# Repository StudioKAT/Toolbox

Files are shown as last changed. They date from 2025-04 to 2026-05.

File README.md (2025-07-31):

# Toolbox

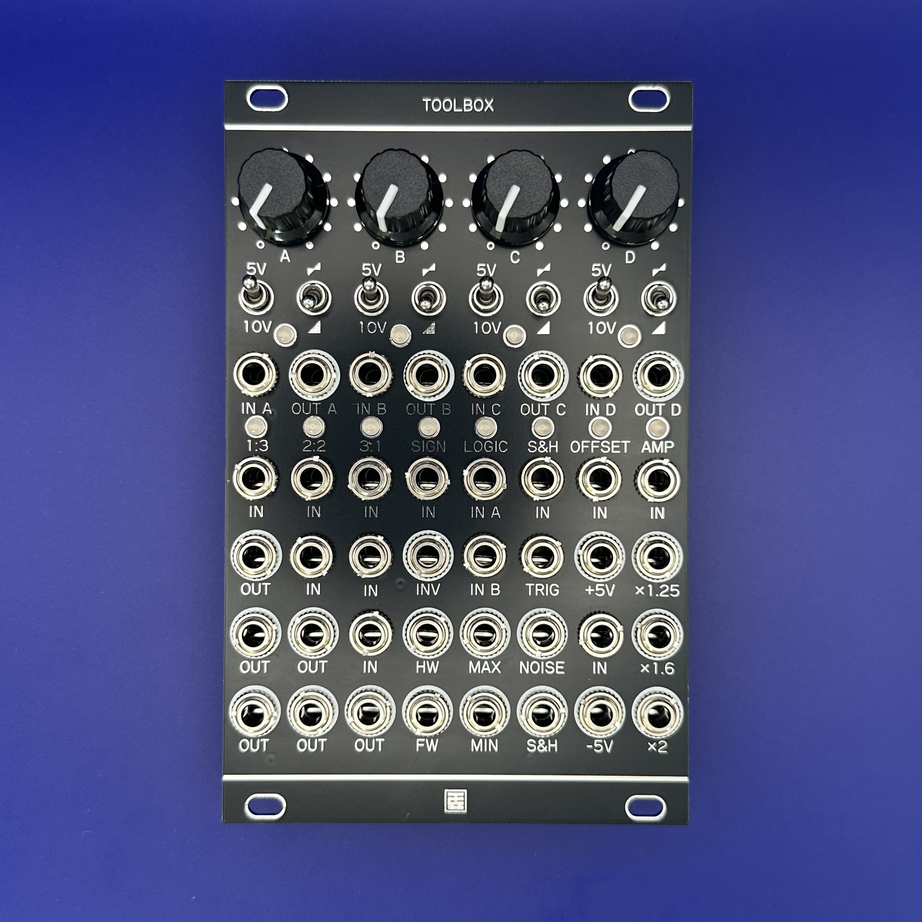
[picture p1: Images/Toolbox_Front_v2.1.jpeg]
Toolbox Front


## 概要 / Overview

**Toolbox** は、16HPサイズの中にモジュラーシンセに必要な多彩なユーティリティ機能を凝縮した多機能ツールボックスモジュールです。  
Mutable Instruments の「Shades」「Links」「Kinks」をベースにしつつ、独自の機能追加を行いました。

主な機能：
- オーディオ/CVミキサー（加算・減算）
- CVへのオフセット追加(5V/10V)・極性反転
- 1:3 バッファード・マルチプル
- 2:2 ユニティミキサー
- 3:1 アベレージミキサー（各チャンネルのゲイン = 1/3）
- SIGNセクション：インバーター / 半波整流 / 全波整流
- LOGICセクション：アナログOR / アナログAND
- S&Hセクション：サンプル＆ホールド / ホワイトノイズ出力
- OFFSET：±5V ↔ 0〜10Vの変換（5Vオフセット）
- AMP：CVやオーディオ信号の増幅  
  - 8V → 10V（x1.25）  
  - 5V → 8V（x1.6）  
  - 5V → 10V（x2）

**Toolbox** is a multifunction utility module that packs a wide range of essential modular synthesis tools into a compact 16HP format.  
It is based on Mutable Instruments' *Shades*, *Links*, and *Kinks*, with several added original features.

Key features include:
- Audio/CV mixer (for both addition and subtraction)
- Offset(5V/10V) and polarity inversion for CV signals
- 1:3 buffered multiple
- 2:2 unity mixer
- 3:1 averaging mixer (each channel gain = 1/3)
- SIGN section: inverter / half-wave rectifier / full-wave rectifier
- LOGIC section: analog OR / analog AND gates
- S&H section: sample & hold circuit / white noise output
- OFFSET: 5V offset converter for ±5V ↔ 0–10V signal conversion
- AMP: amplification of CV and audio signals  
  - 8V → 10V (x1.25)  
  - 5V → 8V (x1.6)  
  - 5V → 10V (x2)

## 仕様 / Spec
- Format: Eurorack
- Function: Multi tools
- Current needs: +12V: 130mA, -12V: 130mA
- Width: 16 HP
- Depth: 25mm (including power connector)

## 販売 / Sales

StudioKATオフィシャルショップで販売しています。(日本国内限定)  
https://www.studiokat.jp/items/106541624

## ライセンス / License

この作品は [Creative Commons 表示 - 継承 4.0 国際 (CC BY-SA 4.0)](https://creativecommons.org/licenses/by-sa/4.0/deed.ja) の下でライセンスされています。  
This work is licensed under the [Creative Commons Attribution-ShareAlike 4.0 International License](https://creativecommons.org/licenses/by-sa/4.0/).

## クレジット / Credits

- Designed by : StudioKAT
- Website : https://www.studiokat.jp/
- GitHub : https://github.com/StudioKAT
- X(Twitter) : https://x.com/StudioKAT_synth
- Instagram : https://www.instagram.com/studiokat_modular/

## 更新履歴 / Changelog

- `2025-05-28` v1.0 Released 
- `2025-07-31` v2.1 Released  
オペアンプ変更、ホワイトノイズ切り替え機能追加、リファレンス電源回路変更

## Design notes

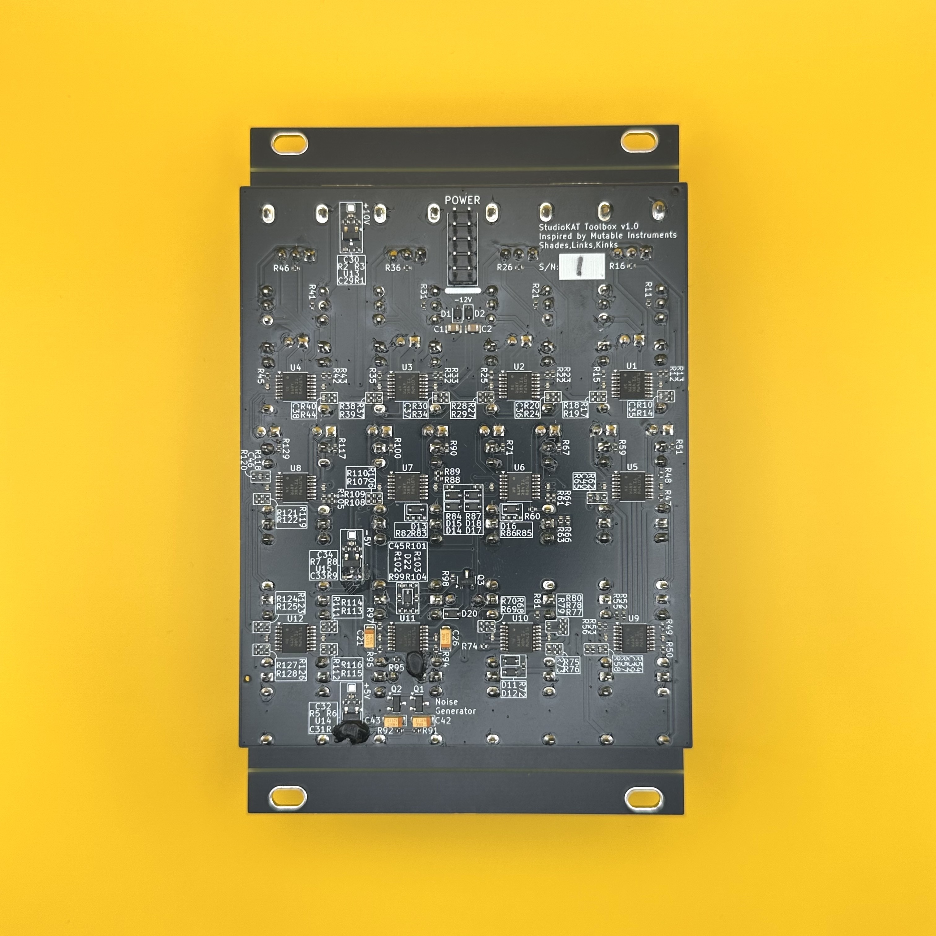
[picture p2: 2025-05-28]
Images/Toolbox_Back.jpeg

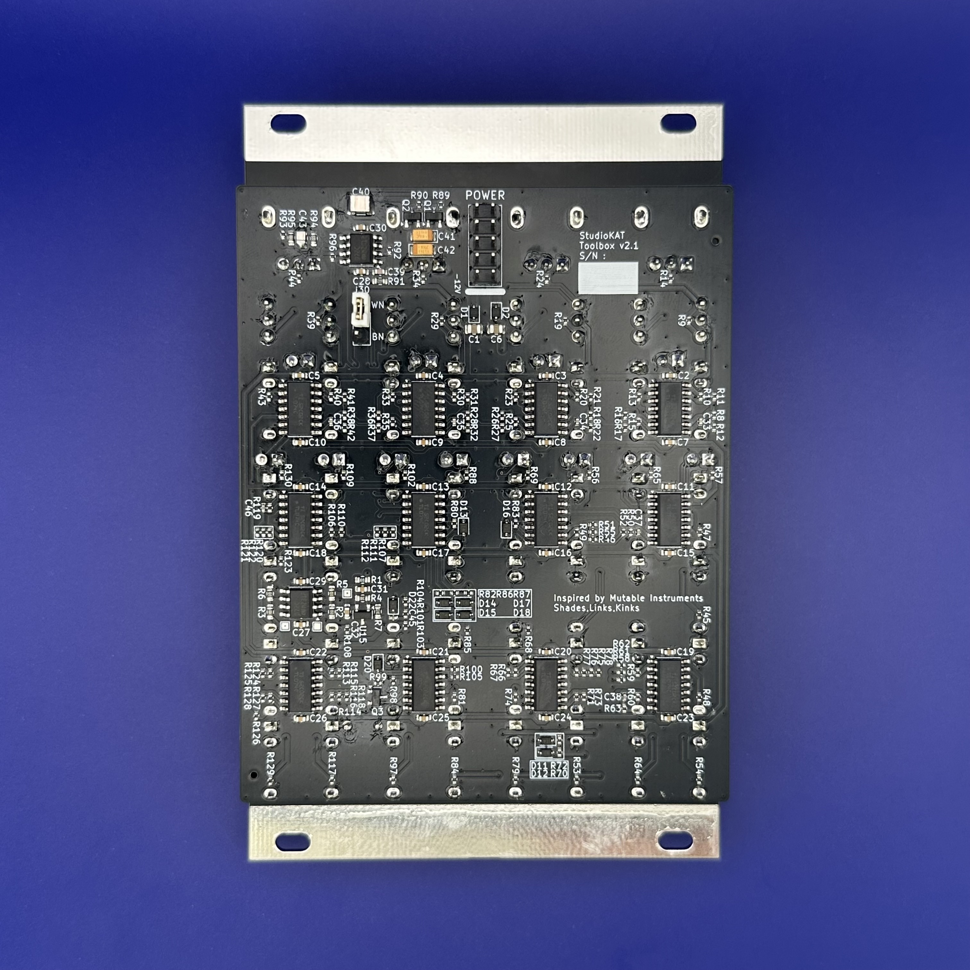
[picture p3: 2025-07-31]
Images/Toolbox_Back_v2.1.jpeg

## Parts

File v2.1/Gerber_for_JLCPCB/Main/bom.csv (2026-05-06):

Designator | Footprint | Quantity | Value | LCSC Part #
C1, C6 | 0805 | 2 | 22uF | C45783
C10, C11, C12, C13, C14, C15, C16, C17, C18, C19, C2, C20, C21, C22, C23, C24, C25, C26, C27, C28, C29, C3, C30, C31, C32, C4, C5, C7, C8, C9 | 0603 | 30 | 100nF | C14663
C33, C34, C35, C36 | 0402 | 4 | 22p | C1555
C37, C38, C46 | 0402 | 3 | 10p | C32949
C39 | 0603 | 1 | 22pF | C1653
C40 | 1210 | 1 | 0.1uF/16V
C41, C42 | CP_EIA-3216-18_Kemet-A | 2 | 10u | C7171
C43 | 0805 | 1 | 0.01uF/16V
C44 | C_Rect_L7.2mm_W2.5mm_P5.00mm_FKS2_FKP2_MKS2_MKP2 | 1 | 10n
C45 | 0402 | 1 | 100p | C1546
D1, D2 | D_SOD-323 | 2 | 1N5819WS | C64886
D10, D19, D21, D23, D24, D3, D4, D5, D6, D7, D8, D9 | LED_D3.0mm | 12 | LED_Dual_Bidirectional
D11, D12, D13, D14, D15, D16, D17, D18, D20, D22 | D_SOD-323 | 10 | 1N4148WS | C2128
J1 | PinHeader_2x05_2.54mm_Europower | 1 | POWER
J10 | AudioJack_PJ301M-12 | 1 | Links_1to3_OUT1
J11 | AudioJack_PJ301M-12 | 1 | Links_1to3_IN
J12 | AudioJack_PJ301M-12 | 1 | Links_3to1_IN1
J13 | AudioJack_PJ301M-12 | 1 | Links_1to3_OUT2
J14 | AudioJack_PJ301M-12 | 1 | Links_3to1_IN2
J15 | AudioJack_PJ301M-12 | 1 | Links_3to1_OUT
J16 | AudioJack_PJ301M-12 | 1 | Links_1to3_OUT3
J17 | AudioJack_PJ301M-12 | 1 | Links_3to1_IN3
J18 | AudioJack_PJ301M-12 | 1 | Links_2to2_IN1
J19 | AudioJack_PJ301M-12 | 1 | Links_2to2_IN2
J2 | AudioJack_PJ301M-12 | 1 | OUT_1
J20 | AudioJack_PJ301M-12 | 1 | Links_2to2_OUT1
J21 | AudioJack_PJ301M-12 | 1 | Links_2to2_OUT2
J22 | AudioJack_PJ301M-12 | 1 | Kinks_IN
J23 | AudioJack_PJ301M-12 | 1 | Kinks_OUT_INV
J24 | AudioJack_PJ301M-12 | 1 | Kinks_OUT_HW
J25 | AudioJack_PJ301M-12 | 1 | Kinks_OUT_FW
J26 | AudioJack_PJ301M-12 | 1 | Kinks_OUT_MAX
J27 | AudioJack_PJ301M-12 | 1 | Kinks_IN_A
J28 | AudioJack_PJ301M-12 | 1 | Kinks_IN_B
J29 | AudioJack_PJ301M-12 | 1 | Kinks_OUT_MIN
J3 | AudioJack_PJ301M-12 | 1 | IN_1
J30 | PinHeader_1x03_P2.54mm_Vertical | 1 | Jumper
J31 | AudioJack_PJ301M-12 | 1 | Kinks_OUT_Noise
J32 | AudioJack_PJ301M-12 | 1 | Kinks_OUT_S&H
J33 | AudioJack_PJ301M-12 | 1 | Kinks_S&H_IN
J34 | AudioJack_PJ301M-12 | 1 | Kinks_S&H_TRIG
J35 | AudioJack_PJ301M-12 | 1 | OUT_+10V
J36 | AudioJack_PJ301M-12 | 1 | IN_±5V
J37 | AudioJack_PJ301M-12 | 1 | IN_+10V
J38 | AudioJack_PJ301M-12 | 1 | OUT_±5V
J39 | AudioJack_PJ301M-12 | 1 | IN
J4 | AudioJack_PJ301M-12 | 1 | OUT_2
J40 | AudioJack_PJ301M-12 | 1 | OUT_x1.25
J41 | AudioJack_PJ301M-12 | 1 | OUT_x1.6
J42 | AudioJack_PJ301M-12 | 1 | OUT_x2
J5 | AudioJack_PJ301M-12 | 1 | IN_2
J6 | AudioJack_PJ301M-12 | 1 | OUT_3
J7 | AudioJack_PJ301M-12 | 1 | IN_3
J8 | AudioJack_PJ301M-12 | 1 | OUT_4
J9 | AudioJack_PJ301M-12 | 1 | IN_4
Q1, Q2 | SOT-23 | 2 | 2SC1815 | C20069143
Q3 | SOT-23 | 1 | MMBFJ310 | C33416
R1 | 0603 | 1 | 1K | C21190
R10, R103, R104, R106, R107, R11, R110, R111, R112, R113, R114, R115, R116, R118, R119, R121, R127, R14, R15, R16, R17, R18, R19, R20, R21, R24, R25, R26, R27, R28, R29, R30, R31, R34, R35, R36, R37, R38, R39, R40, R41, R44, R46, R50, R51, R52, R55, R58, R59, R60, R61, R62, R70, R73, R75, R76, R8, R9, R92 | 0402 | 59 | 100K | C25741
R100, R86, R87, R98, R99 | 0402 | 5 | 1M | C26083
R101, R105 | 0402 | 2 | 10K | C25744
R102, R109, R12, R13, R130, R22, R23, R32, R33, R42, R43, R56, R57, R65, R69, R88 | 0402 | 16 | 1K | C11702
R108, R117, R123, R126, R129, R45, R48, R53, R54, R63, R64, R68, R74, R79, R81, R84, R93, R96, R97 | 0402 | 19 | 100R | C25076
R120 | 0402 | 1 | 150K | C25755
R122, R124 | 0402 | 2 | 120K | C25750
R125 | 0402 | 1 | 75K | C25798
R128 | 0402 | 1 | 49.9K | C25897
R2, R5, R6 | 0603 | 3 | 100K | C25803
R3, R91 | 0603 | 2 | 200K | C25811
R4, R7 | 0603 | 2 | 10K | C25804
R47 | 0402 | 1 | 10M | C26082
R49 | 0402 | 1 | 33K | C25779
R66, R67, R71, R72, R77, R78 | 0402 | 6 | 200K | C25764
R80, R82, R83, R85 | 0402 | 4 | 220K | C25767
R89 | 0402 | 1 | 470K | C25790
R90 | 0402 | 1 | 4.7K | C25900
R94 | 0603 | 1 | 2.2K | C4190
R95 | 0603 | 1 | 2K | C22975
RV1, RV2, RV3, RV4 | Potentiometer_RV09 | 4 | B10K
SW1, SW2, SW3, SW4, SW5, SW6, SW7, SW8 | ToggleSwitch_2MS1-T2-B4-M2-Q-E-S | 8 | SW_SPDT
TP1 | TestPoint_Pad_1.0x1.0mm | 1 | +5V_TP
TP2 | TestPoint_Pad_1.0x1.0mm | 1 | -5V_TP
TP3 | TestPoint_Pad_1.0x1.0mm | 1 | +10V_TP
U1, U10, U11, U12, U2, U3, U4, U5, U6, U7, U8, U9 | SOIC-14_3.9x8.7mm_P1.27mm | 12 | TL074CDR | C12594
U13, U14 | SOIC-8_3.9x4.9mm_P1.27mm | 2 | TL072CDT | C6961
U15 | SOT-23 | 1 | CJ431 | C3113

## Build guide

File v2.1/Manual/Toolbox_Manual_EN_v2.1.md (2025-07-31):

# Toolbox Manual (English)

Toolbox Front

## Overview

**Toolbox** is a multi-functional utility module packed into a 16HP Eurorack format.  
Inspired by Mutable Instruments' "Shades", "Links", and "Kinks", this module adds original functionality and extends utility capabilities for both audio and CV.

### Key Features:
- Audio/CV mixer (sum/subtract)  
- CV offset generator (+5V/+10V), polarity inversion  
- 1:3 buffered multiple  
- 2:2 unity mixer  
- 3:1 average mixer (each input gain = 1/3)  
- SIGN section: inverter / half-wave rectifier / full-wave rectifier  
- LOGIC section: analog OR / analog AND  
- S&H section: sample & hold / white noise generator  
- OFFSET section: ±5V ↔ 0–10V converter (±5V shift)  
- AMP section: CV or audio gain boost for envelope scaling

---

## Specifications

- **Format**: Eurorack  
- **Width**: 16 HP  
- **Depth**: 25 mm  
- **Power Consumption**: +12V: 130mA / -12V: 130mA  

> **IMPORTANT**: Connect the ribbon cable with the red stripe aligned to -12V.  
> Incorrect connection can permanently damage the module.  
> **Always check cable orientation before powering on.**

---

## Functional Sections

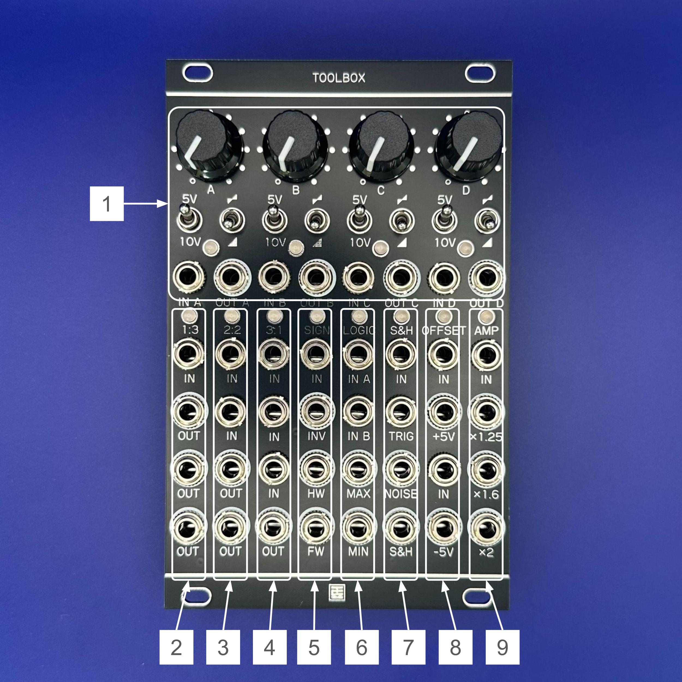
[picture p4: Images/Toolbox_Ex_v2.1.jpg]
explanation


1. **Attenuator / Offset / Mixer**  
   4-channel audio/CV mixer and attenuator section.  
   Normalized to +5V or +10V when no input is patched (switchable).  
   Each channel can be switched between attenuator and attenuverter modes.  
   Outputs are internally daisy-chained.

2. **1:3**  
   1 input, 3 output buffered multiple.

3. **2:2**  
   Unity gain mixer: two inputs are summed and distributed to two outputs.

4. **3:1**  
   3-input average mixer with 1/3 gain per channel—ideal for mixing hot oscillator signals to prevent clipping.

5. **SIGN**  
   Signal inverter and wave rectification section.  
   Provides half-wave and full-wave rectification, including 0V clipping and phase inversion of negative voltages.

6. **LOGIC**  
   Outputs the maximum (analog OR) and minimum (analog AND) of two input voltages.

7. **S&H**  
   When a trigger is received at TRIG IN, the voltage at IN is sampled and held at the output.  
   Internally normalized to white noise for random voltage generation.  
   The NOISE OUT provides continuous white noise independent from the S&H output.

8. **OFFSET**  
   Top: adds +5V to the input signal  
   Bottom: subtracts 5V from the input signal  
   Useful for converting ±5V pitch signals to 0–10V (e.g., Moog).

9. **AMP**  
   Amplifies CV or audio signals to scale envelope voltages.  
   Preset gain ratios:  
   - 8V → 10V (×1.25)  
   - 5V → 8V (×1.6)  
   - 5V → 10V (×2)

---

> All LEDs light up **green** for positive output and **red** for negative output.

---

### v2.1 Update
You can select the type of noise used in the Sample & Hold (S&H) section via the jumper located on the back panel.
- Upper position: White noise (default)
- Lower position: Blue noise (brighter tonal character)
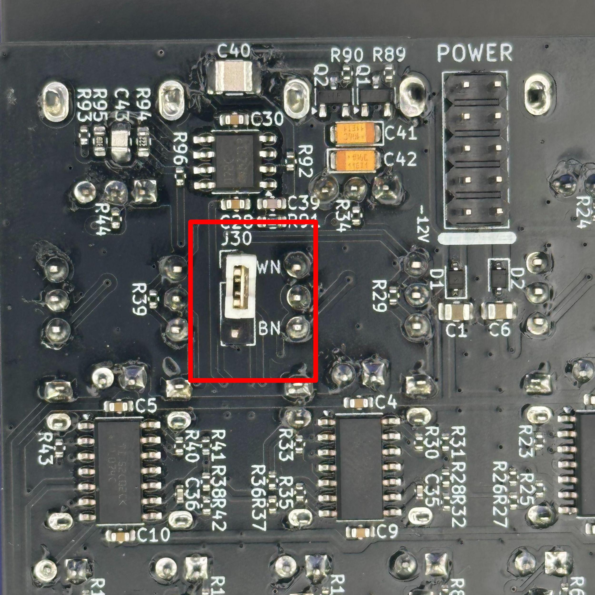
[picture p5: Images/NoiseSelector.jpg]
NoiseSelector


## License

This work is licensed under a [Creative Commons Attribution-ShareAlike 4.0 International License (CC BY-SA 4.0)](https://creativecommons.org/licenses/by-sa/4.0/).

---

## Credits

- **Designed by**: StudioKAT  
- **Website**: [https://www.studiokat.jp/](https://www.studiokat.jp/)  
- **GitHub**: [https://github.com/StudioKAT](https://github.com/StudioKAT)  
- **X (Twitter)**: [https://x.com/StudioKAT_synth](https://x.com/StudioKAT_synth)  
- **Instagram**: [https://www.instagram.com/studiokat_modular/](https://www.instagram.com/studiokat_modular/)

---

## Changelog

- `2025-05-28`: v1.0 Released

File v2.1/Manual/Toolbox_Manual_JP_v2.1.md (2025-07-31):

# Toolbox マニュアル（日本語）

Toolbox Front

## 概要

**Toolbox** は、16HPの中にモジュラーシンセに必要な多彩なユーティリティ機能を凝縮した多機能ツールボックスモジュールです。  
Mutable Instruments の「Shades」「Links」「Kinks」をベースに、独自の機能追加が施されています。

### 主な機能：
- オーディオ／CVミキサー（加算・減算）  
- CVへのオフセット追加（5V／10V）、極性反転  
- 1:3 バッファード・マルチプル  
- 2:2 ユニティミキサー  
- 3:1 アベレージミキサー（各チャンネルのゲイン = 1/3）  
- SIGNセクション：インバーター／半波整流／全波整流  
- LOGICセクション：アナログOR／アナログAND  
- S&Hセクション：サンプル＆ホールド／ホワイトノイズ出力  
- OFFSET：±5V ↔ 0〜10V 変換（5Vオフセット）  
- AMP：CVやオーディオ信号の電圧拡張

---

## 仕様

- **フォーマット**：Eurorack  
- **幅**：16 HP  
- **奥行き**：25 mm  
- **消費電流**：+12V: 130mA / -12V: 130mA  

> ※ ケーブルの赤いラインが -12V に接続されていることを確認してください。  
> 誤接続するとモジュールが故障する可能性があります。  
> **電源投入前にケーブルの向きを必ずご確認ください。**

---

## 各部の機能

explanation

1. **Attenuator / Offset / Mixer**  
   4チャンネルのCV／オーディオ信号を処理できるミキサー・アッテネーターです。  
   未接続時には+5Vまたは+10Vがノーマライズされ、固定電圧出力として使用可能。切替スイッチ付き。  
   スイッチでアッテネーター／アッテヌバーターの切替も可能。  
   出力は内部的にデイジーチェーン接続されています。

2. **1:3**  
   バッファー付きの1入力3出力マルチプルです。

3. **2:2**  
   2入力の加算結果を2つのアウトへ出力するユニティゲインミキサーです。

4. **3:1**  
   各入力のゲインを1/3に設定した3入力ミキサーです。  
   オシレーターなど、クリッピングしやすい信号のミキシングに適しています。

5. **SIGN**  
   信号インバーターと半波／全波整流器のセクションです。  
   信号を0Vでクリップ、もしくは負電圧成分を反転する処理を行います。

6. **LOGIC**  
   入力された2信号の最大値（アナログOR）および最小値（アナログAND）を出力します。

7. **S&H**  
   トリガー信号が入力されるたびにINの電圧をサンプルし、保持して出力します。  
   INには内部的にホワイトノイズがノーマライズされています。  
   NOISE OUTはS&Hとは独立したノイズ出力として使用できます。

8. **OFFSET**  
   上段：入力信号に+5Vを加算  
   下段：入力信号から5Vを減算  
   Moogの±5Vピッチ信号を0～10Vへ変換するなどの用途に便利です。

9. **AMP**  
   CVまたはオーディオ信号を一定倍率で増幅します。  
   エンベロープ電圧変換に最適な倍率設定：  
   - 8V → 10V（×1.25）  
   - 5V → 8V（×1.6）  
   - 5V → 10V（×2）

---

> すべてのLEDは、出力がプラスの場合は緑、マイナスの場合は赤に点灯します。

---

### v2.1 Update
背面のジャンパーピンで、S&H（サンプル＆ホールド）セクションに使用するノイズの種類を選択できます。
- 上側：ホワイトノイズ（デフォルト）
- 下側：ブルーノイズ（より明るい音色のノイズ）
NoiseSelector

## ライセンス

この作品は [Creative Commons 表示 - 継承 4.0 国際 (CC BY-SA 4.0)](https://creativecommons.org/licenses/by-sa/4.0/deed.ja) の下でライセンスされています。

---

## クレジット

- **Designed by**：StudioKAT  
- **Website**：[https://www.studiokat.jp/](https://www.studiokat.jp/)  
- **GitHub**：[https://github.com/StudioKAT](https://github.com/StudioKAT)  
- **X（旧Twitter）**：[https://x.com/StudioKAT_synth](https://x.com/StudioKAT_synth)  
- **Instagram**：[https://www.instagram.com/studiokat_modular/](https://www.instagram.com/studiokat_modular/)

---

## 更新履歴

- `2025-05-28`：v1.0 リリース  
- `2025-07-31`：v2.1 リリース

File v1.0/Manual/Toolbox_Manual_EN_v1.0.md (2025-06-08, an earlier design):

# Toolbox Manual (English)

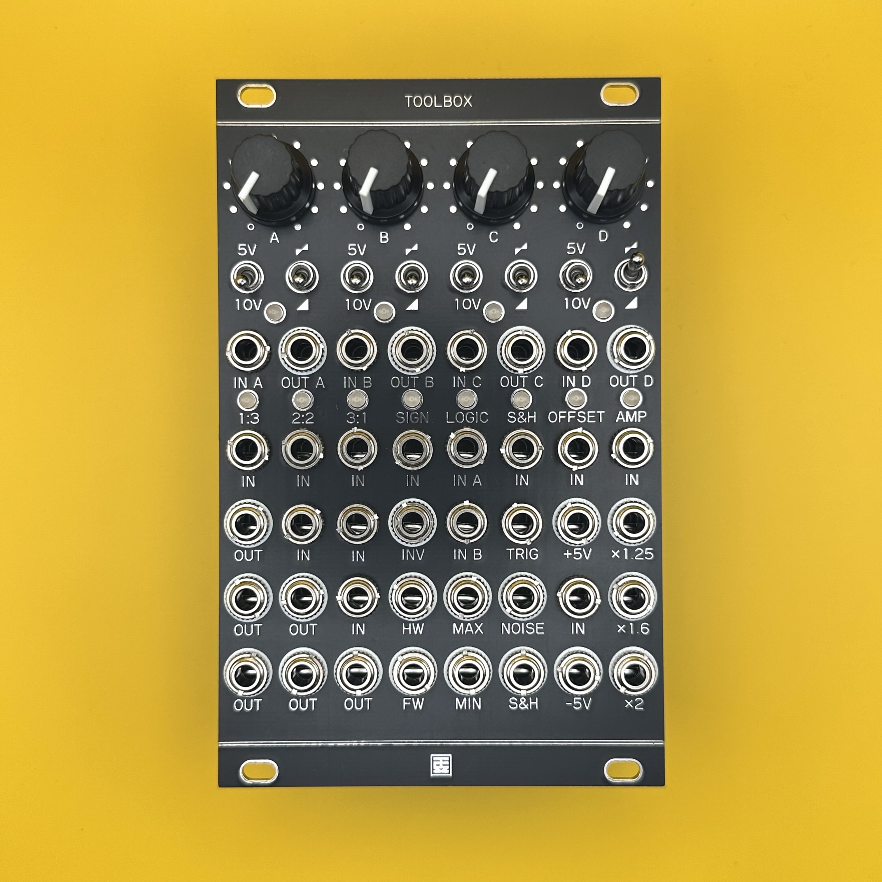
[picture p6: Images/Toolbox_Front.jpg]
Toolbox Front


## Overview

**Toolbox** is a multi-functional utility module packed into a 16HP Eurorack format.  
Inspired by Mutable Instruments' "Shades", "Links", and "Kinks", this module adds original functionality and extends utility capabilities for both audio and CV.

### Key Features:
- Audio/CV mixer (sum/subtract)  
- CV offset generator (+5V/+10V), polarity inversion  
- 1:3 buffered multiple  
- 2:2 unity mixer  
- 3:1 average mixer (each input gain = 1/3)  
- SIGN section: inverter / half-wave rectifier / full-wave rectifier  
- LOGIC section: analog OR / analog AND  
- S&H section: sample & hold / white noise generator  
- OFFSET section: ±5V ↔ 0–10V converter (±5V shift)  
- AMP section: CV or audio gain boost for envelope scaling

---

## Specifications

- **Format**: Eurorack  
- **Width**: 16 HP  
- **Depth**: 25 mm  
- **Power Consumption**: +12V: 160mA / -12V: 160mA  

> **IMPORTANT**: Connect the ribbon cable with the red stripe aligned to -12V.  
> Incorrect connection can permanently damage the module.  
> **Always check cable orientation before powering on.**

---

## Functional Sections

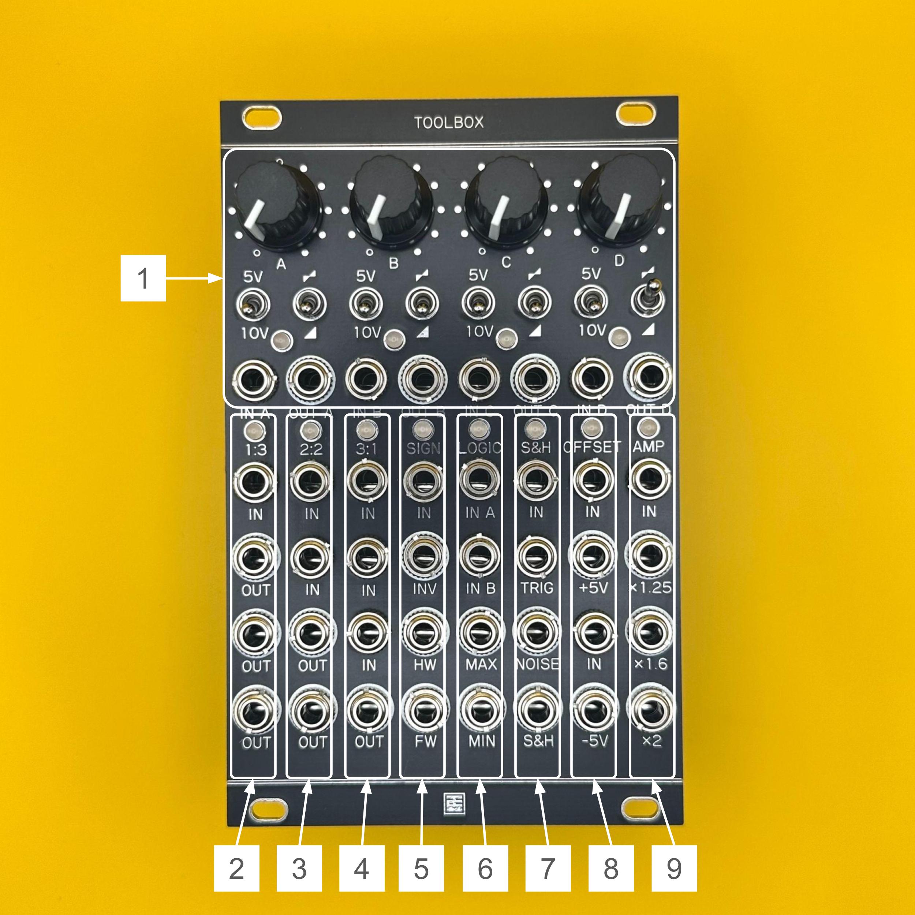
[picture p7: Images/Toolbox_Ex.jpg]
explanation


1. **Attenuator / Offset / Mixer**  
   4-channel audio/CV mixer and attenuator section.  
   Normalized to +5V or +10V when no input is patched (switchable).  
   Each channel can be switched between attenuator and attenuverter modes.  
   Outputs are internally daisy-chained.

2. **1:3**  
   1 input, 3 output buffered multiple.

3. **2:2**  
   Unity gain mixer: two inputs are summed and distributed to two outputs.

4. **3:1**  
   3-input average mixer with 1/3 gain per channel—ideal for mixing hot oscillator signals to prevent clipping.

5. **SIGN**  
   Signal inverter and wave rectification section.  
   Provides half-wave and full-wave rectification, including 0V clipping and phase inversion of negative voltages.

6. **LOGIC**  
   Outputs the maximum (analog OR) and minimum (analog AND) of two input voltages.

7. **S&H**  
   When a trigger is received at TRIG IN, the voltage at IN is sampled and held at the output.  
   Internally normalized to white noise for random voltage generation.  
   The NOISE OUT provides continuous white noise independent from the S&H output.

8. **OFFSET**  
   Top: adds +5V to the input signal  
   Bottom: subtracts 5V from the input signal  
   Useful for converting ±5V pitch signals to 0–10V (e.g., Moog).

9. **AMP**  
   Amplifies CV or audio signals to scale envelope voltages.  
   Preset gain ratios:  
   - 8V → 10V (×1.25)  
   - 5V → 8V (×1.6)  
   - 5V → 10V (×2)

---

> All LEDs light up **green** for positive output and **red** for negative output.

---

## License

This work is licensed under a [Creative Commons Attribution-ShareAlike 4.0 International License (CC BY-SA 4.0)](https://creativecommons.org/licenses/by-sa/4.0/).

---

## Credits

- **Designed by**: StudioKAT  
- **Website**: [https://www.studiokat.jp/](https://www.studiokat.jp/)  
- **GitHub**: [https://github.com/StudioKAT](https://github.com/StudioKAT)  
- **X (Twitter)**: [https://x.com/StudioKAT_synth](https://x.com/StudioKAT_synth)  
- **Instagram**: [https://www.instagram.com/studiokat_modular/](https://www.instagram.com/studiokat_modular/)

---

## Changelog

- `2025-05-28`: v1.0 Released

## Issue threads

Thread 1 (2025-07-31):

[Toolbox] CJ431 5V shunt regulators are getting VERY hot

KeLaiFu, 2025-07-31:
I've built the beautiful Toolbox module, using the same assembly files posted in the repository and upon test, the 2 5v CJ431's are getting very hot, very fast.
I havn't fully tested the module as I am afraid they will burn out given enough time, but the 5V test points both give the correct voltage and a few other things I have quickly tested seem to be working, so other than the hot regulators, so far it seems to be working.

StudioKAT, 2025-07-31:
I'm aware of the heat issue with the CJ431s. In the production version, I addressed this by changing resistors R1, R4, and R9 from 100Ω to 1kΩ.
Only the KiCAD project had been updated—I had forgotten to update the Gerber files accordingly.
I've now replaced the affected files.

Closed 2025-07-31.

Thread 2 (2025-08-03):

[toolbox] v1 Kink S&H LED is always lit

KeLaiFu, 2025-08-03:
Thanks for responding to my previous issue, I switched out the resistors and the problem went away thankfully

However, as I continue the assembly I noticed that the light for the Kinks S&H circuit is permanently Illuminated.

I don't think this is normal, so could you advise me on what could be causing this?

Thanks again

Closed 2025-08-09.

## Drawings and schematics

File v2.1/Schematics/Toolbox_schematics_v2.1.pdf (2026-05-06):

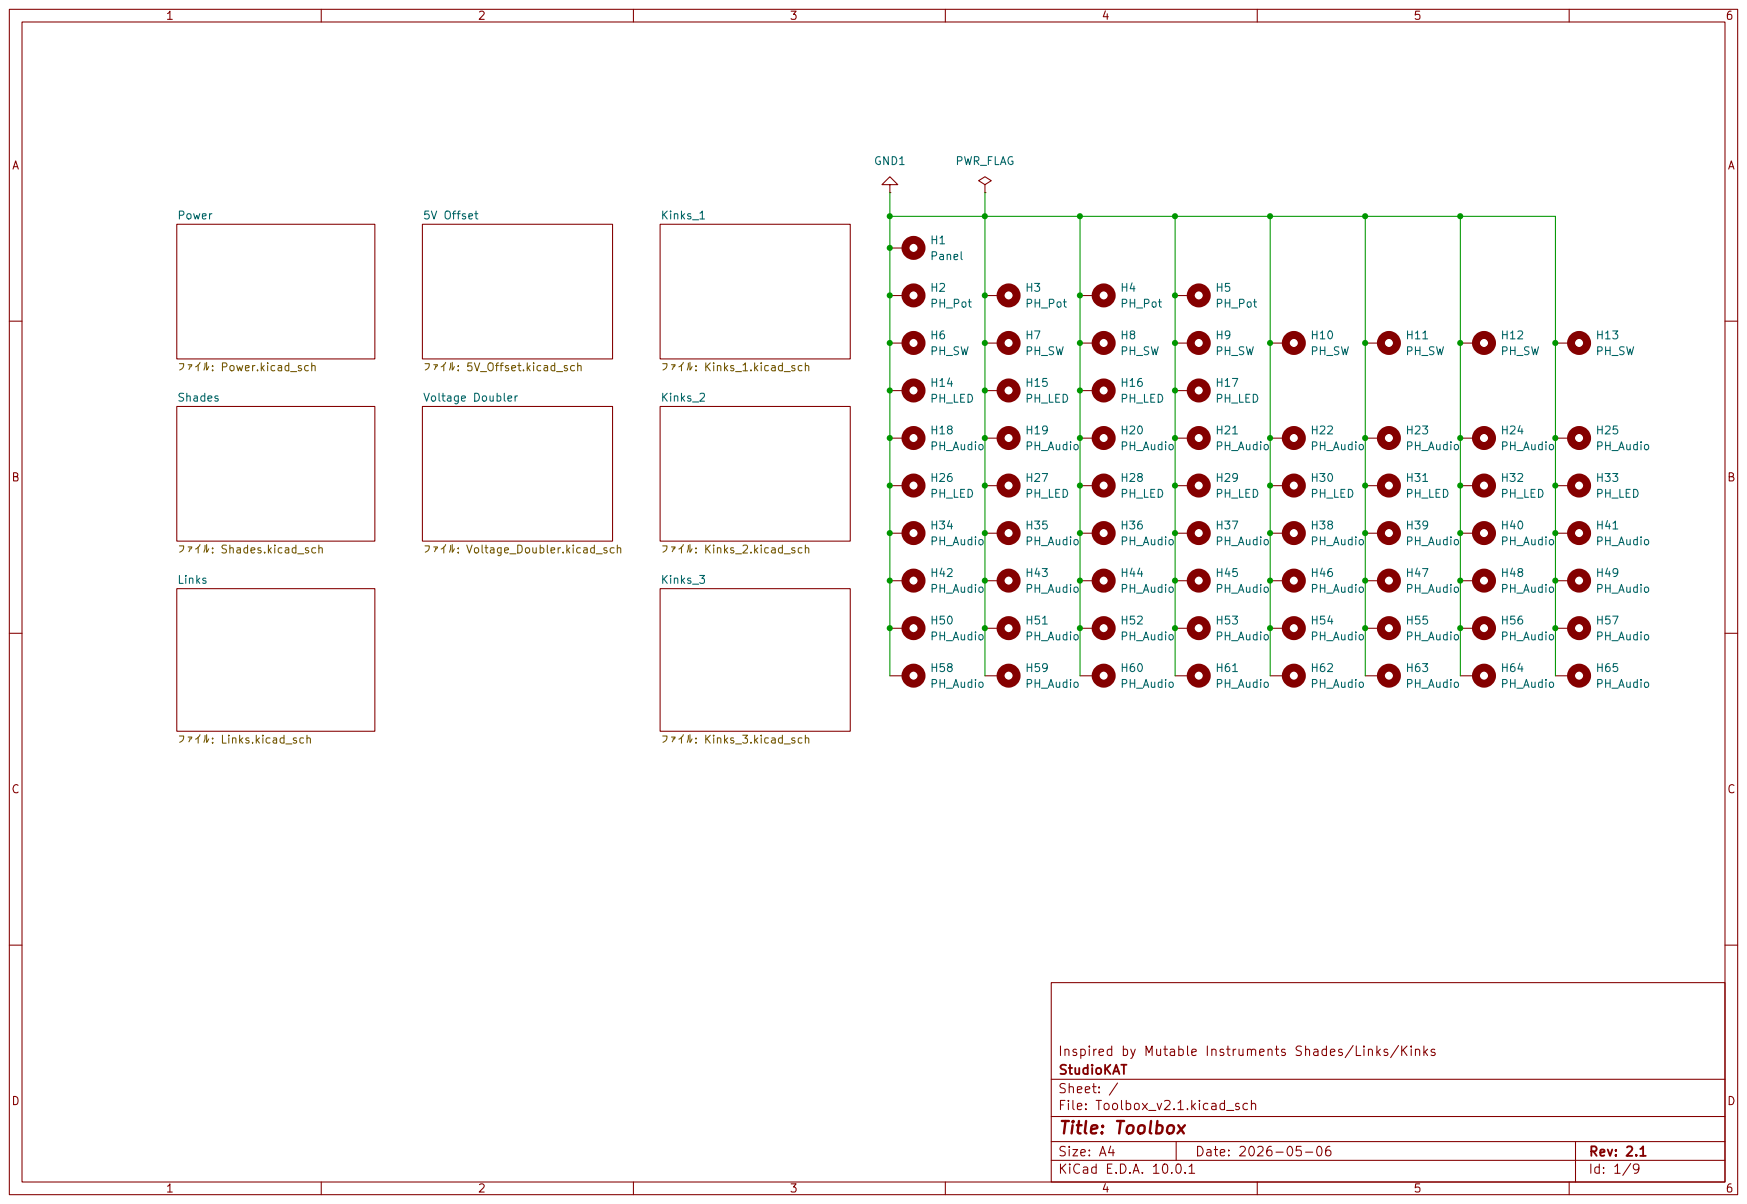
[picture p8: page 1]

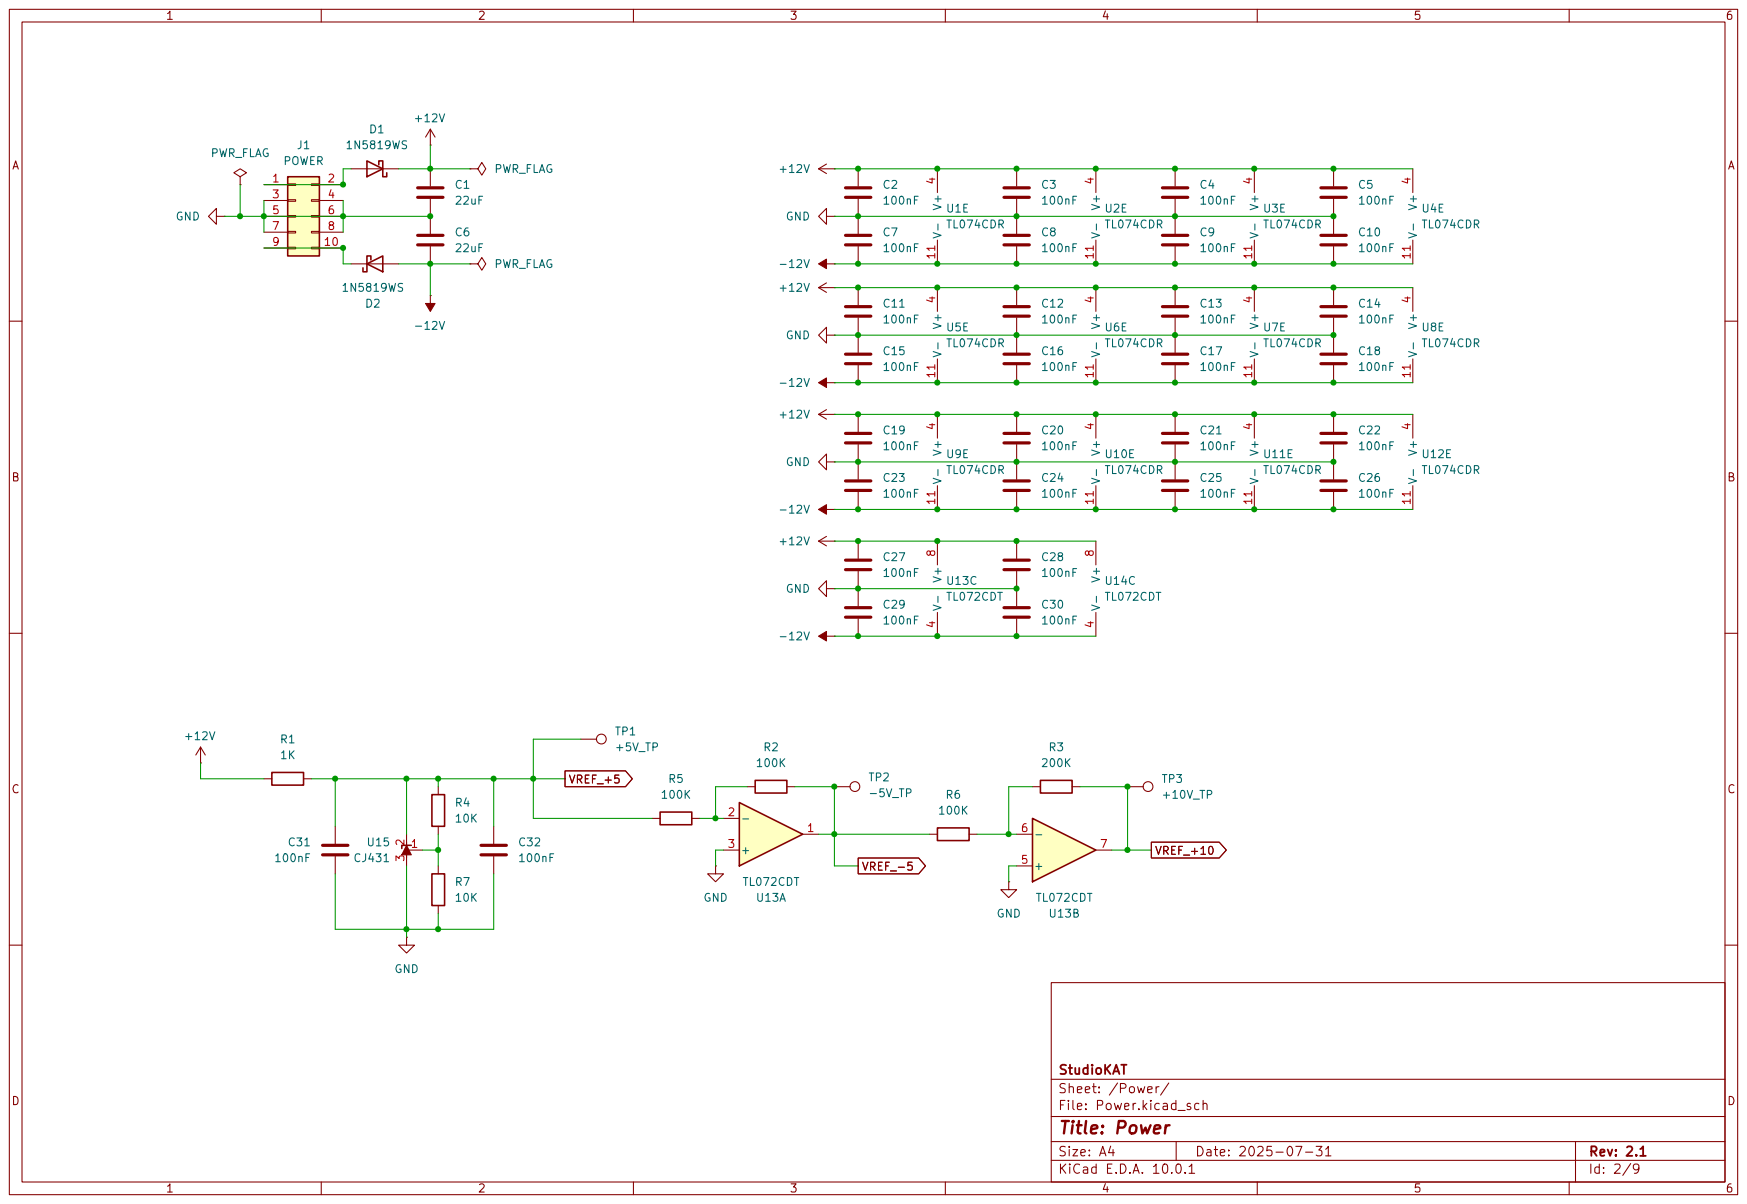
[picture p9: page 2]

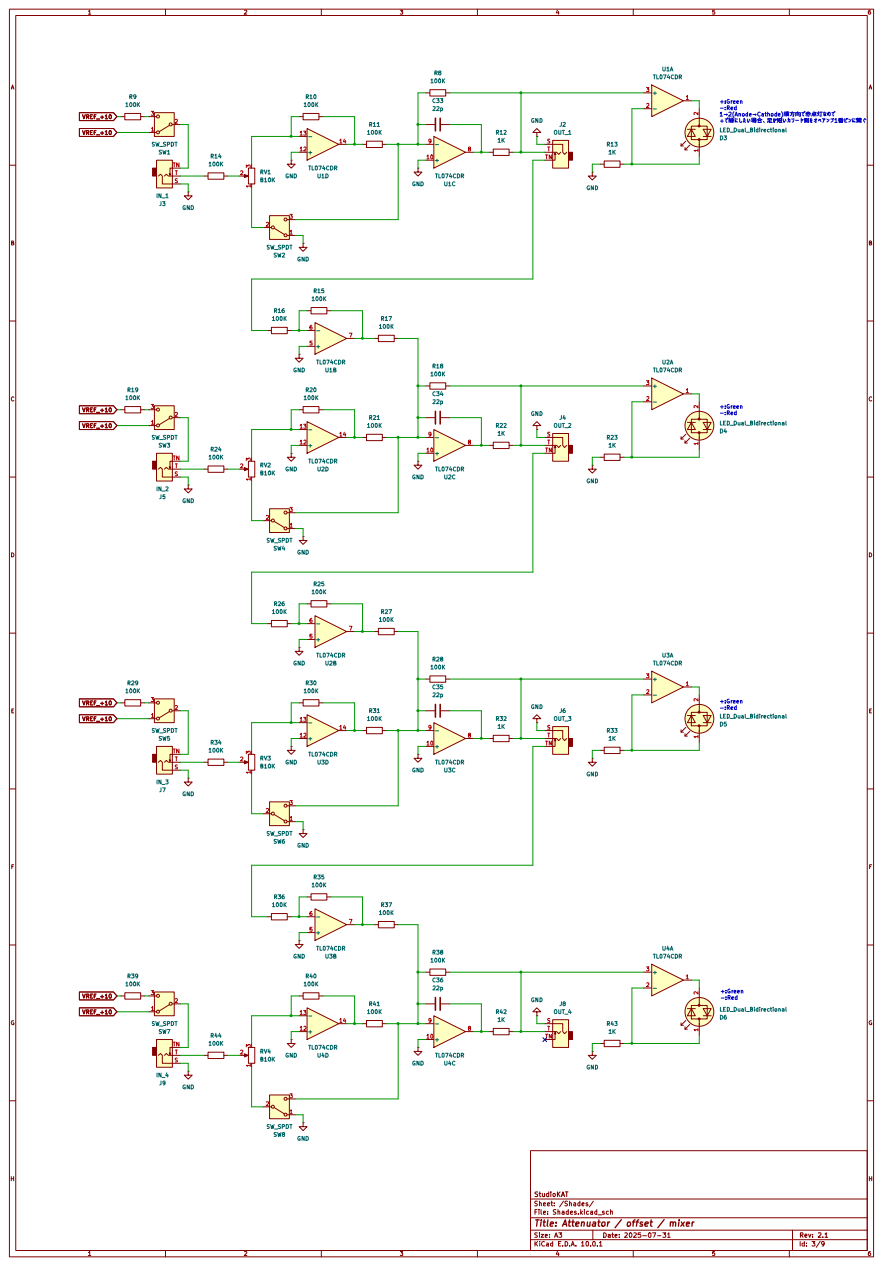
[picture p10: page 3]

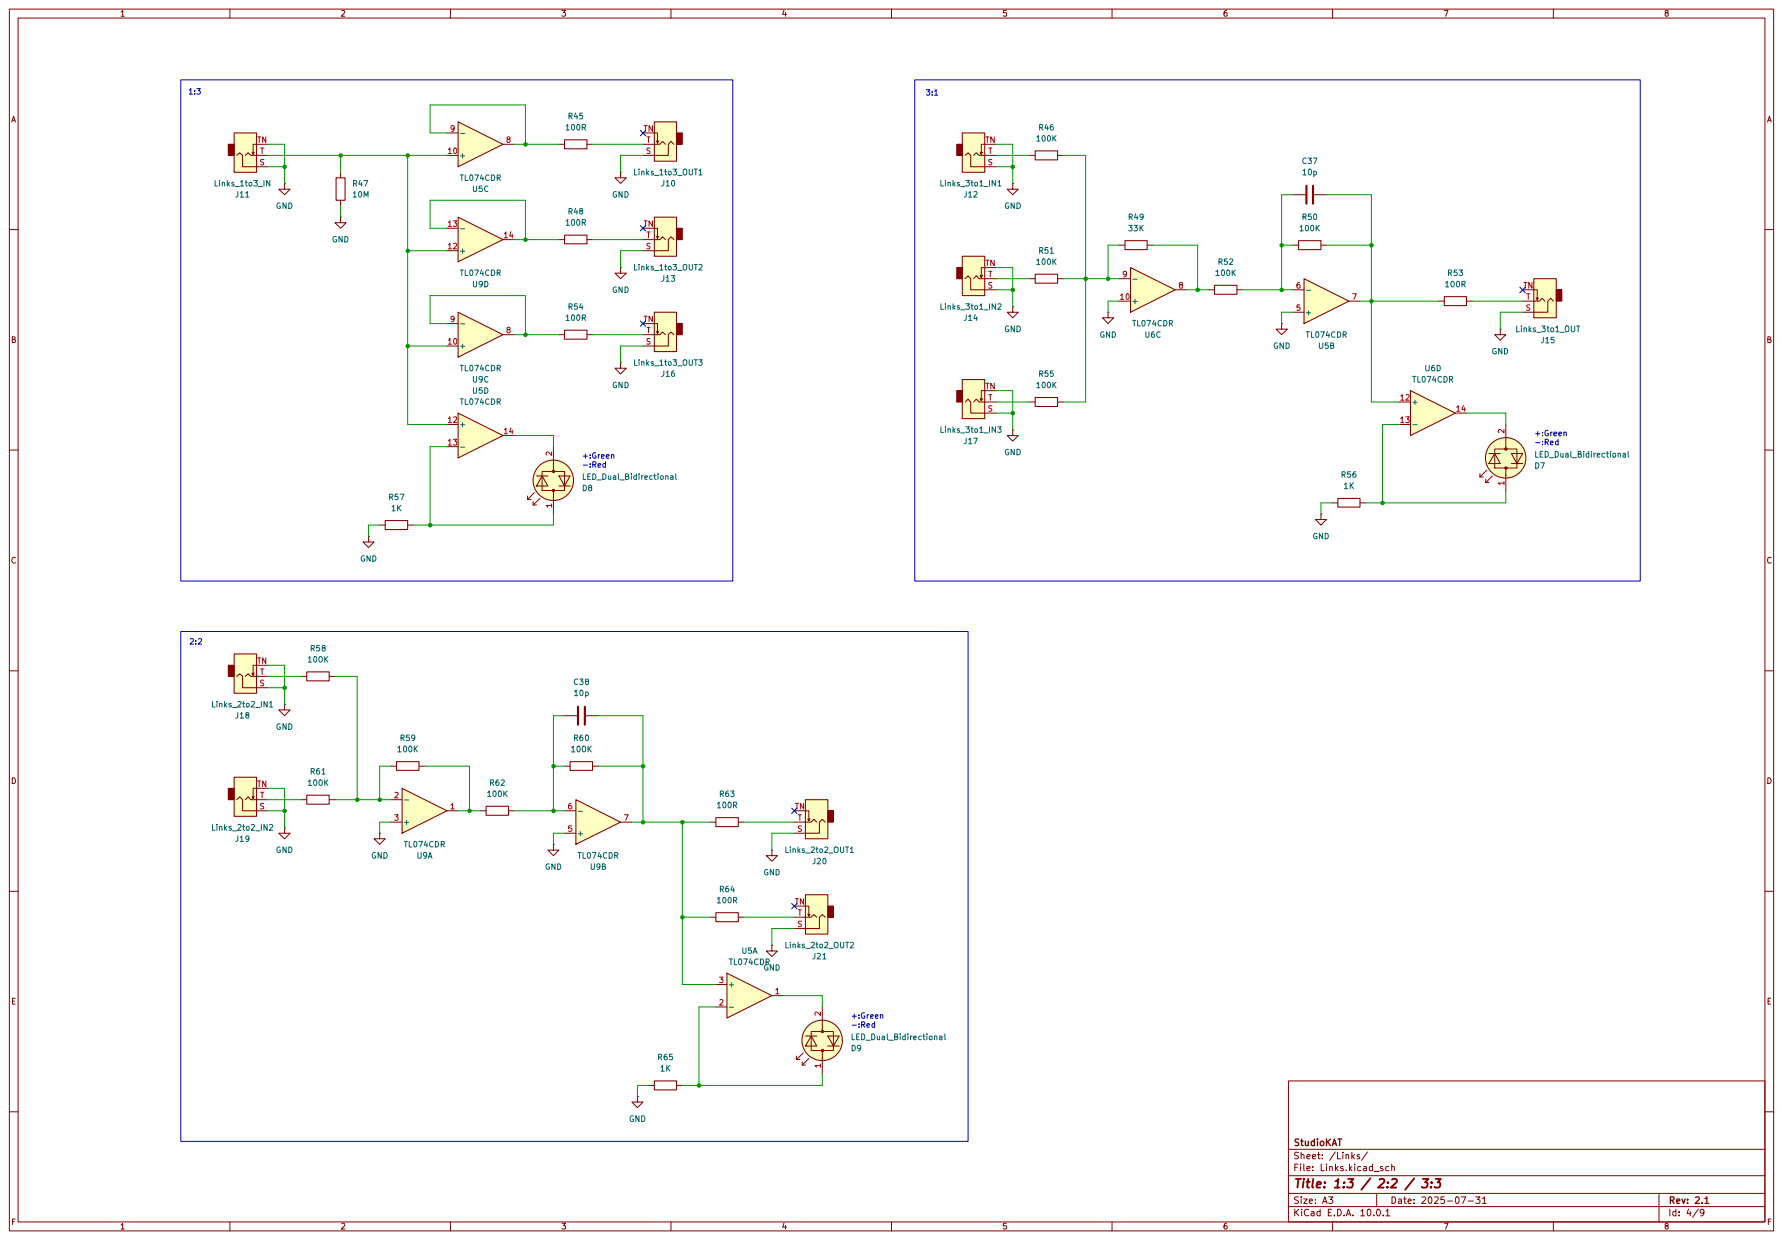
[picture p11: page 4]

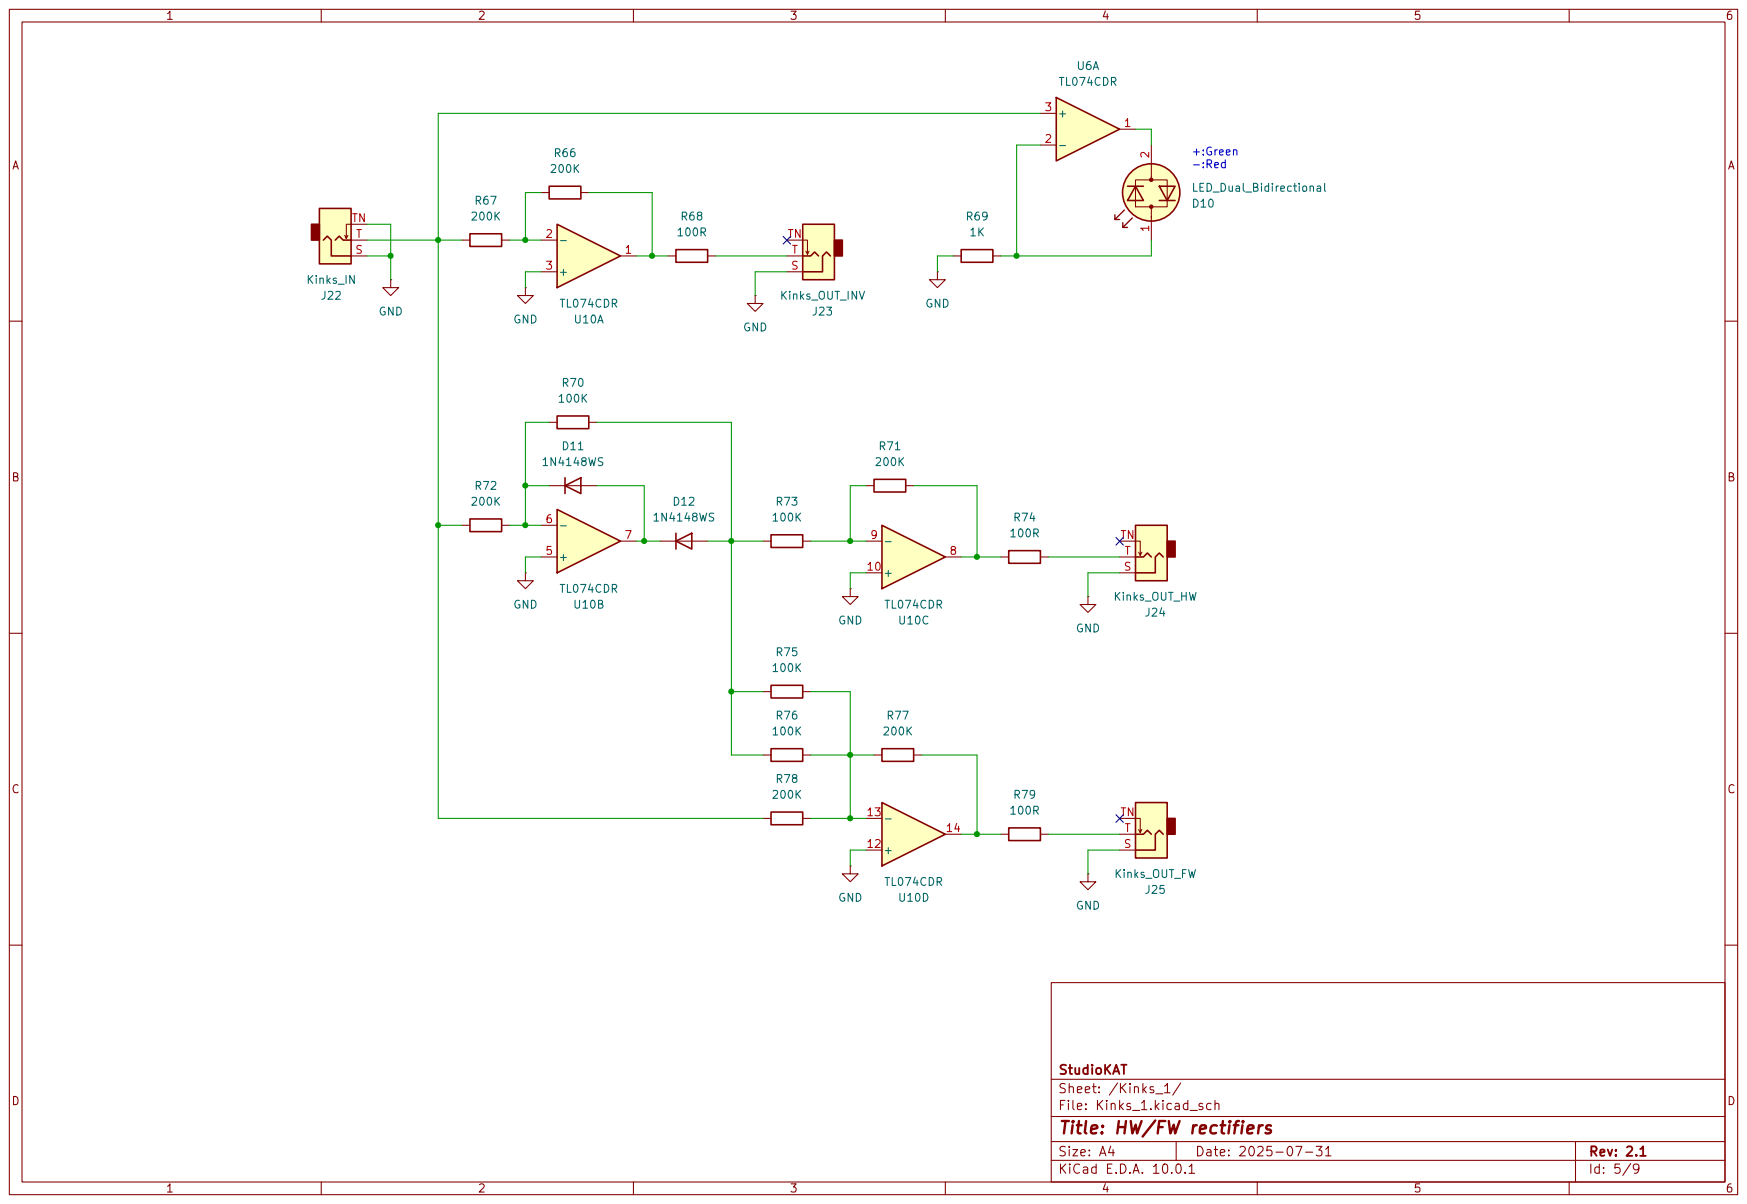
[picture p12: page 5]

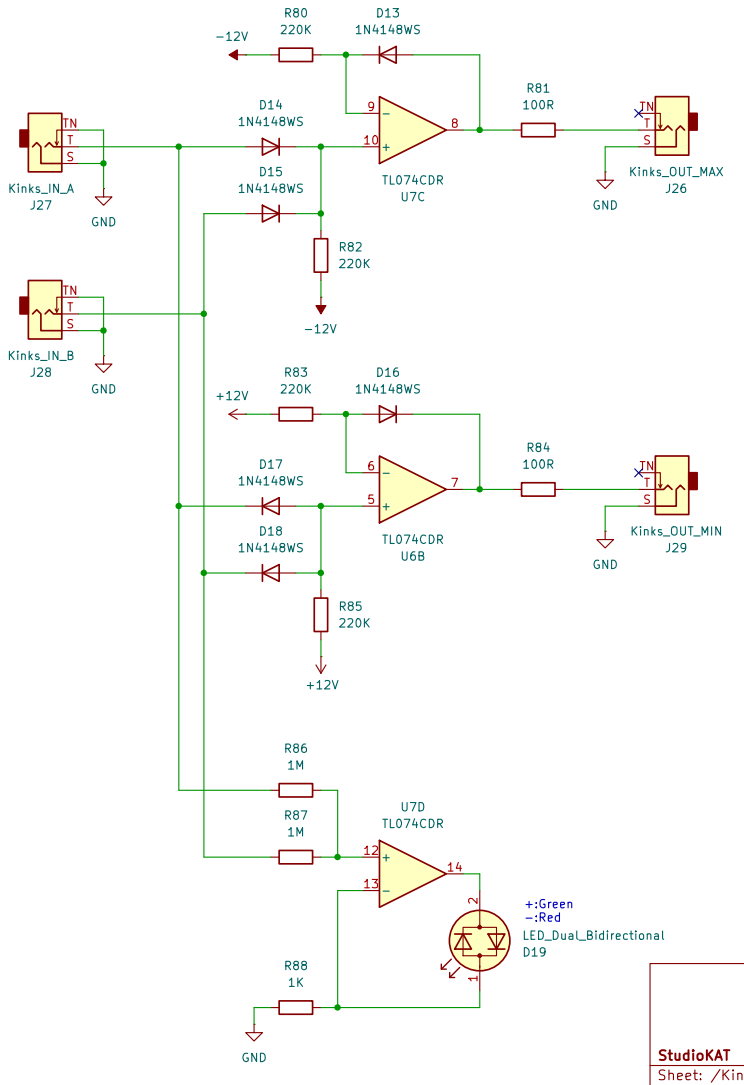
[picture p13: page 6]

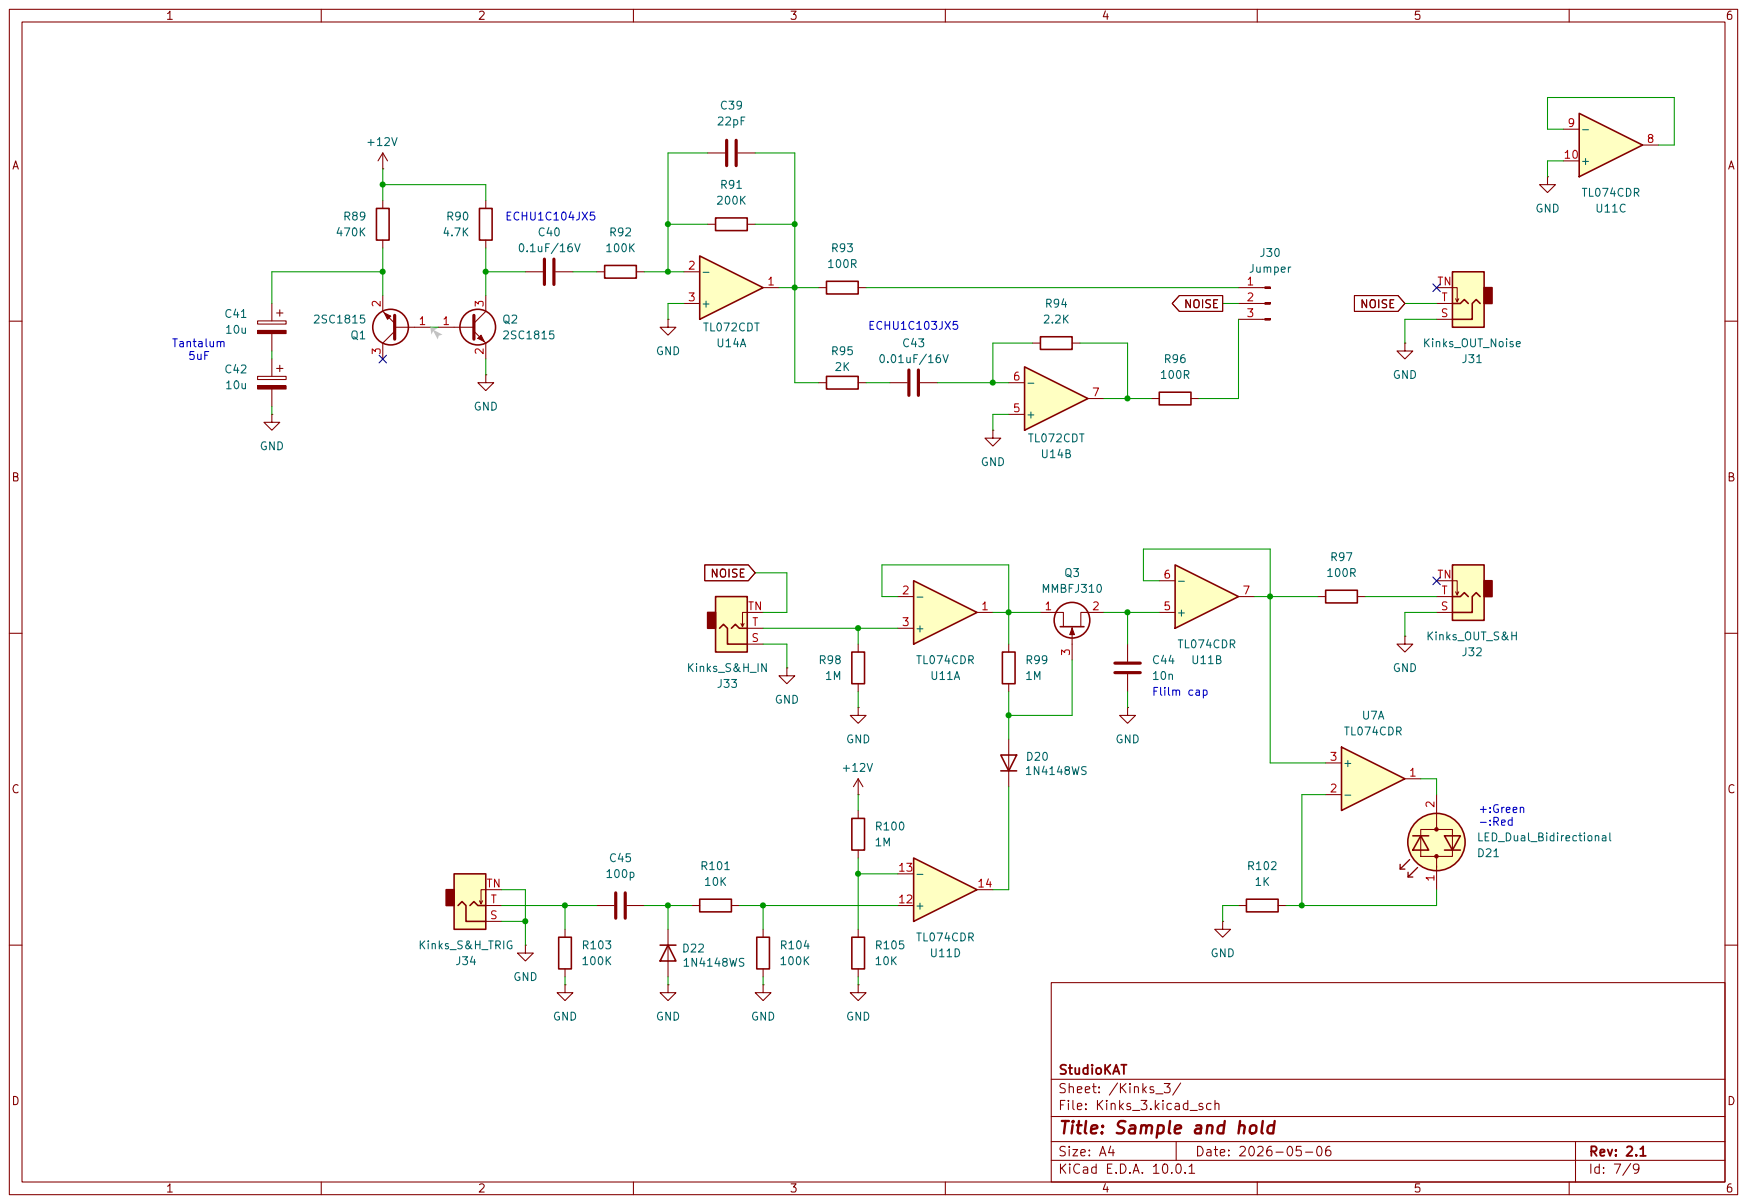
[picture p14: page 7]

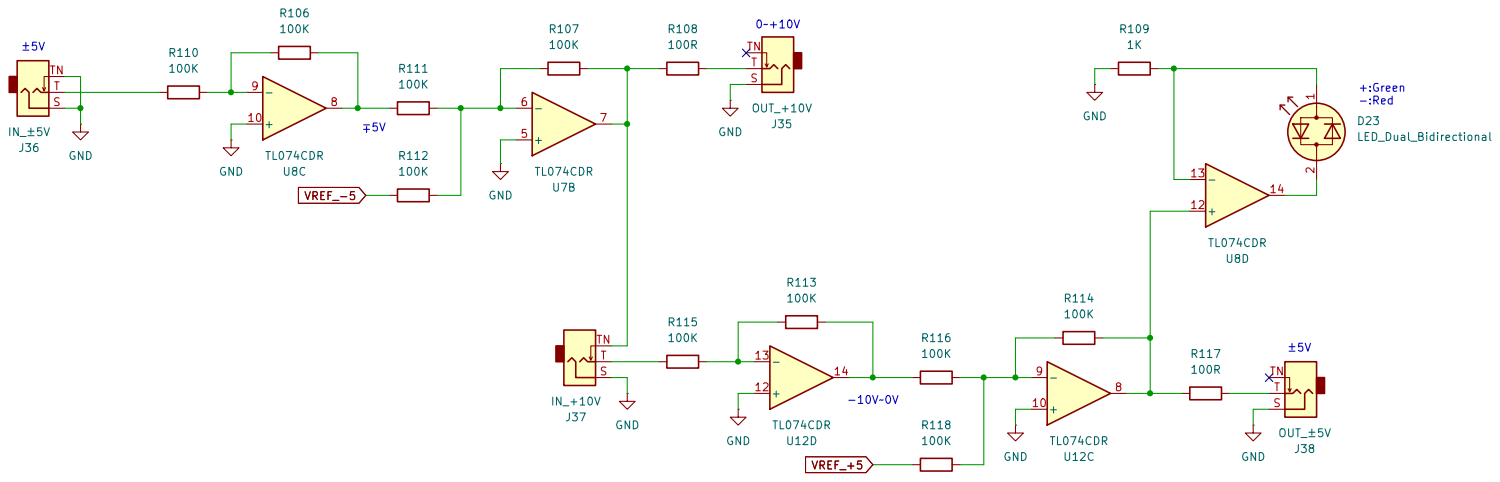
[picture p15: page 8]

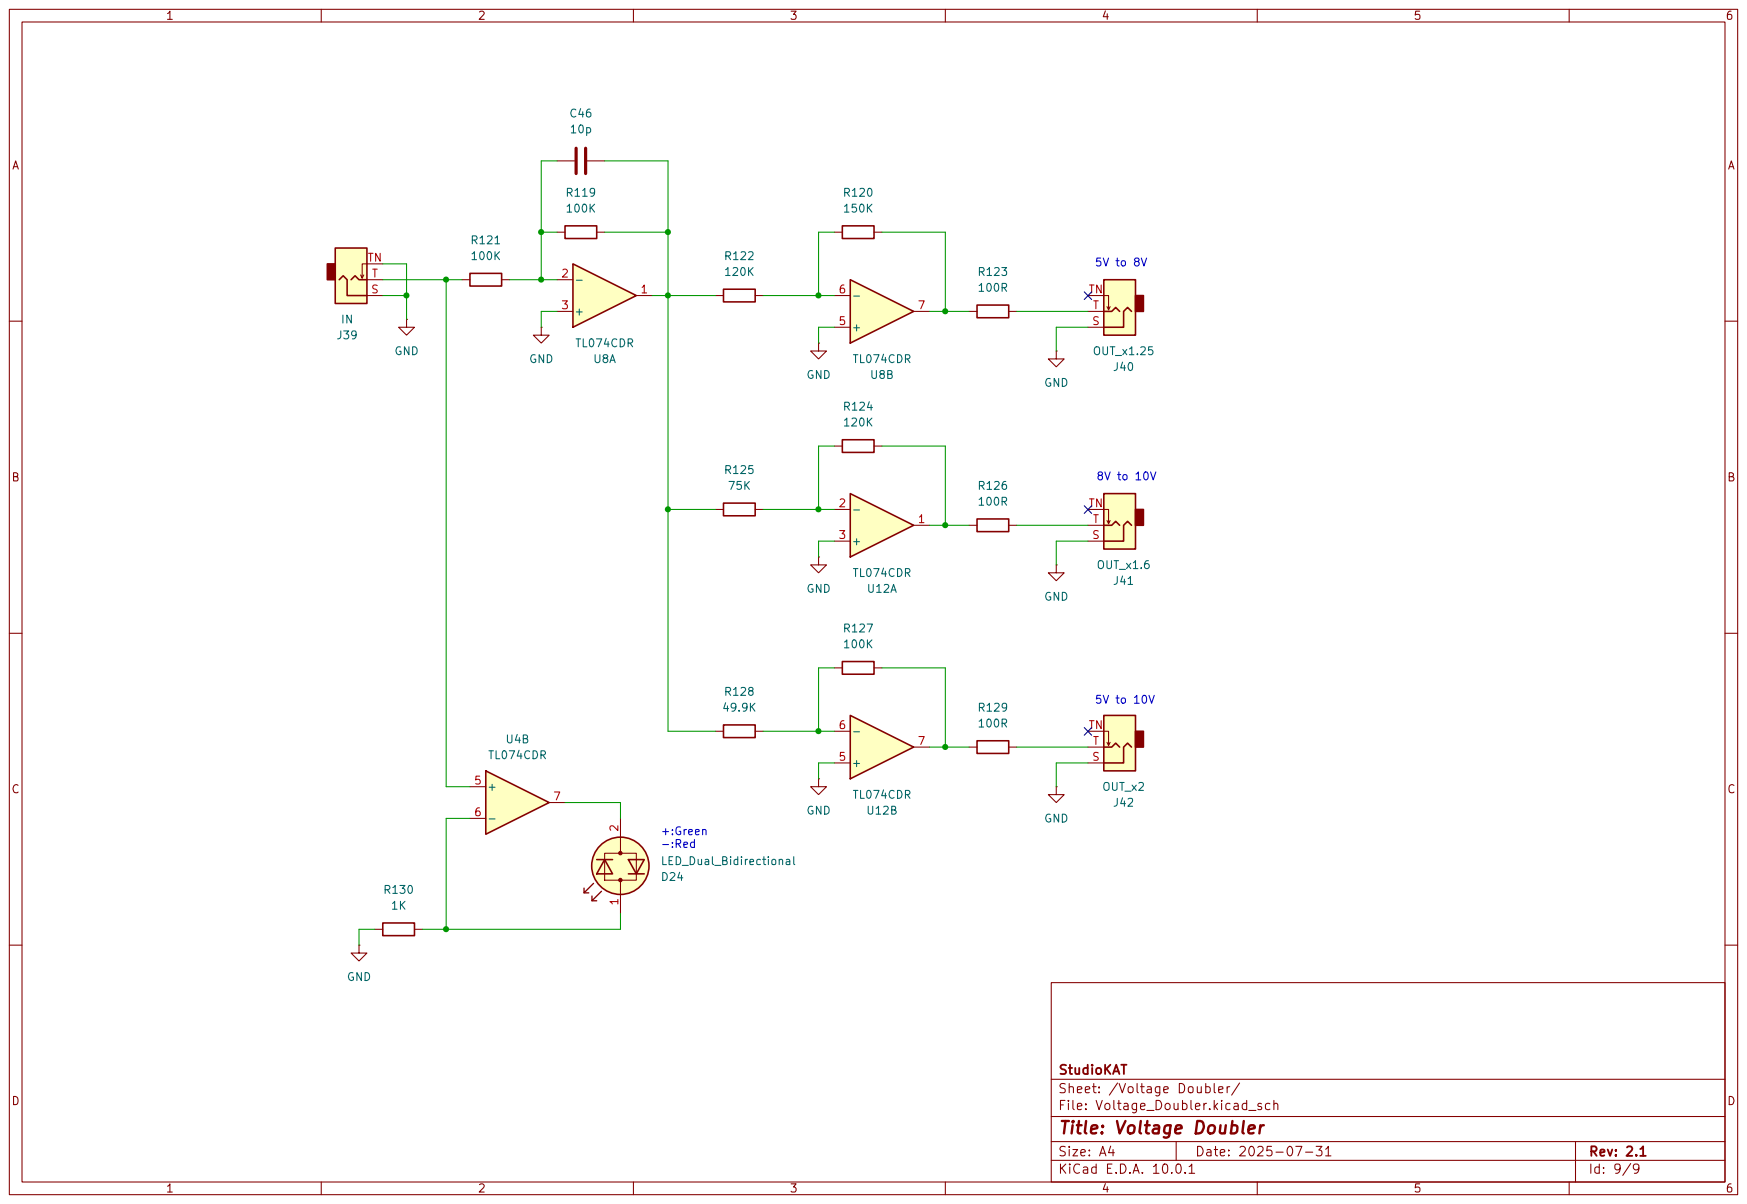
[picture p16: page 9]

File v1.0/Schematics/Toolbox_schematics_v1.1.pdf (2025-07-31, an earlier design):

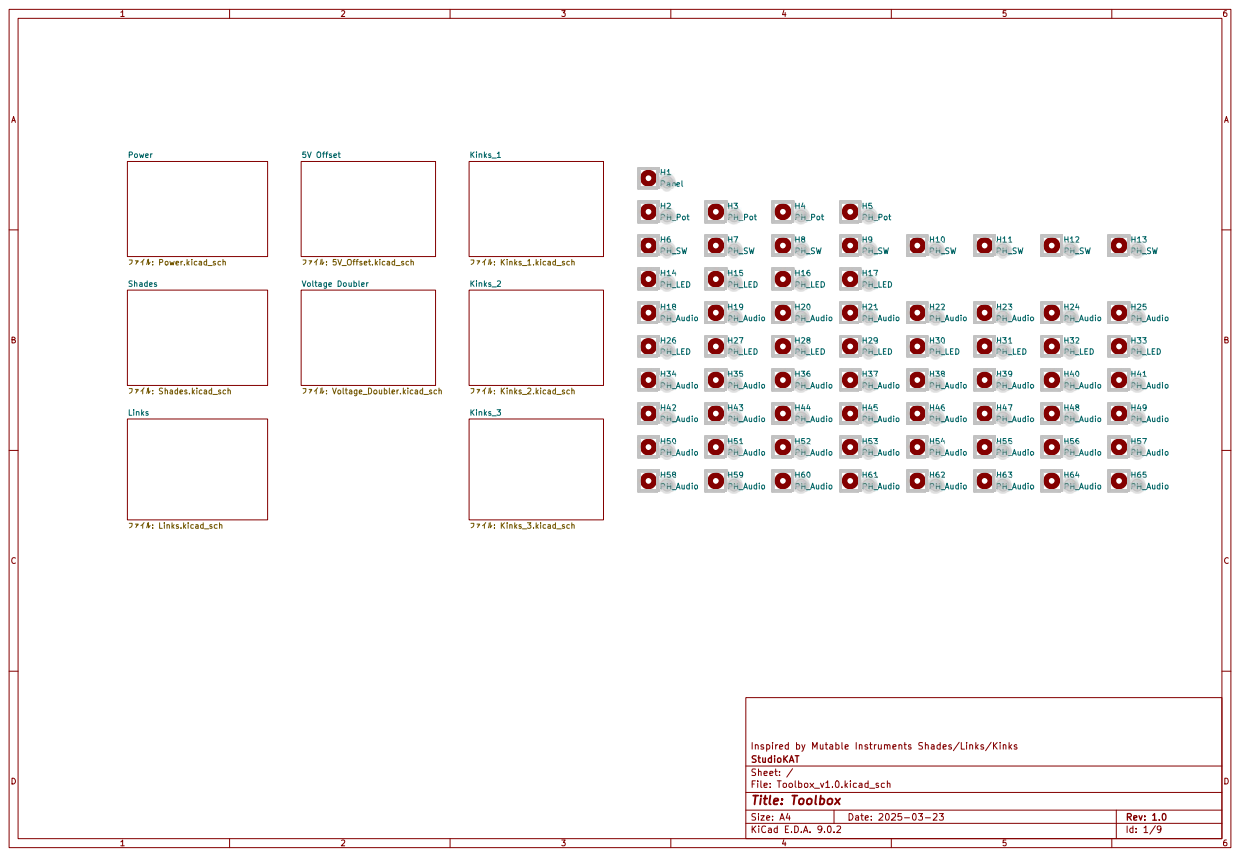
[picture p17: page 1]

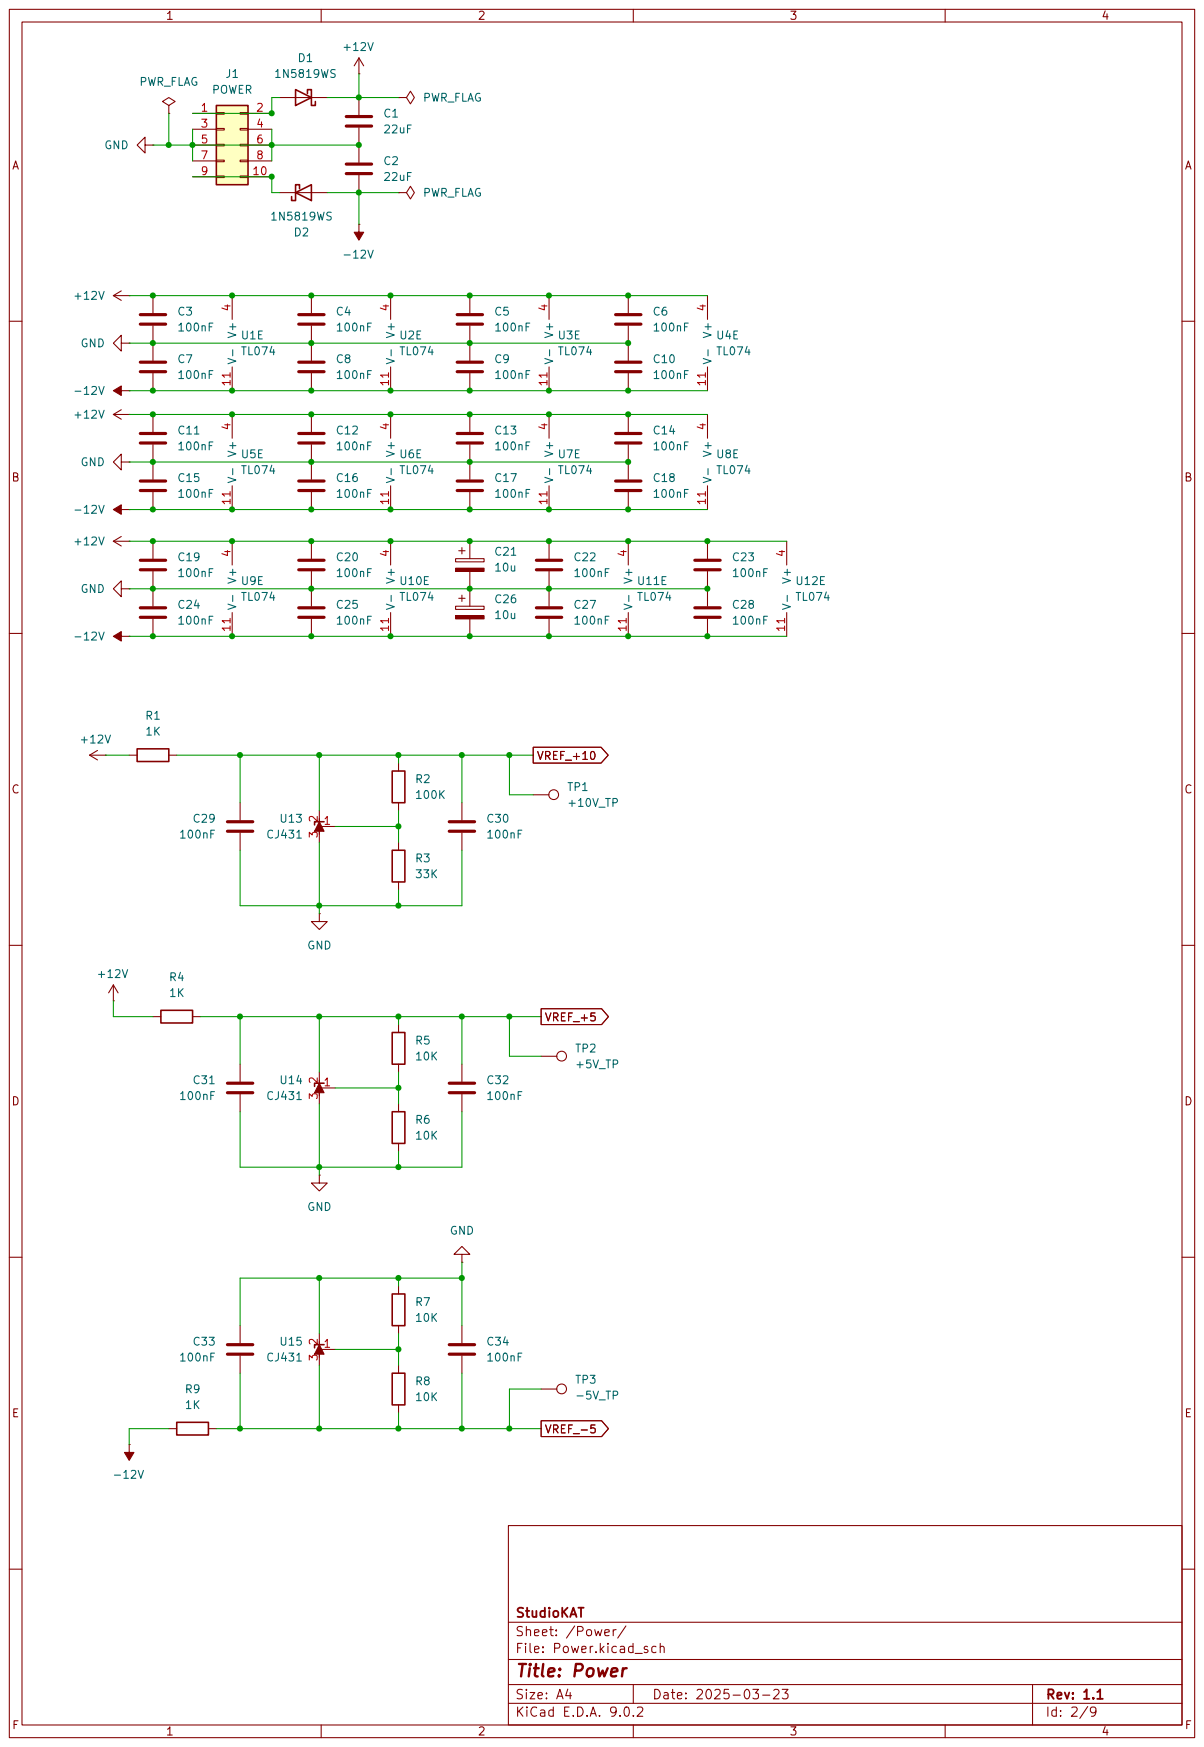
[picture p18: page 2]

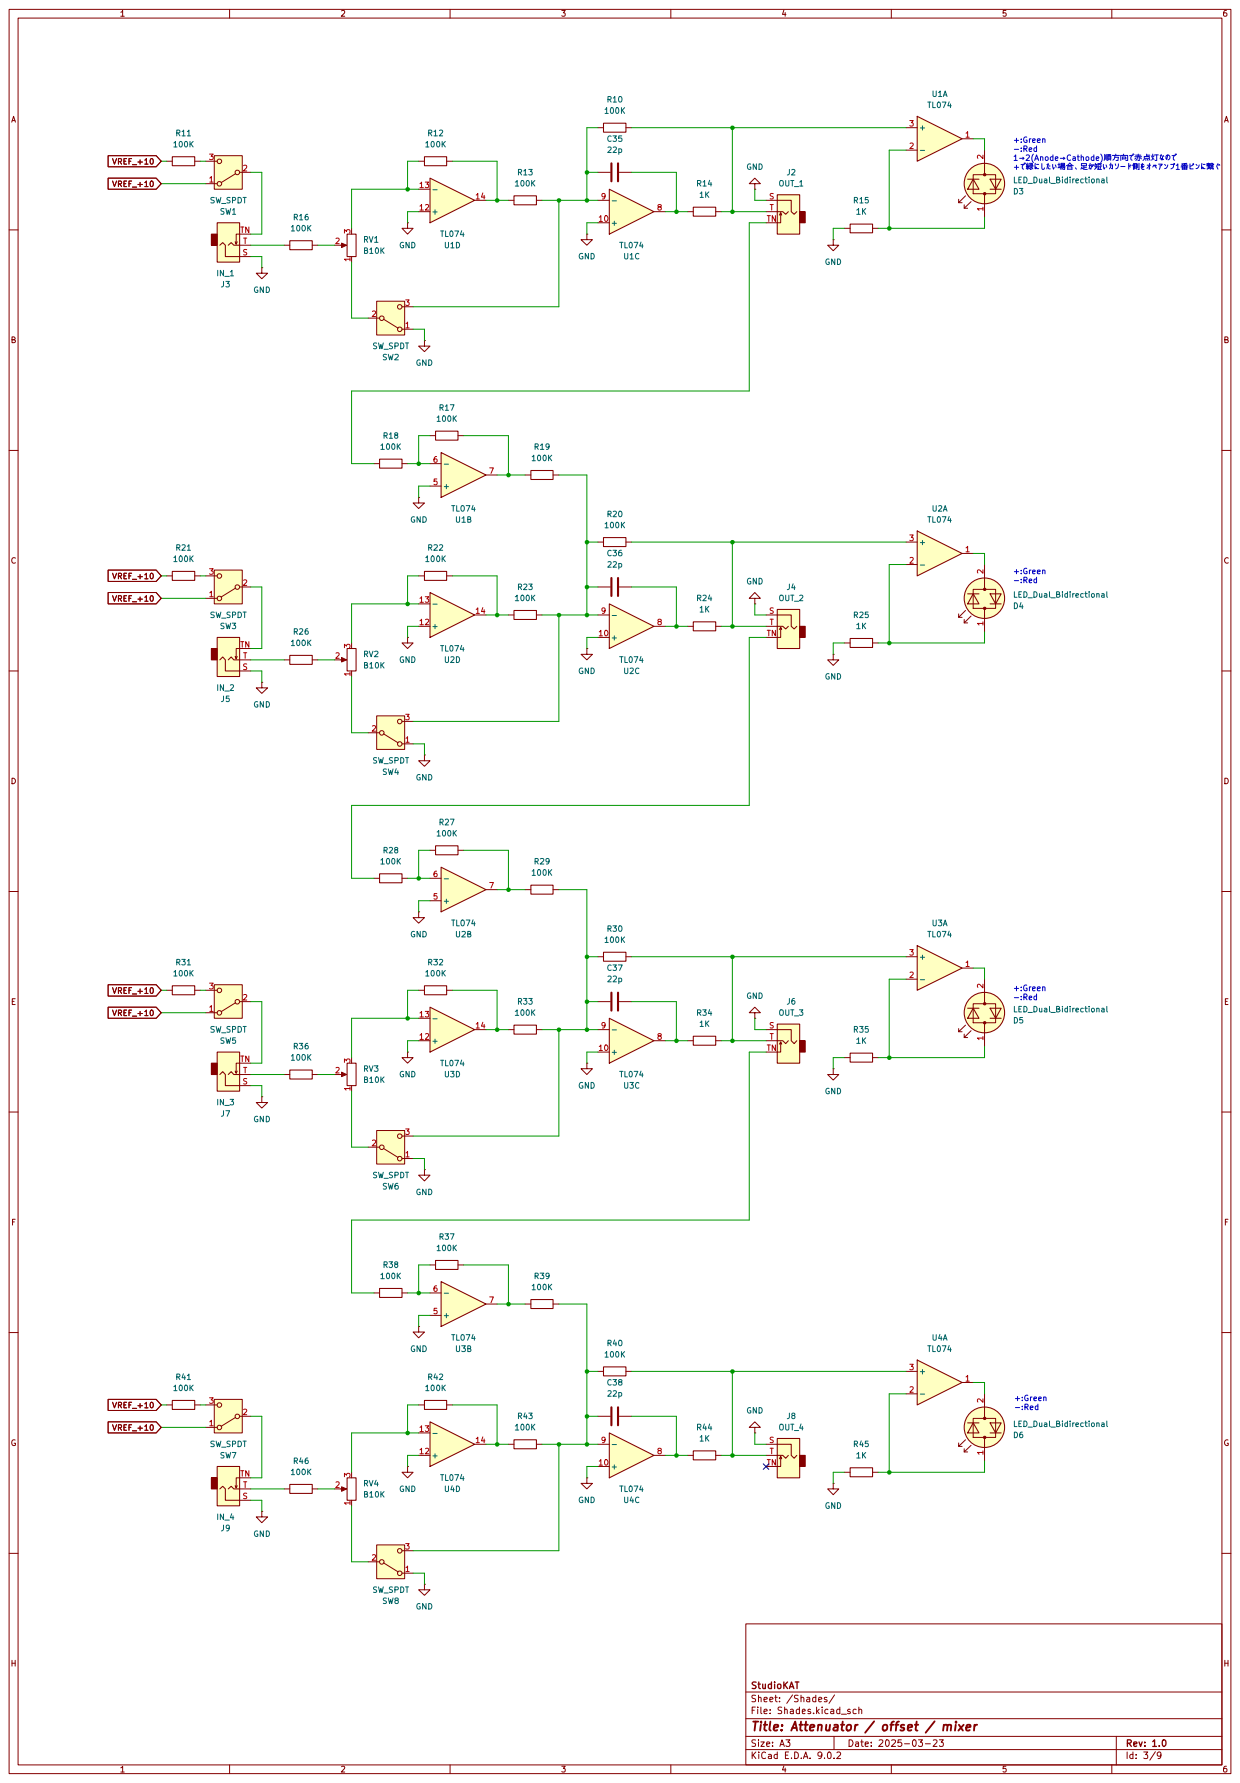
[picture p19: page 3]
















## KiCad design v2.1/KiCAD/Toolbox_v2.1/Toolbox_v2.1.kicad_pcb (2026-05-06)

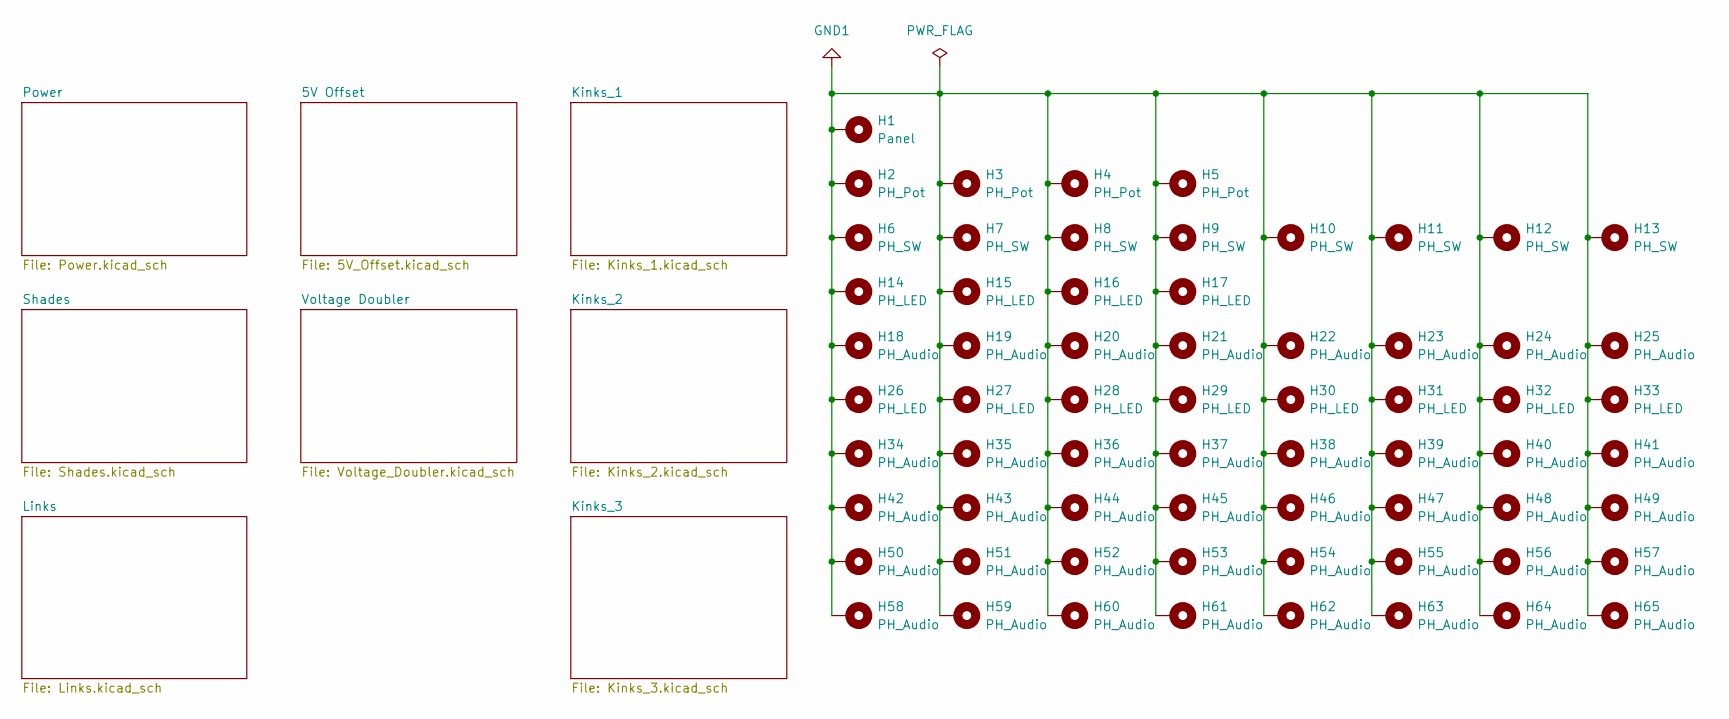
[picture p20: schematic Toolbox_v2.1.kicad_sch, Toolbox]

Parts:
H1: Panel; Panel_16HP
H2, H3, H4, H5: PH_Pot; PH_RK097_15mmKnob_BI_UNI_Pad
H6, H7, H8, H9, H10, H11, H12, H13: PH_SW; PH_ToggleSwitch_5.1mm_Pad
H14, H15, H16, H17, H26, H27, H28, H29, H30, H31, H32, H33: PH_LED; PH_LED_3.0mm_Pad
H18, H19, H20, H21, H22, H23, H24, H25, H34, H35, H36, H37, H38, H39, H40, H41, H42, H43, H44, H45, H46, H47, H48, H49, H50, H51, H52, H53, H54, H55, H56, H57, H58, H59, H60, H61, H62, H63, H64, H65: PH_Audio; PH_AudioJack_3.5mm_Pad

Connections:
GND1: H1.1 (1_1), H2.1 (1_1), H3.1 (1_1), H4.1 (1_1), H5.1 (1_1), H6.1 (1_1), H7.1 (1_1), H8.1 (1_1), H9.1 (1_1), H10.1 (1_1), H11.1 (1_1), H12.1 (1_1), H13.1 (1_1), H14.1 (1_1), H15.1 (1_1), H16.1 (1_1), H17.1 (1_1), H18.1 (1_1), H19.1 (1_1), H20.1 (1_1), H21.1 (1_1), H22.1 (1_1), H23.1 (1_1), H24.1 (1_1), H25.1 (1_1), H26.1 (1_1), H27.1 (1_1), H28.1 (1_1), H29.1 (1_1), H30.1 (1_1), H31.1 (1_1), H32.1 (1_1), H33.1 (1_1), H34.1 (1_1), H35.1 (1_1), H36.1 (1_1), H37.1 (1_1), H38.1 (1_1), H39.1 (1_1), H40.1 (1_1), H41.1 (1_1), H42.1 (1_1), H43.1 (1_1), H44.1 (1_1), H45.1 (1_1), H46.1 (1_1), H47.1 (1_1), H48.1 (1_1), H49.1 (1_1), H50.1 (1_1), H51.1 (1_1), H52.1 (1_1), H53.1 (1_1), H54.1 (1_1), H55.1 (1_1), H56.1 (1_1), H57.1 (1_1), H58.1 (1_1), H59.1 (1_1), H60.1 (1_1), H61.1 (1_1), H62.1 (1_1), H63.1 (1_1), H64.1 (1_1), H65.1 (1_1)

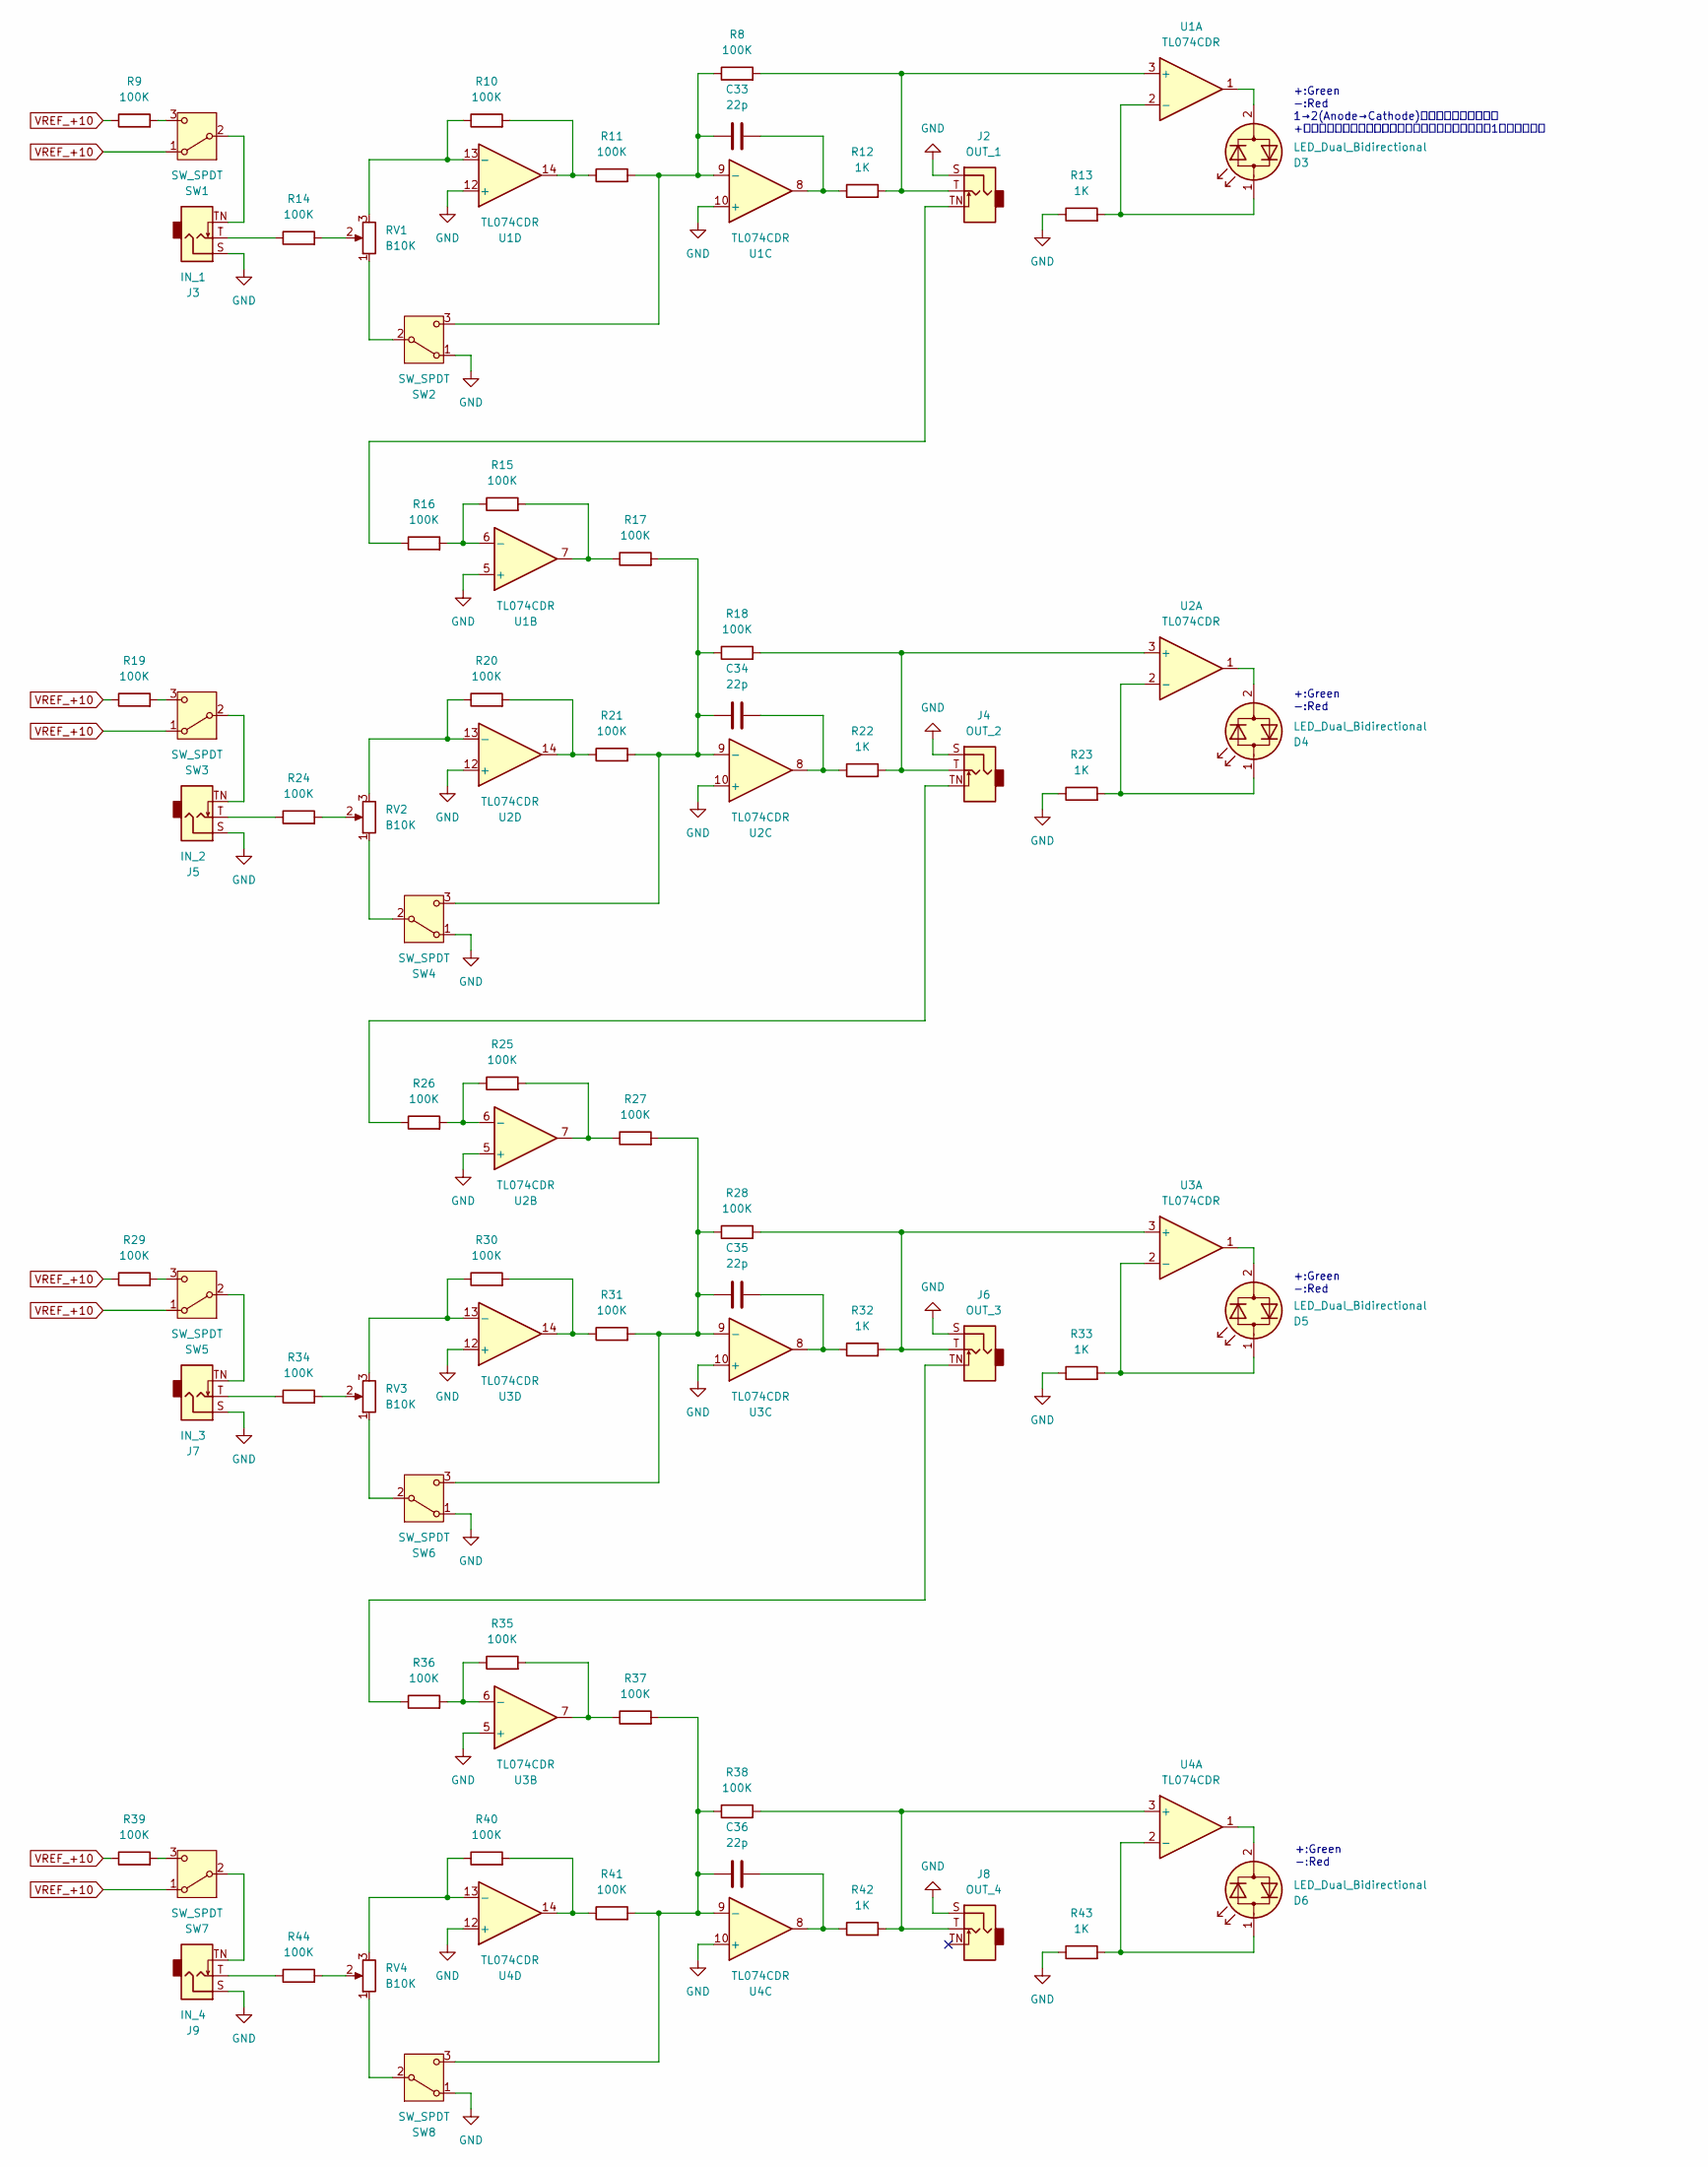
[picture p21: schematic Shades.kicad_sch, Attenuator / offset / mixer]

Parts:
C33, C34, C35, C36: 22p; C_0402_1005Metric; LCSC C1555
D3, D4, D5, D6: LED_Dual_Bidirectional; LED_D3.0mm
J2: OUT_1; AudioJack_PJ301M-12
J3: IN_1; AudioJack_PJ301M-12
J4: OUT_2; AudioJack_PJ301M-12
J5: IN_2; AudioJack_PJ301M-12
J6: OUT_3; AudioJack_PJ301M-12
J7: IN_3; AudioJack_PJ301M-12
J8: OUT_4; AudioJack_PJ301M-12
J9: IN_4; AudioJack_PJ301M-12
R8, R9, R10, R11, R14, R15, R16, R17, R18, R19, R20, R21, R24, R25, R26, R27, R28, R29, R30, R31, R34, R35, R36, R37, R38, R39, R40, R41, R44: 100K; R_0402_1005Metric; LCSC C25741
R12, R13, R22, R23, R32, R33, R42, R43: 1K; R_0402_1005Metric; LCSC C11702
RV1, RV2, RV3, RV4: B10K; Potentiometer_RV09
SW1, SW2, SW3, SW4, SW5, SW6, SW7, SW8: SW_SPDT; ToggleSwitch_2MS1-T2-B4-M2-Q-E-S
U1, U2, U3, U4: TL074CDR; SOIC-14_3.9x8.7mm_P1.27mm; LCSC C12594

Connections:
GND: J2.S, J3.S, J4.S, J5.S, J6.S, J7.S, J8.S, J9.S, R13.1, R23.1, R33.1, R43.1, SW2.1 (A), SW4.1 (A), SW6.1 (A), SW8.1 (A), U1.5 (+), U1.10 (+), U1.12 (+), U2.5 (+), U2.10 (+), U2.12 (+), U3.5 (+), U3.10 (+), U3.12 (+), U4.10 (+), U4.12 (+); also elsewhere on the board
unnamed: C33.2, R12.1, U1.8
unnamed: C34.2, R22.1, U2.8
unnamed: C35.2, R32.1, U3.8
unnamed: C36.2, R42.1, U4.8
unnamed: D3.2 (AK), U1.1
unnamed: D3.1 (KA), R13.2, U1.2 (-)
unnamed: D4.2 (AK), U2.1
unnamed: D4.1 (KA), R23.2, U2.2 (-)
unnamed: D5.2 (AK), U3.1
unnamed: D5.1 (KA), R33.2, U3.2 (-)
unnamed: D6.2 (AK), U4.1
unnamed: D6.1 (KA), R43.2, U4.2 (-)
unnamed: J2.TN, R16.1
unnamed: J3.T, R14.1
unnamed: J4.TN, R26.1
unnamed: J5.T, R24.1
unnamed: J6.TN, R36.1
unnamed: J7.T, R34.1
unnamed: J9.T, R44.1
unnamed: R10.2, R11.1, U1.14
unnamed: R14.2, RV1.2
unnamed: R15.2, R17.1, U1.7
unnamed: R20.2, R21.1, U2.14
unnamed: R24.2, RV2.2
unnamed: R25.2, R27.1, U2.7
unnamed: R30.2, R31.1, U3.14
unnamed: R34.2, RV3.2
unnamed: R35.2, R37.1, U3.7
unnamed: R40.2, R41.1, U4.14
unnamed: R44.2, RV4.2
unnamed: J3.TN, SW1.2 (B)
unnamed: R9.2, SW1.3 (C)
unnamed: RV1.1, SW2.2 (B)
unnamed: C33.1, R8.1, R11.2, SW2.3 (C), U1.9 (-)
unnamed: J5.TN, SW3.2 (B)
unnamed: R19.2, SW3.3 (C)
unnamed: RV2.1, SW4.2 (B)
unnamed: C34.1, R17.2, R18.1, R21.2, SW4.3 (C), U2.9 (-)
unnamed: J7.TN, SW5.2 (B)
unnamed: R29.2, SW5.3 (C)
unnamed: RV3.1, SW6.2 (B)
unnamed: C35.1, R27.2, R28.1, R31.2, SW6.3 (C), U3.9 (-)
unnamed: J9.TN, SW7.2 (B)
unnamed: R39.2, SW7.3 (C)
unnamed: RV4.1, SW8.2 (B)
unnamed: C36.1, R37.2, R38.1, R41.2, SW8.3 (C), U4.9 (-)
unnamed: J2.T, R8.2, R12.2, U1.3 (+)
unnamed: R15.1, R16.2, U1.6 (-)
unnamed: R10.1, RV1.3, U1.13 (-)
unnamed: J4.T, R18.2, R22.2, U2.3 (+)
unnamed: R25.1, R26.2, U2.6 (-)
unnamed: R20.1, RV2.3, U2.13 (-)
unnamed: J6.T, R28.2, R32.2, U3.3 (+)
unnamed: R35.1, R36.2, U3.6 (-)
unnamed: R30.1, RV3.3, U3.13 (-)
unnamed: J8.T, R38.2, R42.2, U4.3 (+)
unnamed: R40.1, RV4.3, U4.13 (-)
VREF_+10: R9.1, R19.1, R29.1, R39.1, SW1.1 (A), SW3.1 (A), SW5.1 (A), SW7.1 (A); also elsewhere on the board

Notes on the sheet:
+:Green -:Red
+:Green -:Red 1→2(Anode→Cathode)順方向で赤点灯なので +で緑にしたい場合、足が短いカソード側をオペアンプ1番ピンに繋ぐ

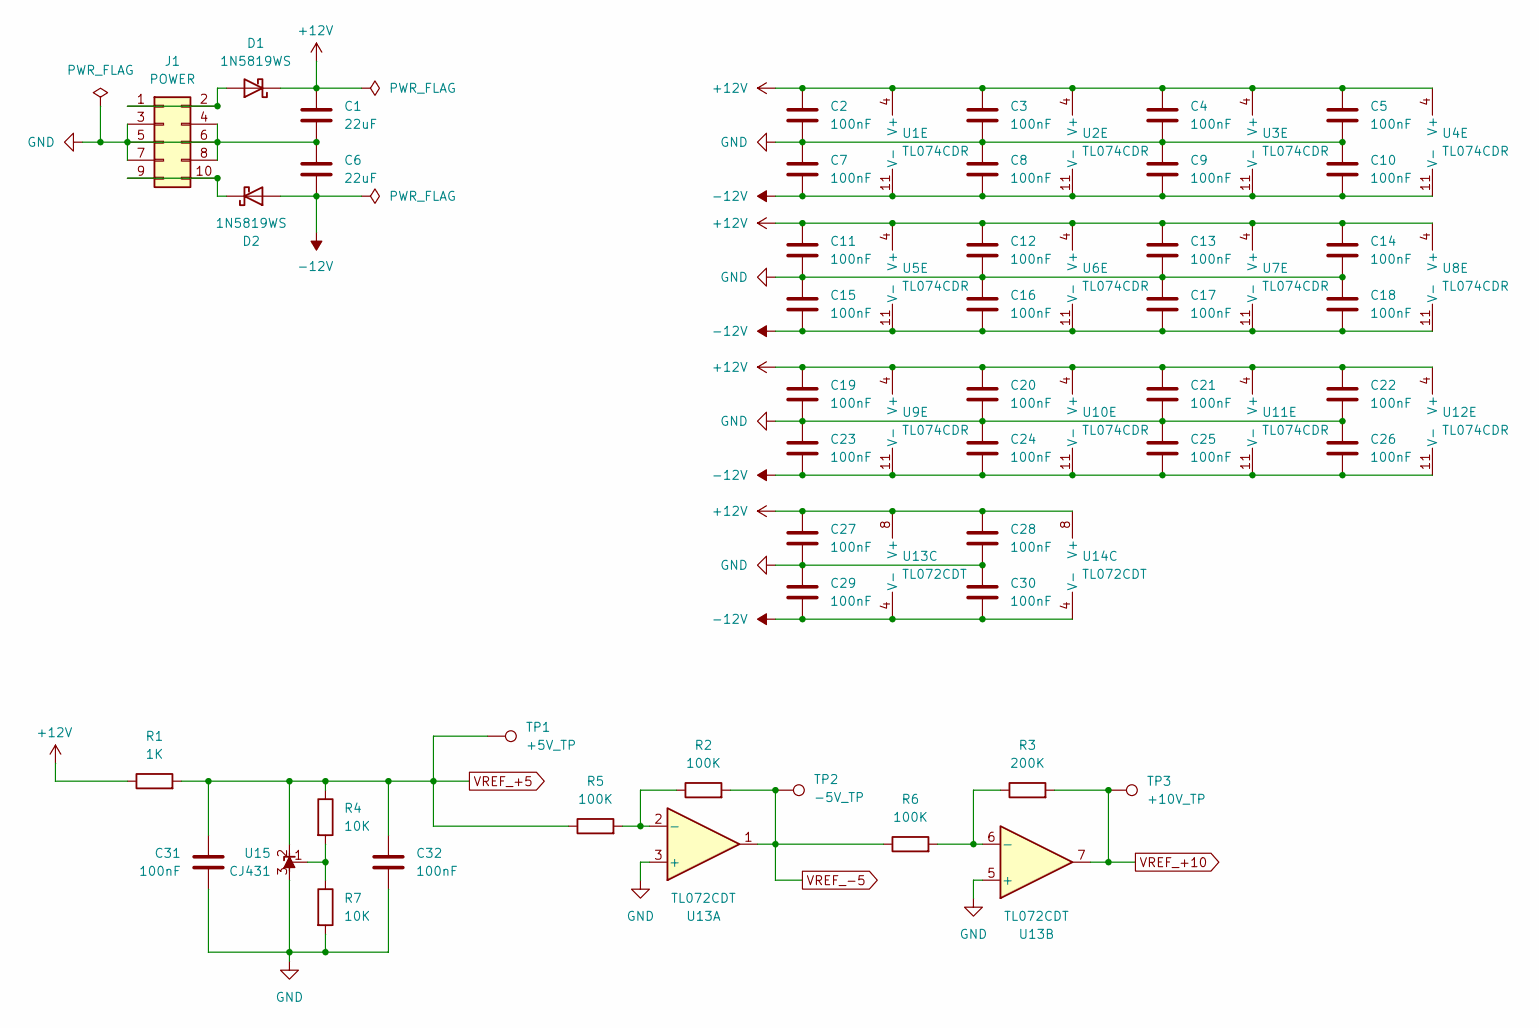
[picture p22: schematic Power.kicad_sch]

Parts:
C1, C6: 22uF; C_0805_2012Metric; LCSC C45783
C2, C3, C4, C5, C7, C8, C9, C10, C11, C12, C13, C14, C15, C16, C17, C18, C19, C20, C21, C22, C23, C24, C25, C26, C27, C28, C29, C30, C31, C32: 100nF; C_0603_1608Metric; LCSC C14663
D1, D2: 1N5819WS; D_SOD-323; LCSC C64886
J1: POWER; PinHeader_2x05_2.54mm_Europower
R1: 1K; R_0603_1608Metric; LCSC C21190
R2, R5, R6: 100K; R_0603_1608Metric; LCSC C25803
R3: 200K; R_0603_1608Metric; LCSC C25811
R4, R7: 10K; R_0603_1608Metric; LCSC C25804
TP1: +5V_TP; TestPoint_Pad_1.0x1.0mm
TP2: -5V_TP; TestPoint_Pad_1.0x1.0mm
TP3: +10V_TP; TestPoint_Pad_1.0x1.0mm
U1, U2, U3, U4, U5, U6, U7, U8, U9, U10, U11, U12: TL074CDR; SOIC-14_3.9x8.7mm_P1.27mm; LCSC C12594
U13, U14: TL072CDT; SOIC-8_3.9x4.9mm_P1.27mm; LCSC C6961
U15: CJ431; SOT-23; LCSC C3113

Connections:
+12V: C1.1, C2.1, C3.1, C4.1, C5.1, C11.1, C12.1, C13.1, C14.1, C19.1, C20.1, C21.1, C22.1, C27.1, C28.1, D1.1 (K), R1.1, U1.4 (V+), U2.4 (V+), U3.4 (V+), U4.4 (V+), U5.4 (V+), U6.4 (V+), U7.4 (V+), U8.4 (V+), U9.4 (V+), U10.4 (V+), U11.4 (V+), U12.4 (V+), U13.8 (V+), U14.8 (V+); also elsewhere on the board
-12V: C6.2, C7.2, C8.2, C9.2, C10.2, C15.2, C16.2, C17.2, C18.2, C23.2, C24.2, C25.2, C26.2, C29.2, C30.2, D2.2 (A), U1.11 (V-), U2.11 (V-), U3.11 (V-), U4.11 (V-), U5.11 (V-), U6.11 (V-), U7.11 (V-), U8.11 (V-), U9.11 (V-), U10.11 (V-), U11.11 (V-), U12.11 (V-), U13.4 (V-), U14.4 (V-); also elsewhere on the board
GND: C1.2, C2.2, C3.2, C4.2, C5.2, C6.1, C7.1, C8.1, C9.1, C10.1, C11.2, C12.2, C13.2, C14.2, C15.1, C16.1, C17.1, C18.1, C19.2, C20.2, C21.2, C22.2, C23.1, C24.1, C25.1, C26.1, C27.2, C28.2, C29.1, C30.1, C31.2, C32.2, J1.3, J1.4, J1.5, J1.6, J1.7, J1.8, R7.2, U13.3 (+), U13.5 (+), U15.3 (A); also elsewhere on the board
unnamed: D1.2 (A), J1.1, J1.2
unnamed: D2.1 (K), J1.9, J1.10
unnamed: R2.1, R5.2, U13.2 (-)
unnamed: R3.1, R6.2, U13.6 (-)
unnamed: R4.2, R7.1, U15.1 (REF)
VREF_+5: C31.1, C32.1, R1.2, R4.1, R5.1, TP1.1 (1_1), U15.2 (K); also elsewhere on the board
VREF_+10: R3.2, TP3.1 (1_1), U13.7; also elsewhere on the board
VREF_-5: R2.2, R6.1, TP2.1 (1_1), U13.1; also elsewhere on the board

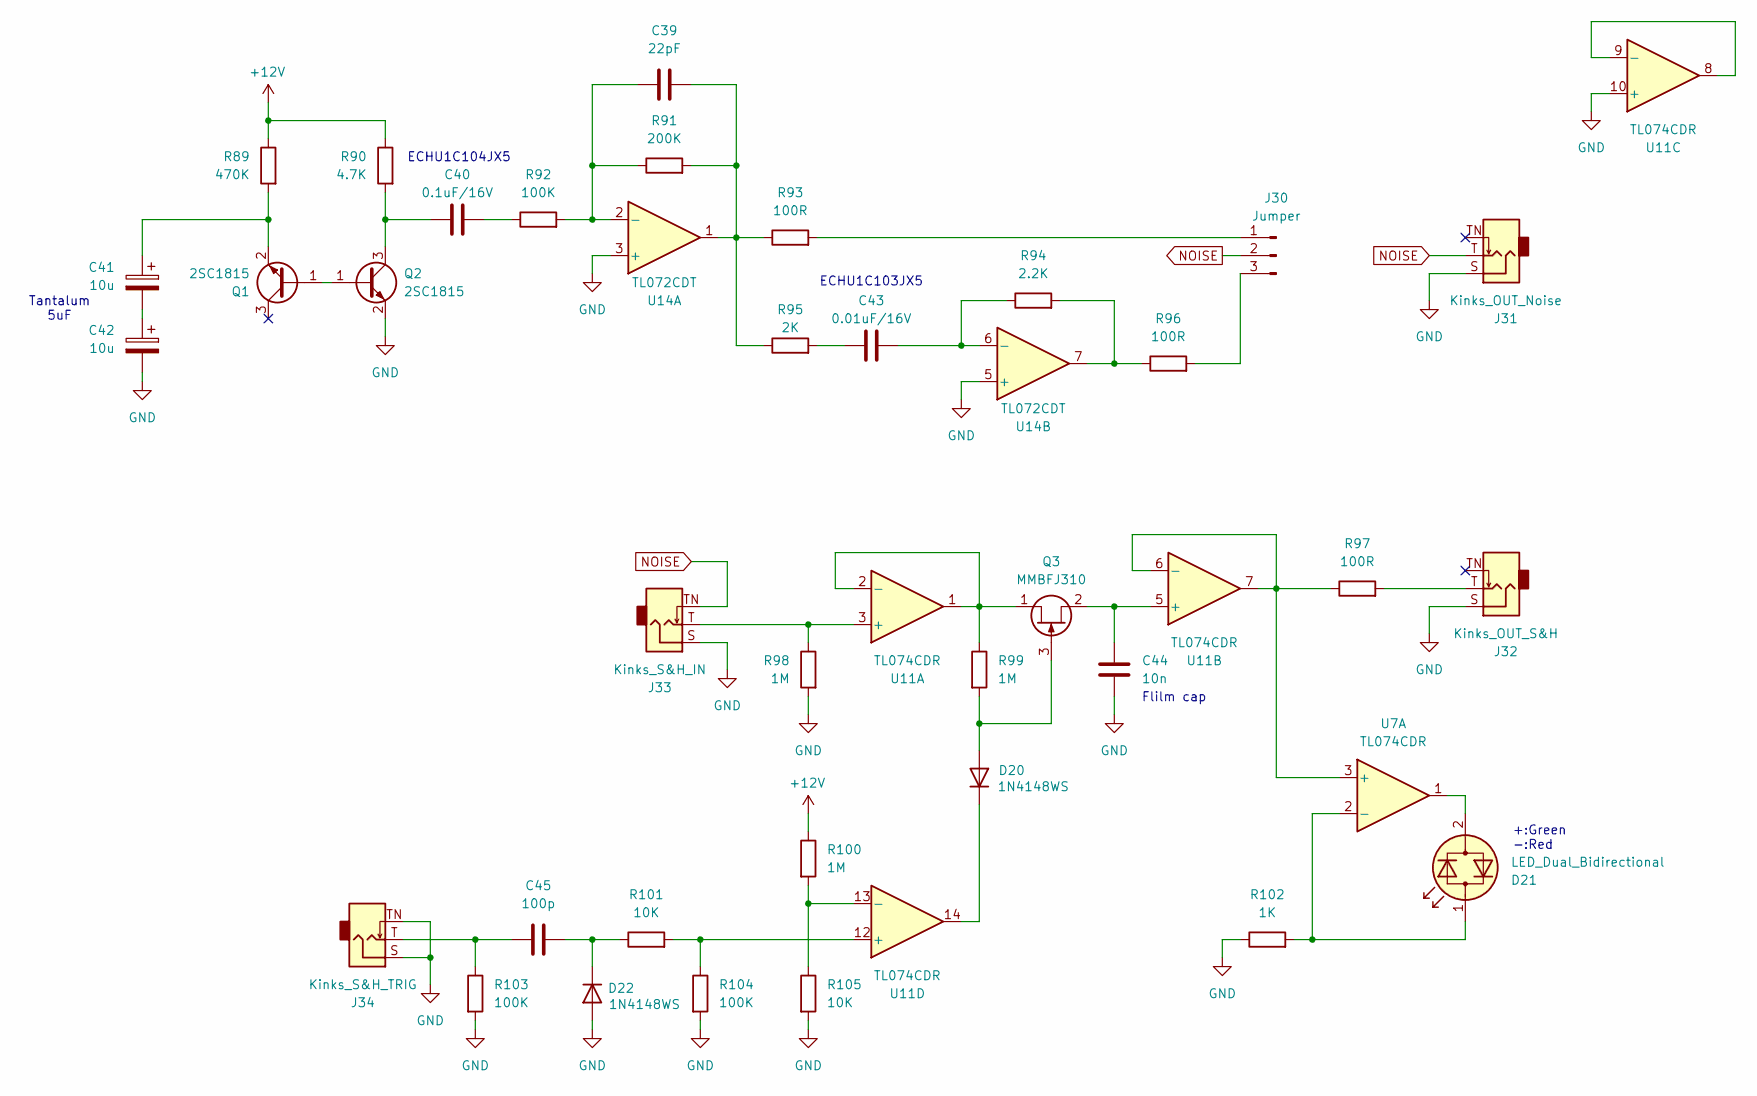
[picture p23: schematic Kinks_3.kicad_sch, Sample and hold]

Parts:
C39: 22pF; C_0603_1608Metric; LCSC C1653
C40: 0.1uF/16V; C_1210_3225Metric_Pad1.33x2.70mm_HandSolder
C41, C42: 10u; CP_EIA-3216-18_Kemet-A; LCSC C7171
C43: 0.01uF/16V; C_0805_2012Metric_Pad1.18x1.45mm_HandSolder
C44: 10n; C_Rect_L7.2mm_W2.5mm_P5.00mm_FKS2_FKP2_MKS2_MKP2
C45: 100p; C_0402_1005Metric; LCSC C1546
D20, D22: 1N4148WS; D_SOD-323; LCSC C2128
D21: LED_Dual_Bidirectional; LED_D3.0mm
J30: Jumper; PinHeader_1x03_P2.54mm_Vertical
J31: Kinks_OUT_Noise; AudioJack_PJ301M-12
J32: Kinks_OUT_S&H; AudioJack_PJ301M-12
J33: Kinks_S&H_IN; AudioJack_PJ301M-12
J34: Kinks_S&H_TRIG; AudioJack_PJ301M-12
Q1, Q2: 2SC1815; SOT-23; LCSC C20069143
Q3: MMBFJ310; SOT-23; LCSC C33416
R89: 470K; R_0402_1005Metric; LCSC C25790
R90: 4.7K; R_0402_1005Metric; LCSC C25900
R91: 200K; R_0603_1608Metric; LCSC C25811
R92, R103, R104: 100K; R_0402_1005Metric; LCSC C25741
R93, R96, R97: 100R; R_0402_1005Metric; LCSC C25076
R94: 2.2K; R_0603_1608Metric; LCSC C4190
R95: 2K; R_0603_1608Metric; LCSC C22975
R98, R99, R100: 1M; R_0402_1005Metric; LCSC C26083
R101, R105: 10K; R_0402_1005Metric; LCSC C25744
R102: 1K; R_0402_1005Metric; LCSC C11702
U7, U11: TL074CDR; SOIC-14_3.9x8.7mm_P1.27mm; LCSC C12594
U14: TL072CDT; SOIC-8_3.9x4.9mm_P1.27mm; LCSC C6961

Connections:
+12V: R89.1, R90.1, R100.1; also elsewhere on the board
GND: C42.2, C44.2, D22.2 (A), J31.S, J32.S, J33.S, J34.S, J34.TN, Q2.2 (E), R98.2, R102.1, R103.2, R104.2, R105.2, U11.10 (+), U14.3 (+), U14.5 (+); also elsewhere on the board
NOISE: J30.2, J31.T, J33.TN
unnamed: C39.2, R91.2, R93.1, R95.1, U14.1
unnamed: C40.2, R92.1
unnamed: C41.2, C42.1
unnamed: C43.1, R95.2
unnamed: C45.1, J34.T, R103.1
unnamed: D20.2 (A), Q3.3 (G), R99.2
unnamed: D20.1 (K), U11.14
unnamed: D21.2 (AK), U7.1
unnamed: D21.1 (KA), R102.2, U7.2 (-)
unnamed: C45.2, D22.1 (K), R101.1
unnamed: J30.1, R93.2
unnamed: J30.3, R96.2
unnamed: J32.T, R97.2
unnamed: Q1.1 (B), Q2.1 (B)
unnamed: C41.1, Q1.2 (E), R89.2
unnamed: C40.1, Q2.3 (C), R90.2
unnamed: Q3.1 (D), R99.1, U11.1, U11.2 (-)
unnamed: C44.1, Q3.2 (S), U11.5 (+)
unnamed: R94.2, R96.1, U14.7
unnamed: J33.T, R98.1, U11.3 (+)
unnamed: R97.1, U7.3 (+), U11.6 (-), U11.7
unnamed: U11.8, U11.9 (-)
unnamed: R101.2, R104.1, U11.12 (+)
unnamed: R100.2, R105.1, U11.13 (-)
unnamed: C39.1, R91.1, R92.2, U14.2 (-)
unnamed: C43.2, R94.1, U14.6 (-)

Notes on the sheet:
Flilm cap
ECHU1C104JX5
ECHU1C103JX5
+:Green -:Red
Tantalum 5uF

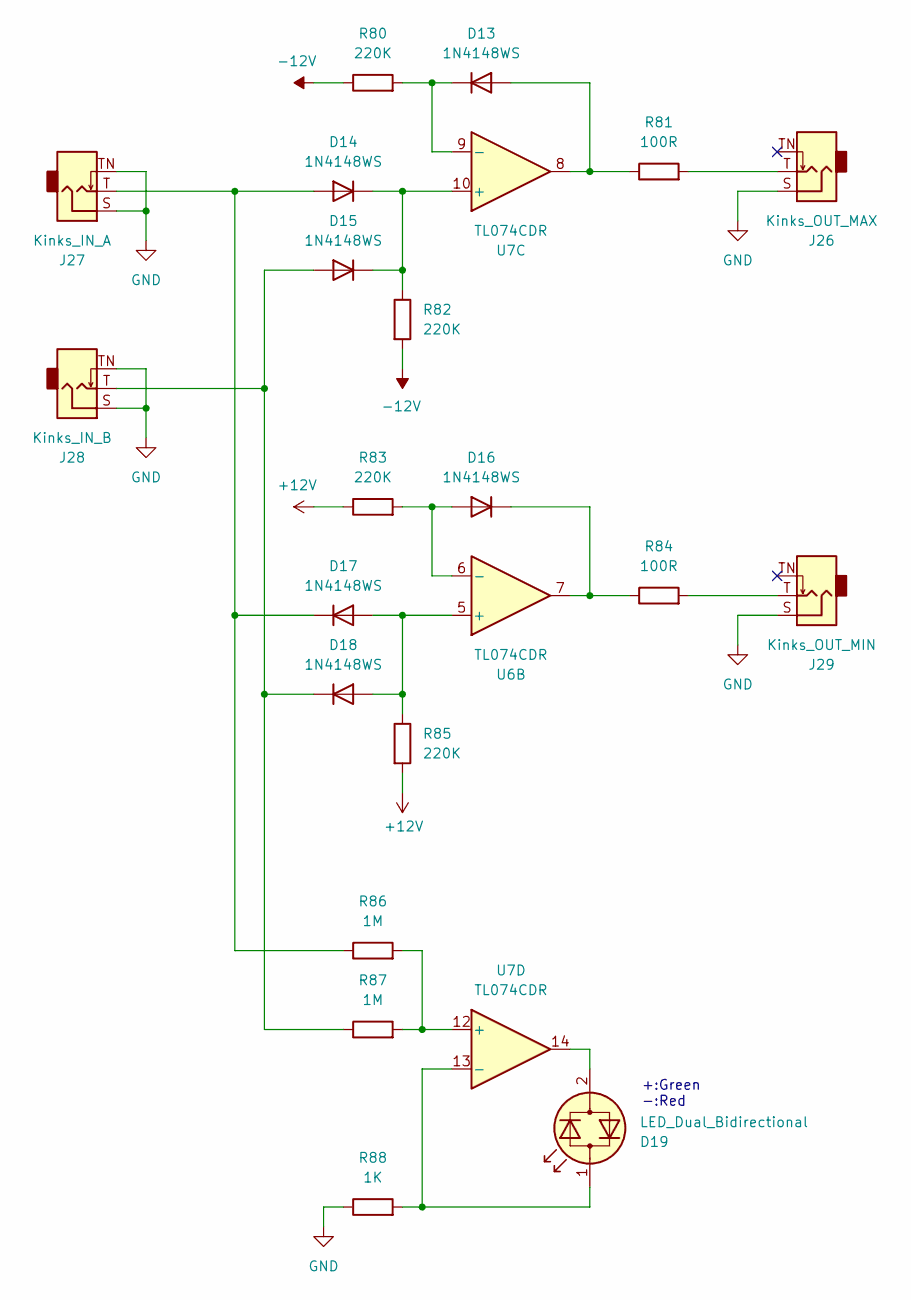
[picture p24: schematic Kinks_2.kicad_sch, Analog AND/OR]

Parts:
D13, D14, D15, D16, D17, D18: 1N4148WS; D_SOD-323; LCSC C2128
D19: LED_Dual_Bidirectional; LED_D3.0mm
J26: Kinks_OUT_MAX; AudioJack_PJ301M-12
J27: Kinks_IN_A; AudioJack_PJ301M-12
J28: Kinks_IN_B; AudioJack_PJ301M-12
J29: Kinks_OUT_MIN; AudioJack_PJ301M-12
R80, R82, R83, R85: 220K; R_0402_1005Metric; LCSC C25767
R81, R84: 100R; R_0402_1005Metric; LCSC C25076
R86, R87: 1M; R_0402_1005Metric; LCSC C26083
R88: 1K; R_0402_1005Metric; LCSC C11702
U6, U7: TL074CDR; SOIC-14_3.9x8.7mm_P1.27mm; LCSC C12594

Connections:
+12V: R83.1, R85.2; also elsewhere on the board
-12V: R80.1, R82.2; also elsewhere on the board
GND: J26.S, J27.S, J27.TN, J28.S, J28.TN, J29.S, R88.1; also elsewhere on the board
unnamed: D13.2 (A), R81.1, U7.8
unnamed: D13.1 (K), R80.2, U7.9 (-)
unnamed: D14.2 (A), D17.1 (K), J27.T, R86.1
unnamed: D14.1 (K), D15.1 (K), R82.1, U7.10 (+)
unnamed: D15.2 (A), D18.1 (K), J28.T, R87.1
unnamed: D16.2 (A), R83.2, U6.6 (-)
unnamed: D16.1 (K), R84.1, U6.7
unnamed: D17.2 (A), D18.2 (A), R85.1, U6.5 (+)
unnamed: D19.2 (AK), U7.14
unnamed: D19.1 (KA), R88.2, U7.13 (-)
unnamed: J26.T, R81.2
unnamed: J29.T, R84.2
unnamed: R86.2, R87.2, U7.12 (+)

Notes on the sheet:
+:Green -:Red

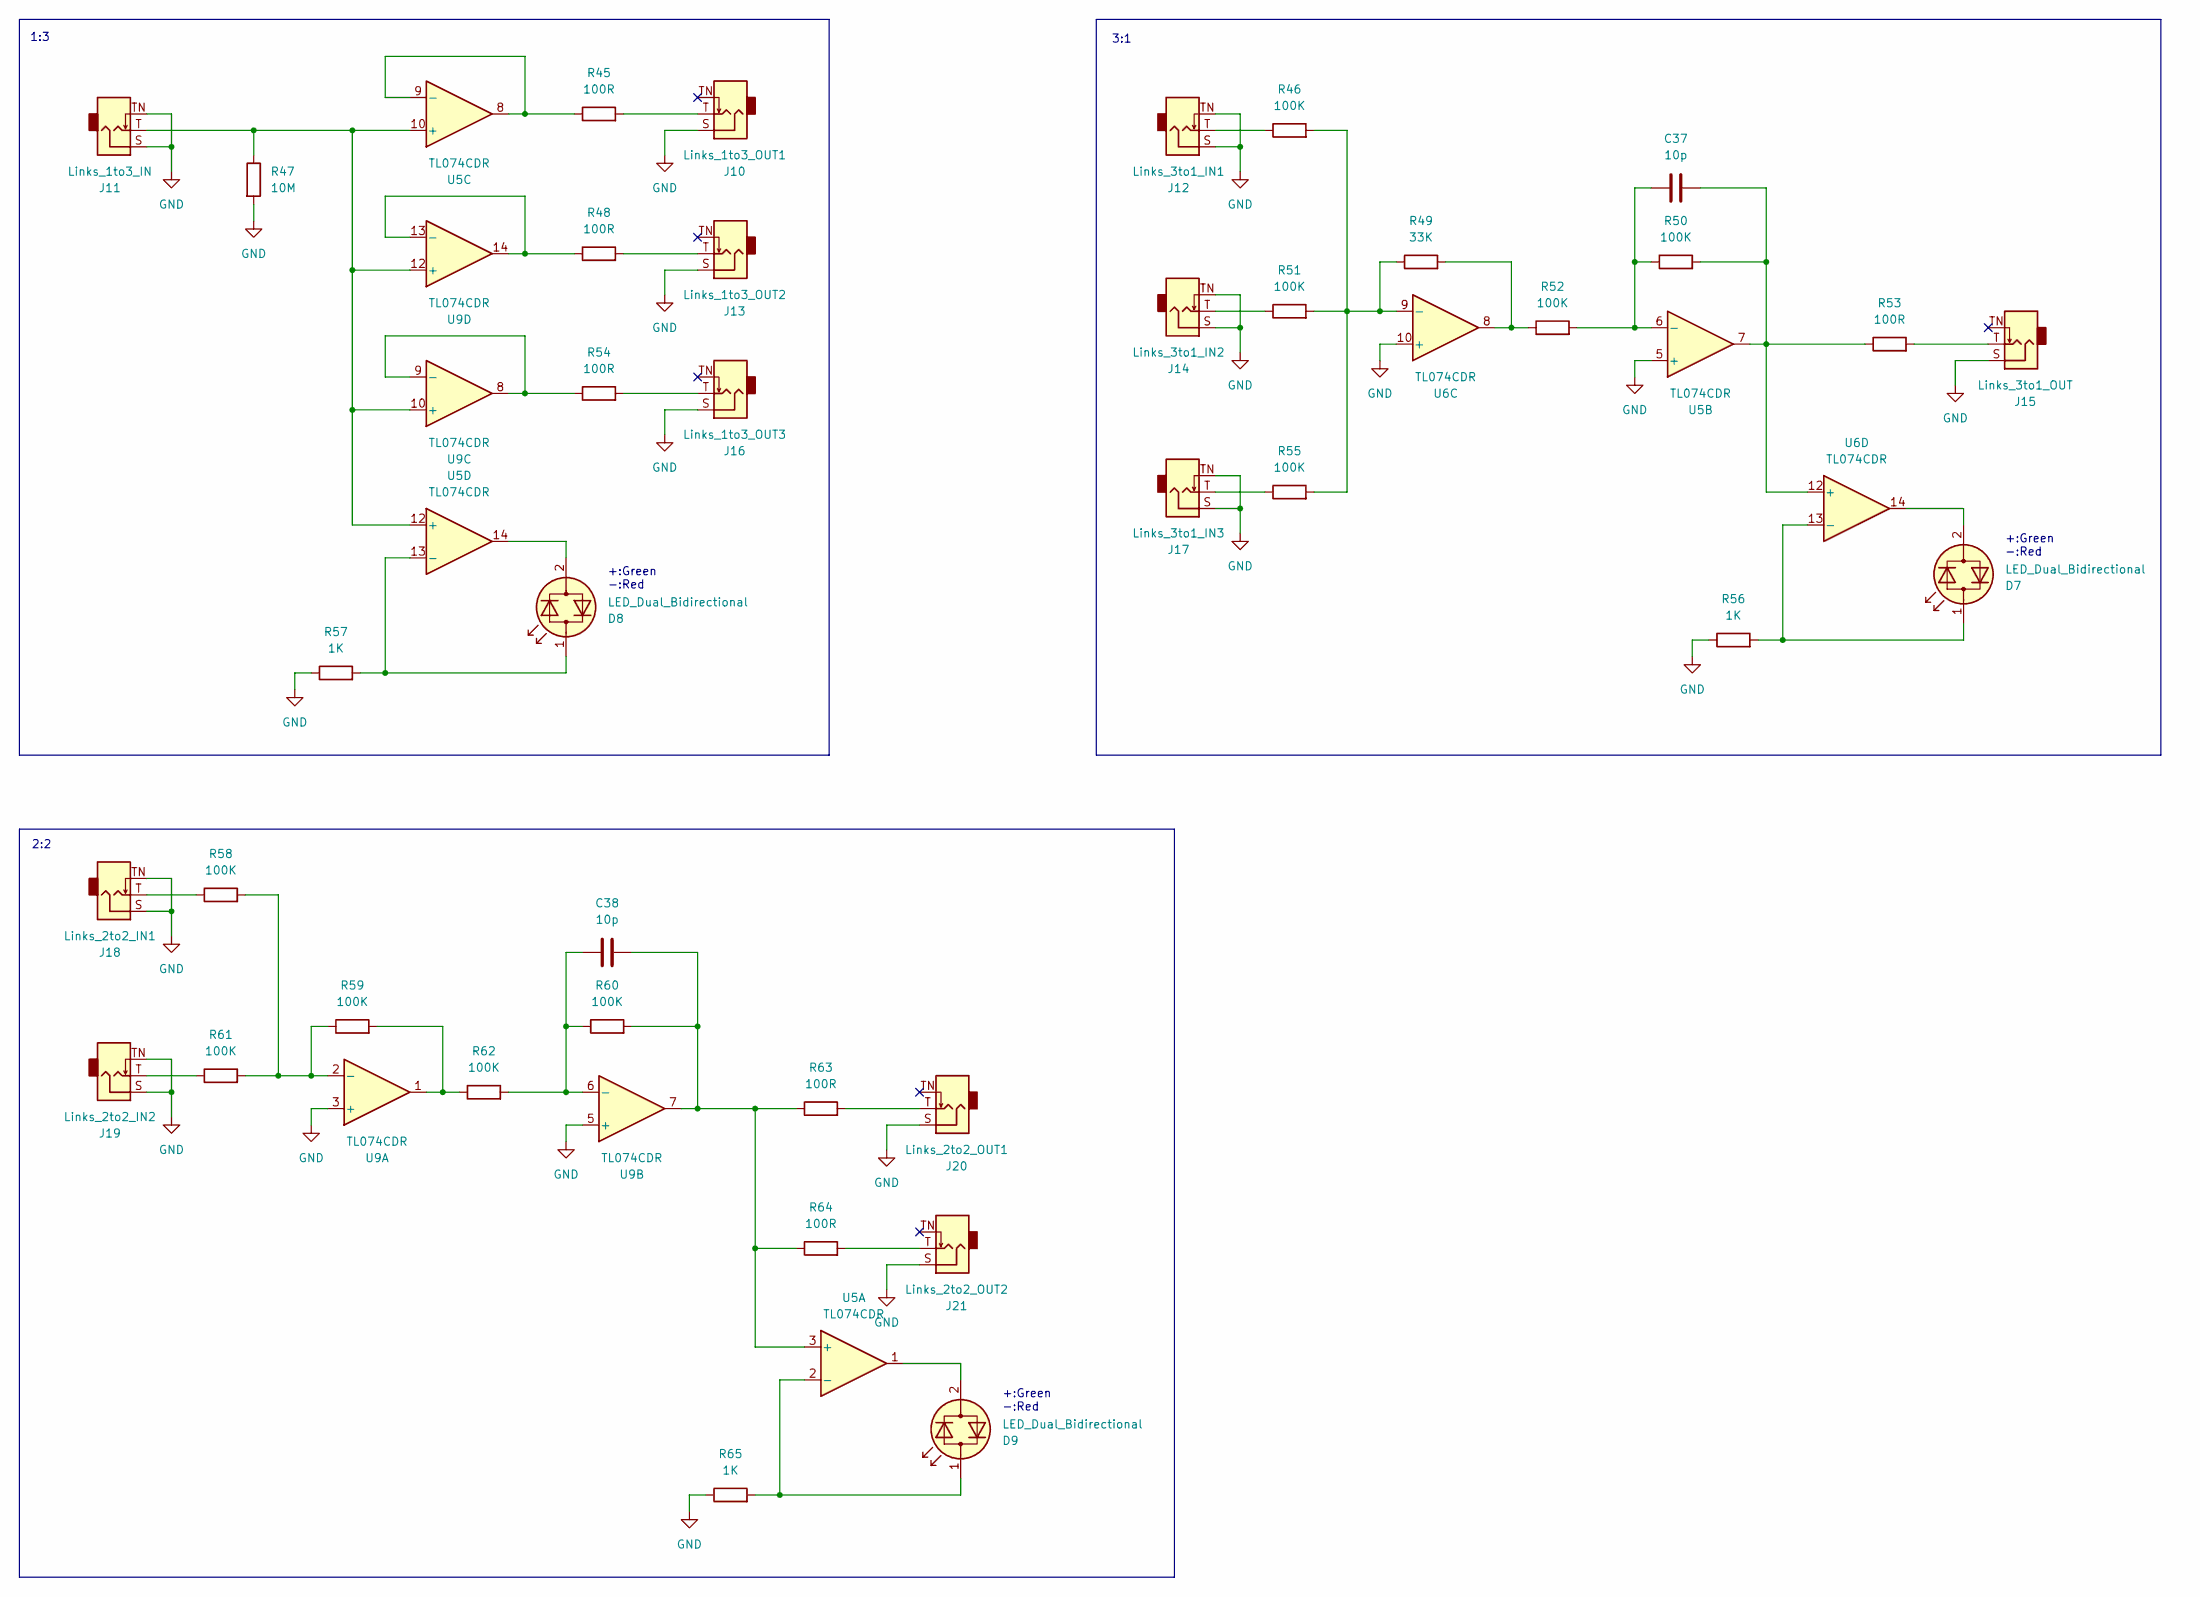
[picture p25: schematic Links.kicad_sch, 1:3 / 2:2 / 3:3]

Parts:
C37, C38: 10p; C_0402_1005Metric; LCSC C32949
D7, D8, D9: LED_Dual_Bidirectional; LED_D3.0mm
J10: Links_1to3_OUT1; AudioJack_PJ301M-12
J11: Links_1to3_IN; AudioJack_PJ301M-12
J12: Links_3to1_IN1; AudioJack_PJ301M-12
J13: Links_1to3_OUT2; AudioJack_PJ301M-12
J14: Links_3to1_IN2; AudioJack_PJ301M-12
J15: Links_3to1_OUT; AudioJack_PJ301M-12
J16: Links_1to3_OUT3; AudioJack_PJ301M-12
J17: Links_3to1_IN3; AudioJack_PJ301M-12
J18: Links_2to2_IN1; AudioJack_PJ301M-12
J19: Links_2to2_IN2; AudioJack_PJ301M-12
J20: Links_2to2_OUT1; AudioJack_PJ301M-12
J21: Links_2to2_OUT2; AudioJack_PJ301M-12
R45, R48, R53, R54, R63, R64: 100R; R_0402_1005Metric; LCSC C25076
R46, R50, R51, R52, R55, R58, R59, R60, R61, R62: 100K; R_0402_1005Metric; LCSC C25741
R47: 10M; R_0402_1005Metric; LCSC C26082
R49: 33K; R_0402_1005Metric; LCSC C25779
R56, R57, R65: 1K; R_0402_1005Metric; LCSC C11702
U5, U6, U9: TL074CDR; SOIC-14_3.9x8.7mm_P1.27mm; LCSC C12594

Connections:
GND: J10.S, J11.S, J11.TN, J12.S, J12.TN, J13.S, J14.S, J14.TN, J15.S, J16.S, J17.S, J17.TN, J18.S, J18.TN, J19.S, J19.TN, J20.S, J21.S, R47.2, R56.1, R57.1, R65.1, U5.5 (+), U6.10 (+), U9.3 (+), U9.5 (+); also elsewhere on the board
unnamed: D7.2 (AK), U6.14
unnamed: D7.1 (KA), R56.2, U6.13 (-)
unnamed: D8.2 (AK), U5.14
unnamed: D8.1 (KA), R57.2, U5.13 (-)
unnamed: D9.2 (AK), U5.1
unnamed: D9.1 (KA), R65.2, U5.2 (-)
unnamed: J10.T, R45.2
unnamed: J12.T, R46.1
unnamed: J13.T, R48.2
unnamed: J14.T, R51.1
unnamed: J15.T, R53.2
unnamed: J16.T, R54.2
unnamed: J17.T, R55.1
unnamed: J18.T, R58.1
unnamed: J19.T, R61.1
unnamed: J20.T, R63.2
unnamed: J21.T, R64.2
unnamed: R49.2, R52.1, U6.8
unnamed: R59.2, R62.1, U9.1
unnamed: C38.2, R60.2, R63.1, R64.1, U5.3 (+), U9.7
unnamed: C37.1, R50.1, R52.2, U5.6 (-)
unnamed: J11.T, R47.1, U5.10 (+), U5.12 (+), U9.10 (+), U9.12 (+)
unnamed: R45.1, U5.8, U5.9 (-)
unnamed: R46.2, R49.1, R51.2, R55.2, U6.9 (-)
unnamed: C37.2, R50.2, R53.1, U5.7, U6.12 (+)
unnamed: R58.2, R59.1, R61.2, U9.2 (-)
unnamed: C38.1, R60.1, R62.2, U9.6 (-)
unnamed: R54.1, U9.8, U9.9 (-)
unnamed: R48.1, U9.13 (-), U9.14

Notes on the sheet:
+:Green -:Red
2:2
3:1
1:3

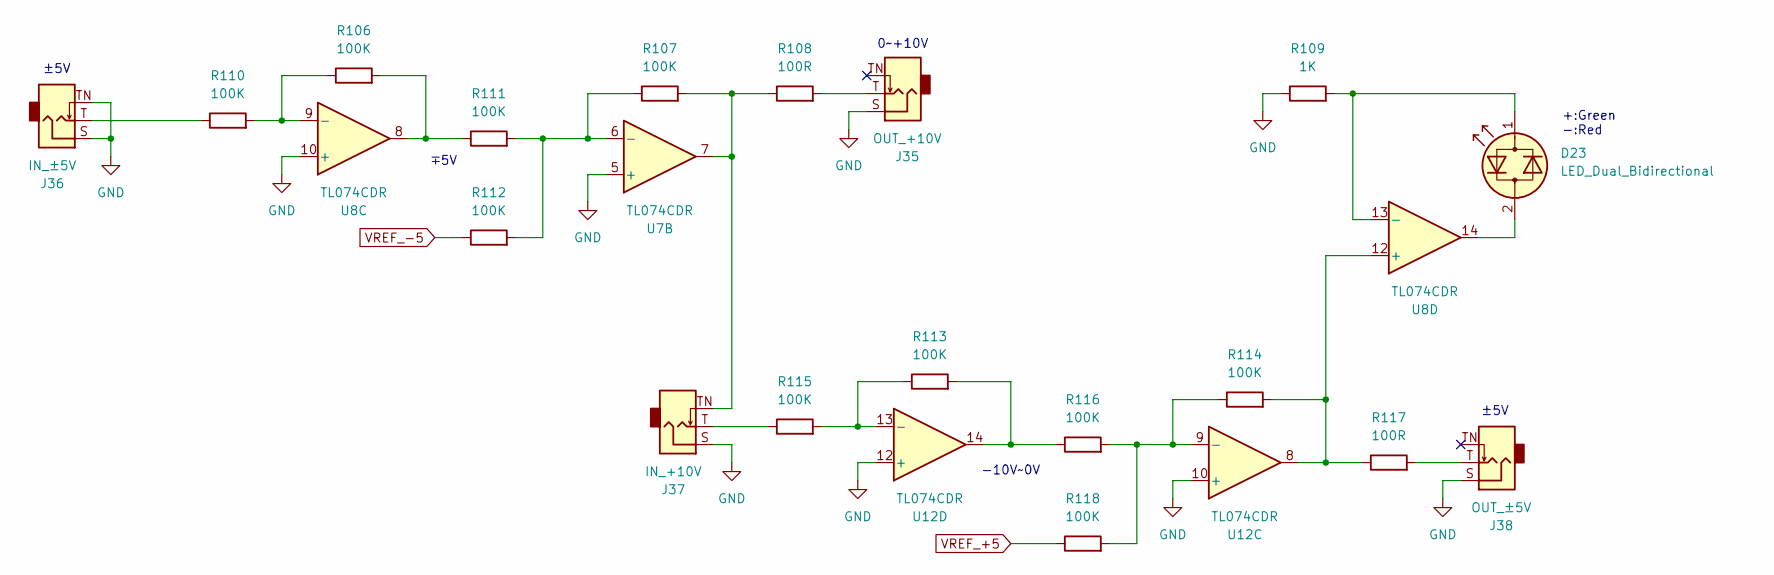
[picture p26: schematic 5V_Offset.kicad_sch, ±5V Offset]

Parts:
D23: LED_Dual_Bidirectional; LED_D3.0mm
J35: OUT_+10V; AudioJack_PJ301M-12
J36: IN_±5V; AudioJack_PJ301M-12
J37: IN_+10V; AudioJack_PJ301M-12
J38: OUT_±5V; AudioJack_PJ301M-12
R106, R107, R110, R111, R112, R113, R114, R115, R116, R118: 100K; R_0402_1005Metric; LCSC C25741
R108, R117: 100R; R_0402_1005Metric; LCSC C25076
R109: 1K; R_0402_1005Metric; LCSC C11702
U7, U8, U12: TL074CDR; SOIC-14_3.9x8.7mm_P1.27mm; LCSC C12594

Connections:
GND: J35.S, J36.S, J36.TN, J37.S, J38.S, R109.1, U7.5 (+), U8.10 (+), U12.10 (+), U12.12 (+); also elsewhere on the board
unnamed: D23.2 (AK), U8.14
unnamed: D23.1 (KA), R109.2, U8.13 (-)
unnamed: J35.T, R108.2
unnamed: J36.T, R110.1
unnamed: J37.T, R115.1
unnamed: J37.TN, R107.2, R108.1, U7.7
unnamed: J38.T, R117.2
unnamed: R106.2, R111.1, U8.8
unnamed: R113.2, R116.1, U12.14
unnamed: R107.1, R111.2, R112.2, U7.6 (-)
unnamed: R106.1, R110.2, U8.9 (-)
unnamed: R114.2, R117.1, U8.12 (+), U12.8
unnamed: R114.1, R116.2, R118.2, U12.9 (-)
unnamed: R113.1, R115.2, U12.13 (-)
VREF_+5: R118.1; also elsewhere on the board
VREF_-5: R112.1; also elsewhere on the board

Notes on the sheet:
0~+10V
-10V~0V
±5V
+:Green -:Red
∓5V

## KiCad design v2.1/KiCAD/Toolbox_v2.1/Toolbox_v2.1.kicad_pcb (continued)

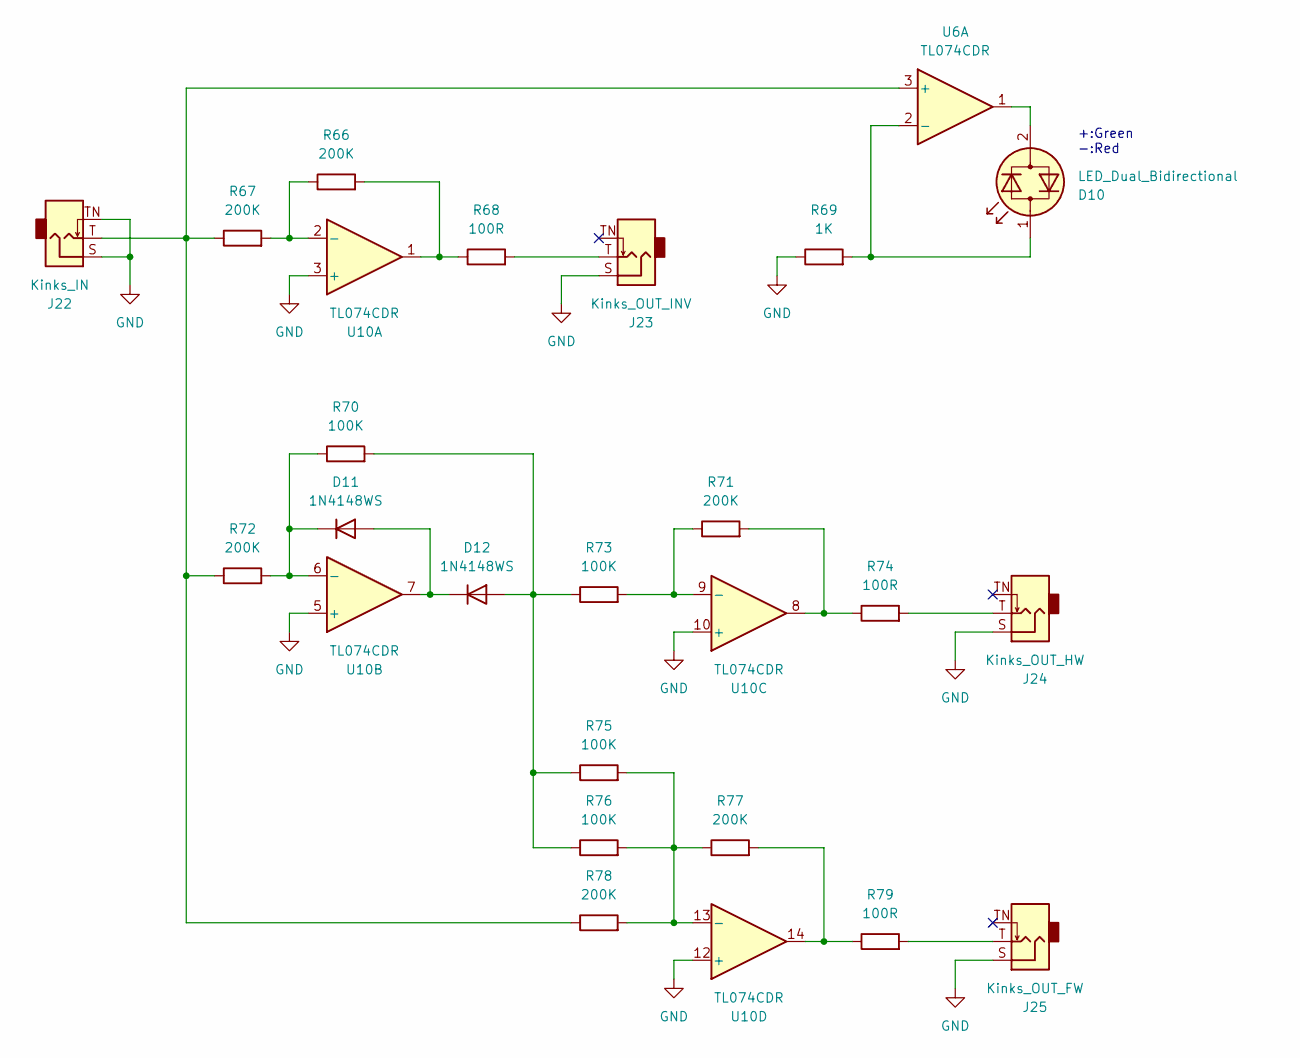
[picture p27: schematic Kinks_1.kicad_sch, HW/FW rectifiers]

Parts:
D10: LED_Dual_Bidirectional; LED_D3.0mm
D11, D12: 1N4148WS; D_SOD-323; LCSC C2128
J22: Kinks_IN; AudioJack_PJ301M-12
J23: Kinks_OUT_INV; AudioJack_PJ301M-12
J24: Kinks_OUT_HW; AudioJack_PJ301M-12
J25: Kinks_OUT_FW; AudioJack_PJ301M-12
R66, R67, R71, R72, R77, R78: 200K; R_0402_1005Metric; LCSC C25764
R68, R74, R79: 100R; R_0402_1005Metric; LCSC C25076
R69: 1K; R_0402_1005Metric; LCSC C11702
R70, R73, R75, R76: 100K; R_0402_1005Metric; LCSC C25741
U6, U10: TL074CDR; SOIC-14_3.9x8.7mm_P1.27mm; LCSC C12594

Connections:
GND: J22.S, J22.TN, J23.S, J24.S, J25.S, R69.1, U10.3 (+), U10.5 (+), U10.10 (+), U10.12 (+); also elsewhere on the board
unnamed: D10.2 (AK), U6.1
unnamed: D10.1 (KA), R69.2, U6.2 (-)
unnamed: D11.2 (A), D12.1 (K), U10.7
unnamed: D11.1 (K), R70.1, R72.2, U10.6 (-)
unnamed: D12.2 (A), R70.2, R73.1, R75.1, R76.1
unnamed: J23.T, R68.2
unnamed: J24.T, R74.2
unnamed: J25.T, R79.2
unnamed: R66.2, R68.1, U10.1
unnamed: R71.2, R74.1, U10.8
unnamed: R77.2, R79.1, U10.14
unnamed: J22.T, R67.1, R72.1, R78.1, U6.3 (+)
unnamed: R66.1, R67.2, U10.2 (-)
unnamed: R71.1, R73.2, U10.9 (-)
unnamed: R75.2, R76.2, R77.1, R78.2, U10.13 (-)

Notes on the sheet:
+:Green -:Red

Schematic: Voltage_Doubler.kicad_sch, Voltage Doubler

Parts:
C46: 10p; C_0402_1005Metric; LCSC C32949
D24: LED_Dual_Bidirectional; LED_D3.0mm
J39: IN; AudioJack_PJ301M-12
J40: OUT_x1.25; AudioJack_PJ301M-12
J41: OUT_x1.6; AudioJack_PJ301M-12
J42: OUT_x2; AudioJack_PJ301M-12
R119, R121, R127: 100K; R_0402_1005Metric; LCSC C25741
R120: 150K; R_0402_1005Metric; LCSC C25755
R122, R124: 120K; R_0402_1005Metric; LCSC C25750
R123, R126, R129: 100R; R_0402_1005Metric; LCSC C25076
R125: 75K; R_0402_1005Metric; LCSC C25798
R128: 49.9K; R_0402_1005Metric; LCSC C25897
R130: 1K; R_0402_1005Metric; LCSC C11702
U4, U8, U12: TL074CDR; SOIC-14_3.9x8.7mm_P1.27mm; LCSC C12594

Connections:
GND: J39.S, J39.TN, J40.S, J41.S, J42.S, R130.1, U8.3 (+), U8.5 (+), U12.3 (+), U12.5 (+); also elsewhere on the board
unnamed: C46.2, R119.2, R122.1, R125.1, R128.1, U8.1
unnamed: D24.2 (AK), U4.7
unnamed: D24.1 (KA), R130.2, U4.6 (-)
unnamed: J40.T, R123.2
unnamed: J41.T, R126.2
unnamed: J42.T, R129.2
unnamed: R120.2, R123.1, U8.7
unnamed: R124.2, R126.1, U12.1
unnamed: R127.2, R129.1, U12.7
unnamed: J39.T, R121.1, U4.5 (+)
unnamed: C46.1, R119.1, R121.2, U8.2 (-)
unnamed: R120.1, R122.2, U8.6 (-)
unnamed: R124.1, R125.2, U12.2 (-)
unnamed: R127.1, R128.2, U12.6 (-)

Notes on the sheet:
8V to 10V
5V to 10V
+:Green -:Red
5V to 8V

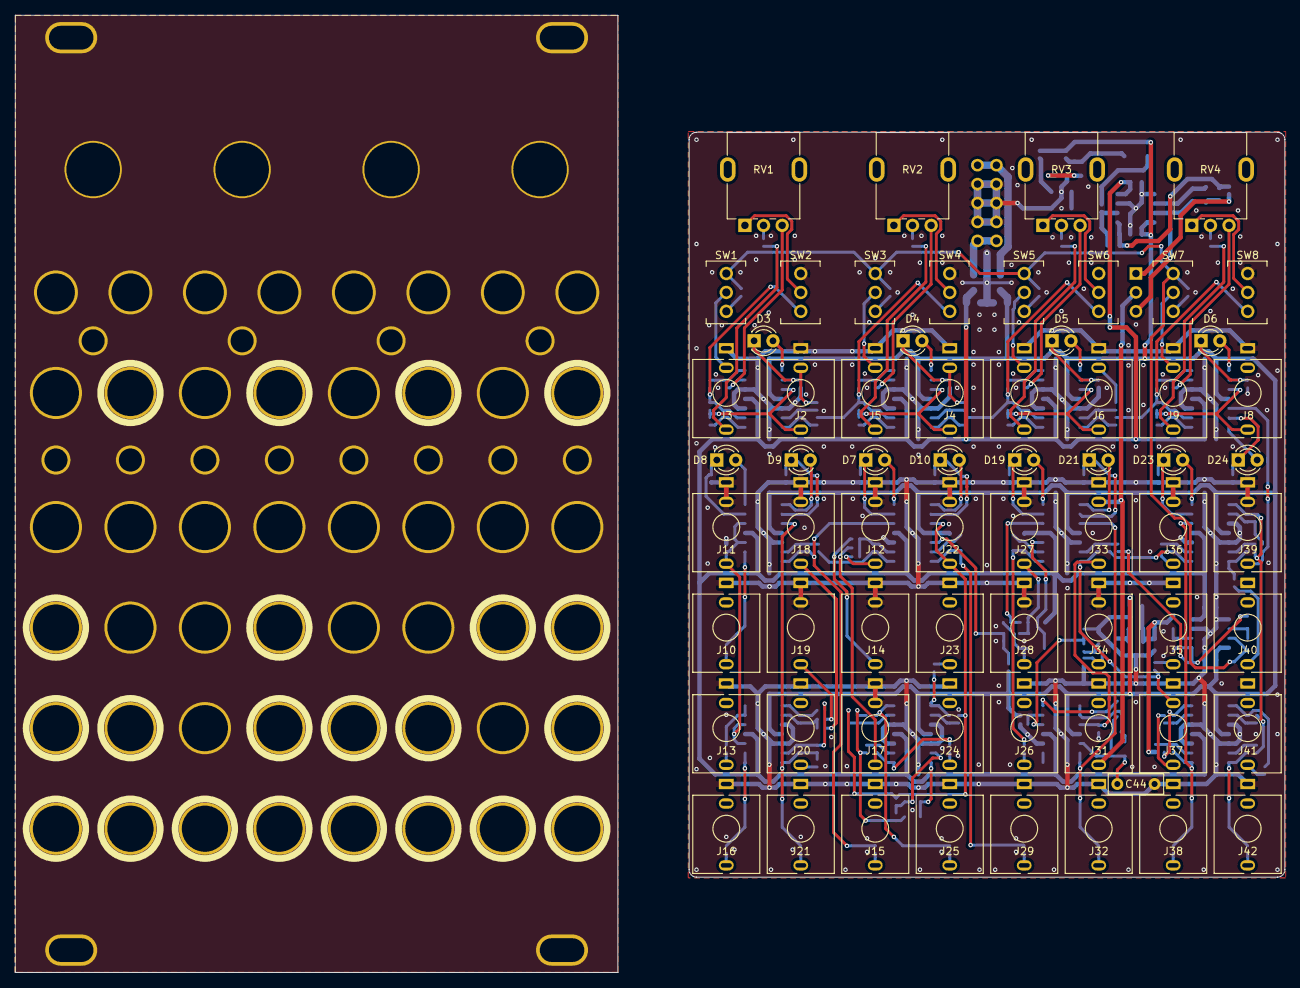
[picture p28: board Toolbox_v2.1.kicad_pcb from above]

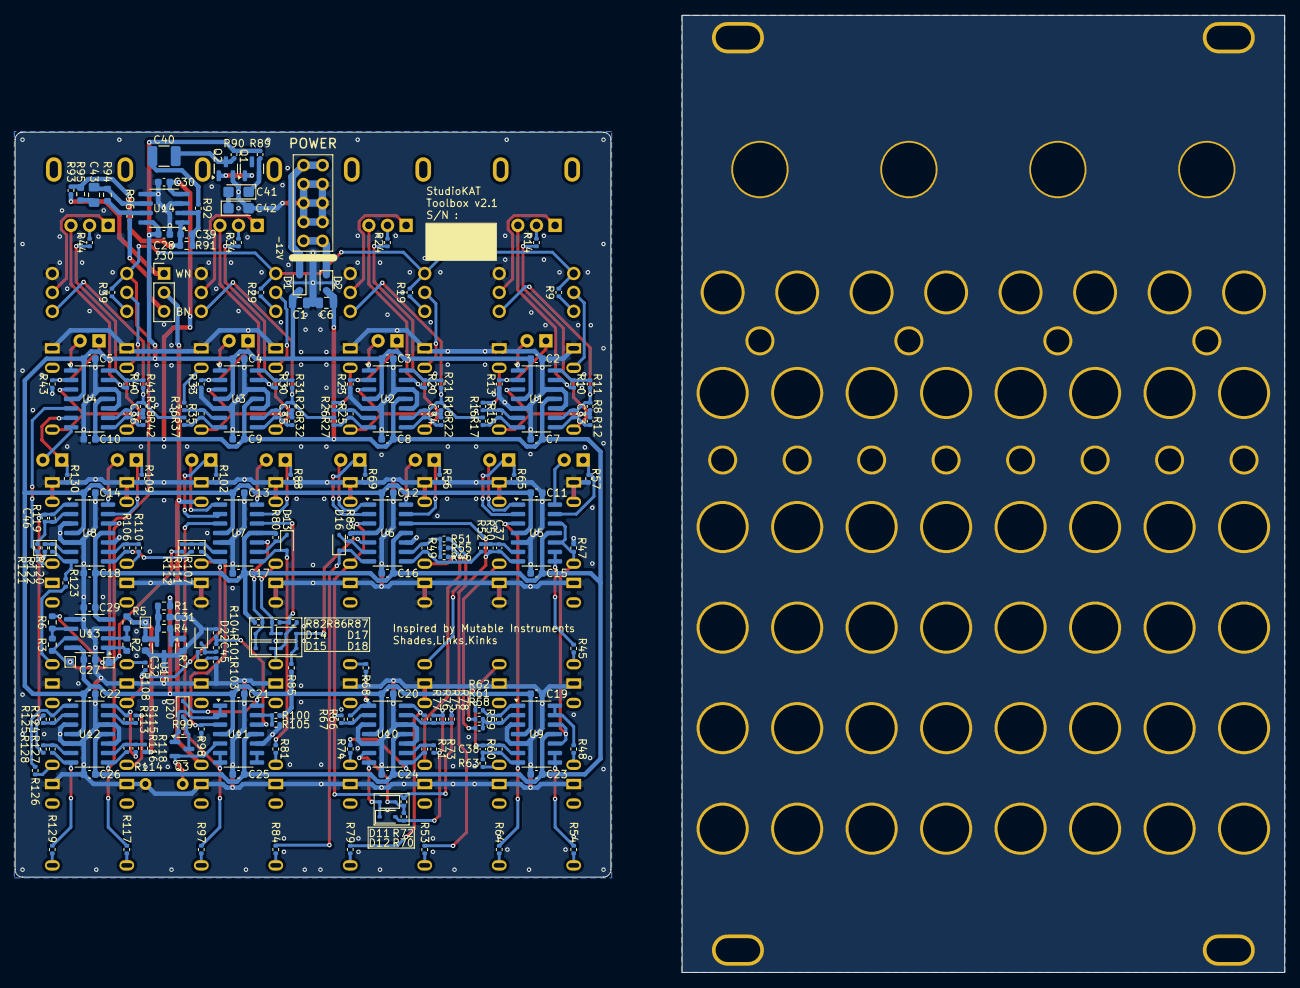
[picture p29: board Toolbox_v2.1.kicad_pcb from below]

Board: 2 copper layers, 80.0 x 100.0 mm, 340 parts (210 on the bottom side), 181 nets.

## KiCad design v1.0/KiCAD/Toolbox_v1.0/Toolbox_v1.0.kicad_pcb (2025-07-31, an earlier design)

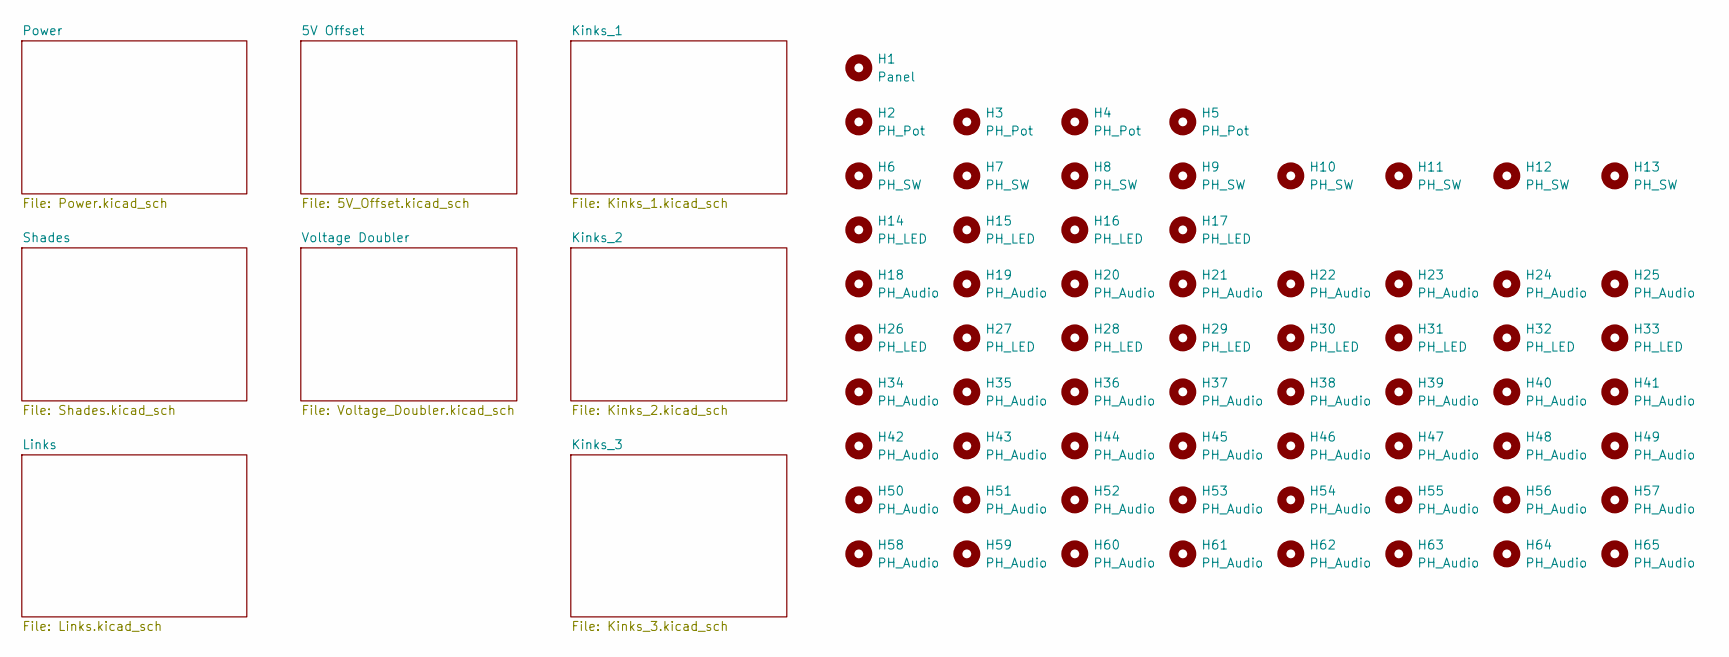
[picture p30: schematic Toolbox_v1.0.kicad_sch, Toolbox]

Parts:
H1: Panel; Panel_16HP
H2, H3, H4, H5: PH_Pot; PH_RK097_15mmKnob_BI_UNI
H6, H7, H8, H9, H10, H11, H12, H13: PH_SW; PH_ToggleSwitch_5.1mm
H14, H15, H16, H17, H26, H27, H28, H29, H30, H31, H32, H33: PH_LED; PH_LED_3.0mm
H18, H19, H20, H21, H22, H23, H24, H25, H34, H35, H36, H37, H38, H39, H40, H41, H42, H43, H44, H45, H46, H47, H48, H49, H50, H51, H52, H53, H54, H55, H56, H57, H58, H59, H60, H61, H62, H63, H64, H65: PH_Audio; PH_AudioJack_3.5mm

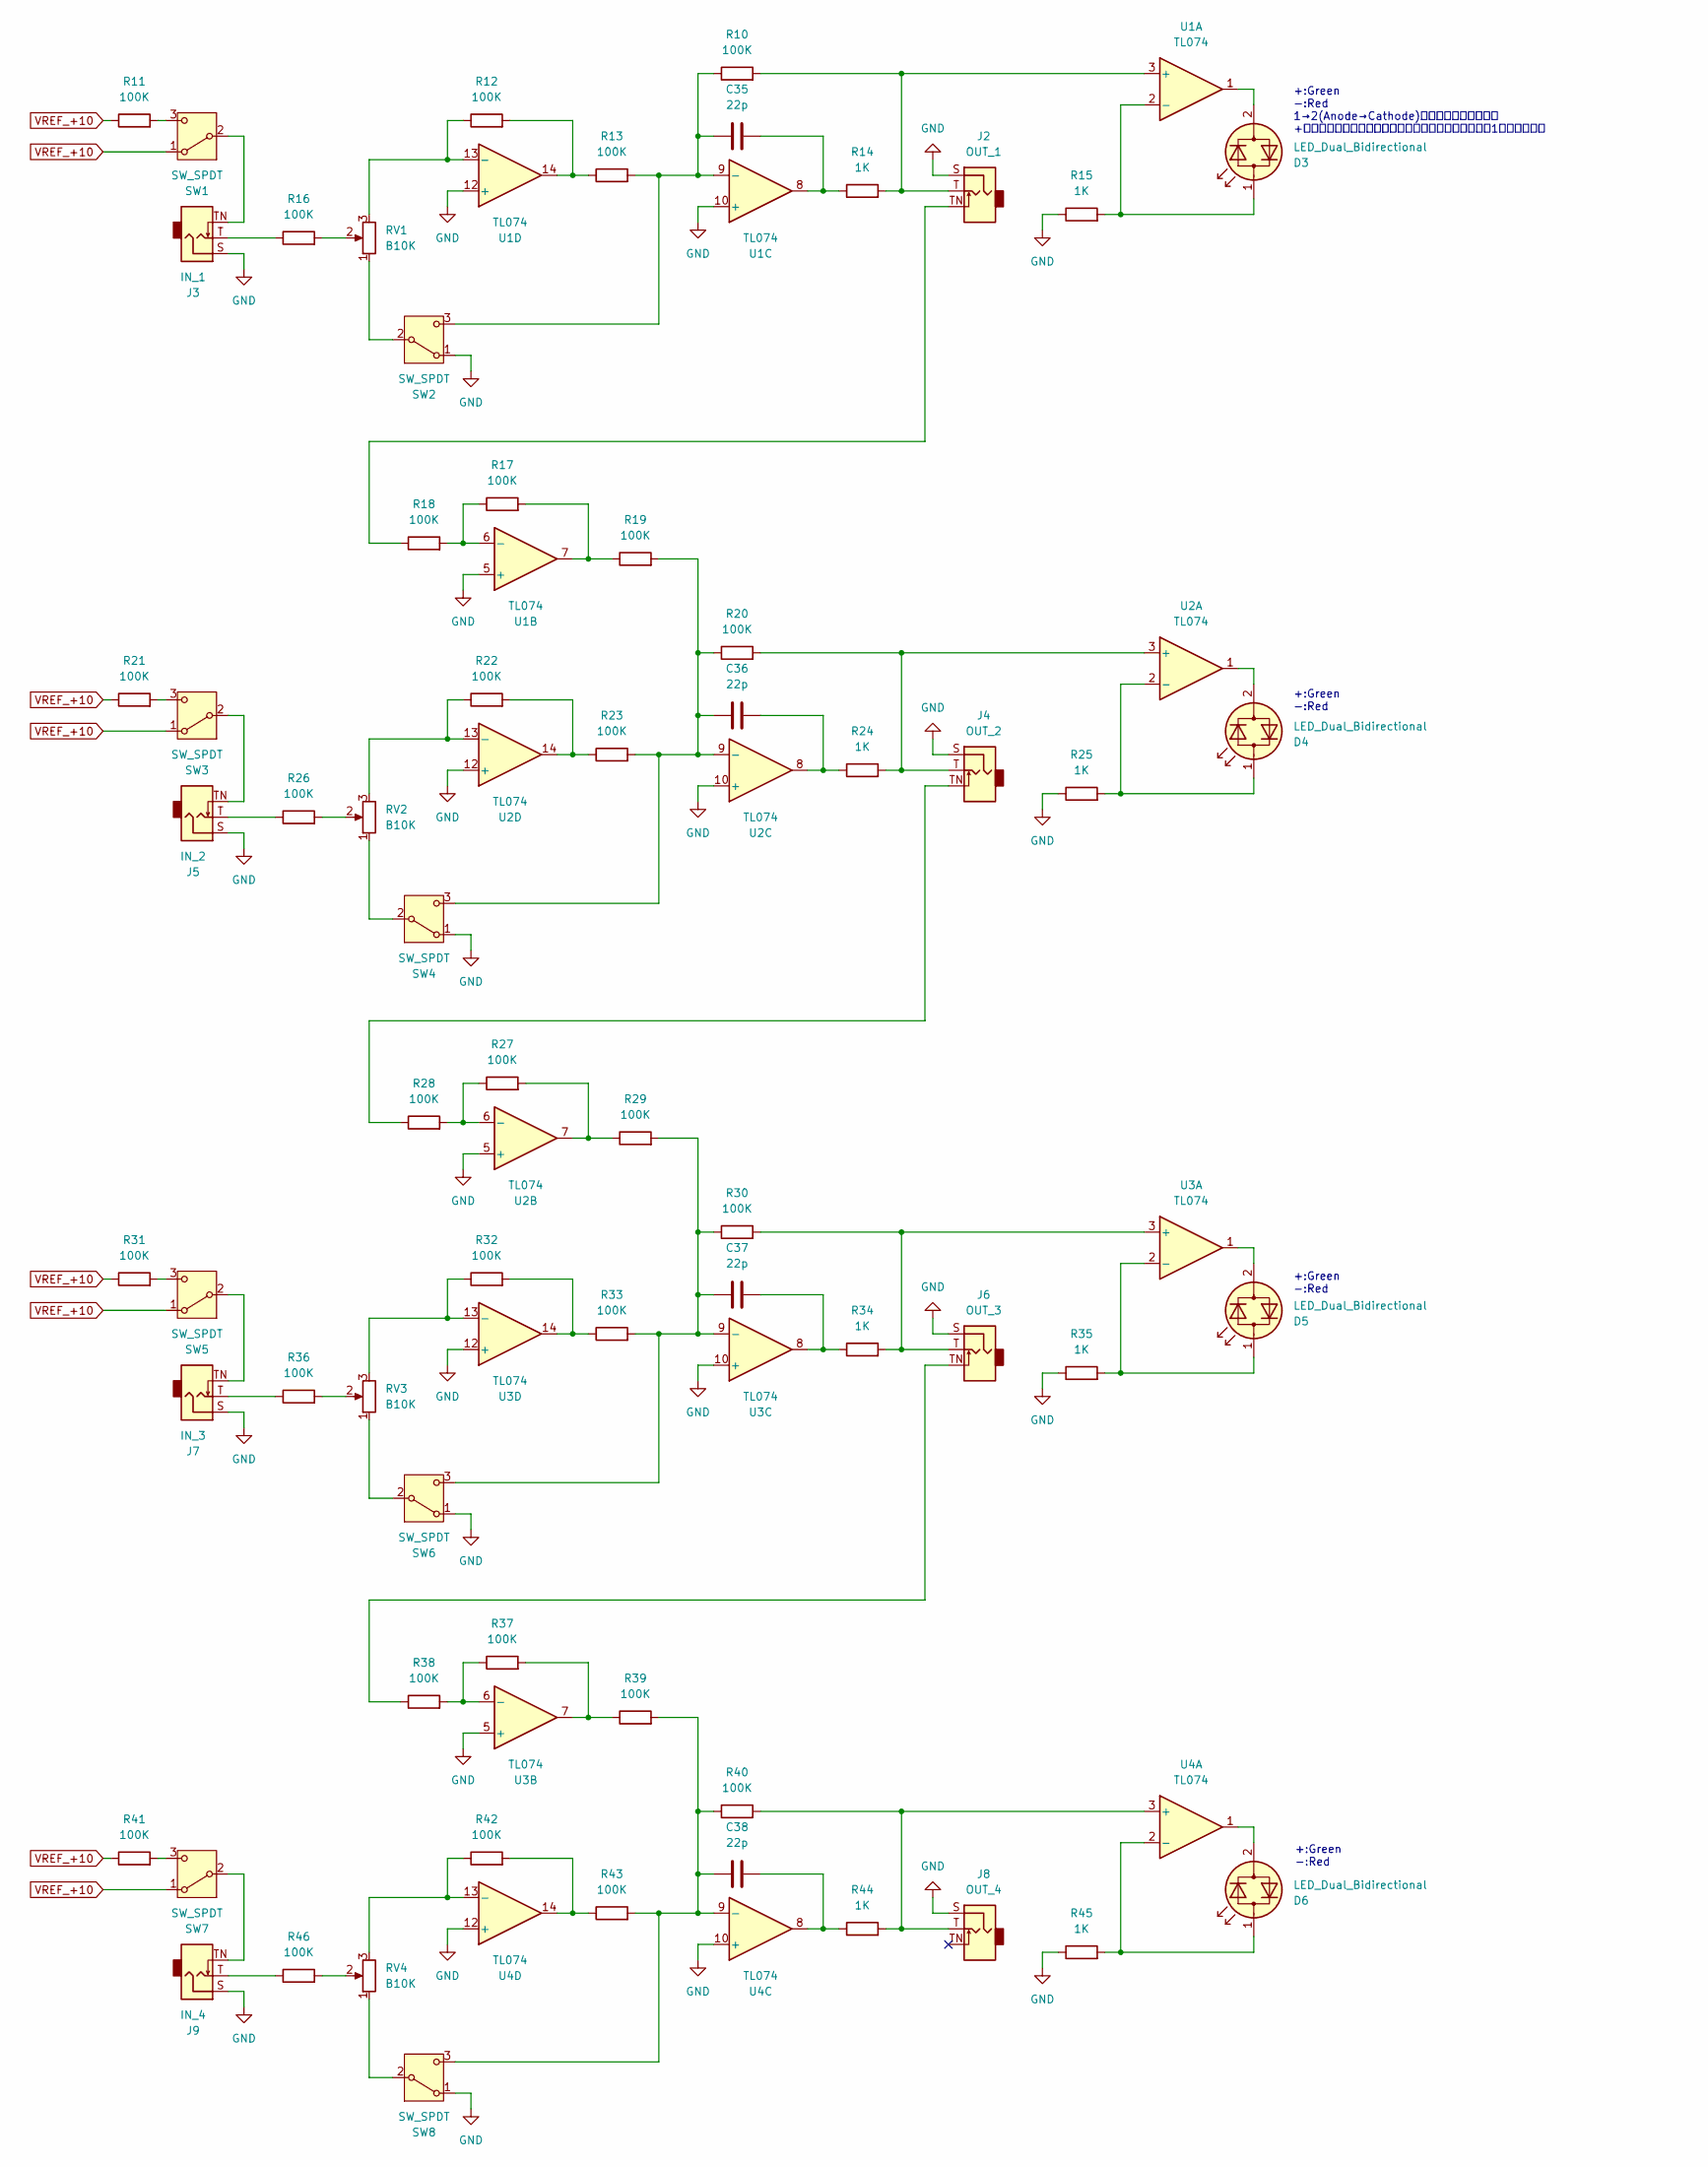
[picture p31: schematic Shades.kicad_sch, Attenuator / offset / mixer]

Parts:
C35, C36, C37, C38: 22p; C_0402_1005Metric; LCSC C1555
D3, D4, D5, D6: LED_Dual_Bidirectional; LED_D3.0mm
J2: OUT_1; AudioJack_PJ301M-12
J3: IN_1; AudioJack_PJ301M-12
J4: OUT_2; AudioJack_PJ301M-12
J5: IN_2; AudioJack_PJ301M-12
J6: OUT_3; AudioJack_PJ301M-12
J7: IN_3; AudioJack_PJ301M-12
J8: OUT_4; AudioJack_PJ301M-12
J9: IN_4; AudioJack_PJ301M-12
R10, R11, R12, R13, R16, R17, R18, R19, R20, R21, R22, R23, R26, R27, R28, R29, R30, R31, R32, R33, R36, R37, R38, R39, R40, R41, R42, R43, R46: 100K; R_0402_1005Metric; LCSC C25741
R14, R15, R24, R25, R34, R35, R44, R45: 1K; R_0402_1005Metric; LCSC C11702
RV1, RV2, RV3, RV4: B10K; Potentiometer_RV09
SW1, SW2, SW3, SW4, SW5, SW6, SW7, SW8: SW_SPDT; ToggleSwitch_2MS1-T2-B4-M2-Q-E-S
U1, U2, U3, U4: TL074; TSSOP-14_4.4x5mm_P0.65mm; LCSC C4370424

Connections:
GND: J2.S, J3.S, J4.S, J5.S, J6.S, J7.S, J8.S, J9.S, R15.1, R25.1, R35.1, R45.1, SW2.1 (A), SW4.1 (A), SW6.1 (A), SW8.1 (A), U1.5 (+), U1.10 (+), U1.12 (+), U2.5 (+), U2.10 (+), U2.12 (+), U3.5 (+), U3.10 (+), U3.12 (+), U4.10 (+), U4.12 (+); also elsewhere on the board
unnamed: C35.2, R14.1, U1.8
unnamed: C36.2, R24.1, U2.8
unnamed: C37.2, R34.1, U3.8
unnamed: C38.2, R44.1, U4.8
unnamed: D3.2 (AK), U1.1
unnamed: D3.1 (KA), R15.2, U1.2 (-)
unnamed: D4.2 (AK), U2.1
unnamed: D4.1 (KA), R25.2, U2.2 (-)
unnamed: D5.2 (AK), U3.1
unnamed: D5.1 (KA), R35.2, U3.2 (-)
unnamed: D6.2 (AK), U4.1
unnamed: D6.1 (KA), R45.2, U4.2 (-)
unnamed: J2.TN, R18.1
unnamed: J3.T, R16.1
unnamed: J4.TN, R28.1
unnamed: J5.T, R26.1
unnamed: J6.TN, R38.1
unnamed: J7.T, R36.1
unnamed: J9.T, R46.1
unnamed: R12.2, R13.1, U1.14
unnamed: R16.2, RV1.2
unnamed: R17.2, R19.1, U1.7
unnamed: R22.2, R23.1, U2.14
unnamed: R26.2, RV2.2
unnamed: R27.2, R29.1, U2.7
unnamed: R32.2, R33.1, U3.14
unnamed: R36.2, RV3.2
unnamed: R37.2, R39.1, U3.7
unnamed: R42.2, R43.1, U4.14
unnamed: R46.2, RV4.2
unnamed: J3.TN, SW1.2 (B)
unnamed: R11.2, SW1.3 (C)
unnamed: RV1.1, SW2.2 (B)
unnamed: C35.1, R10.1, R13.2, SW2.3 (C), U1.9 (-)
unnamed: J5.TN, SW3.2 (B)
unnamed: R21.2, SW3.3 (C)
unnamed: RV2.1, SW4.2 (B)
unnamed: C36.1, R19.2, R20.1, R23.2, SW4.3 (C), U2.9 (-)
unnamed: J7.TN, SW5.2 (B)
unnamed: R31.2, SW5.3 (C)
unnamed: RV3.1, SW6.2 (B)
unnamed: C37.1, R29.2, R30.1, R33.2, SW6.3 (C), U3.9 (-)
unnamed: J9.TN, SW7.2 (B)
unnamed: R41.2, SW7.3 (C)
unnamed: RV4.1, SW8.2 (B)
unnamed: C38.1, R39.2, R40.1, R43.2, SW8.3 (C), U4.9 (-)
unnamed: J2.T, R10.2, R14.2, U1.3 (+)
unnamed: R17.1, R18.2, U1.6 (-)
unnamed: R12.1, RV1.3, U1.13 (-)
unnamed: J4.T, R20.2, R24.2, U2.3 (+)
unnamed: R27.1, R28.2, U2.6 (-)
unnamed: R22.1, RV2.3, U2.13 (-)
unnamed: J6.T, R30.2, R34.2, U3.3 (+)
unnamed: R37.1, R38.2, U3.6 (-)
unnamed: R32.1, RV3.3, U3.13 (-)
unnamed: J8.T, R40.2, R44.2, U4.3 (+)
unnamed: R42.1, RV4.3, U4.13 (-)
VREF_+10: R11.1, R21.1, R31.1, R41.1, SW1.1 (A), SW3.1 (A), SW5.1 (A), SW7.1 (A); also elsewhere on the board

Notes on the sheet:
+:Green -:Red
+:Green -:Red 1→2(Anode→Cathode)順方向で赤点灯なので +で緑にしたい場合、足が短いカソード側をオペアンプ1番ピンに繋ぐ


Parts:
C1, C2: 22uF; C_0805_2012Metric; LCSC C45783
C3, C4, C5, C6, C7, C8, C9, C10, C11, C12, C13, C14, C15, C16, C17, C18, C19, C20, C22, C23, C24, C25, C27, C28, C29, C30, C31, C32, C33, C34: 100nF; C_0402_1005Metric; LCSC C1525
C21, C26: 10u; CP_EIA-3216-18_Kemet-A; LCSC C7171
D1, D2: 1N5819WS; D_SOD-323; LCSC C64886
J1: POWER; PinHeader_2x05_2.54mm_Europower
R1, R4, R9: 1K; R_0402_1005Metric; LCSC C11702
R2: 100K; R_0402_1005Metric; LCSC C25741
R3: 33K; R_0402_1005Metric; LCSC C25779
R5, R6, R7, R8: 10K; R_0402_1005Metric; LCSC C25744
TP1: +10V_TP; TestPoint_Pad_1.0x1.0mm
TP2: +5V_TP; TestPoint_Pad_1.0x1.0mm
TP3: -5V_TP; TestPoint_Pad_1.0x1.0mm
U1, U2, U3, U4, U6, U9, U10, U11, U12: TL074; TSSOP-14_4.4x5mm_P0.65mm; LCSC C4370424
U5, U7, U8: TL074; TSSOP-14_4.4x5mm_P0.65mm
U13, U14, U15: CJ431; SOT-23; LCSC C3113

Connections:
+12V: C1.1, C3.1, C4.1, C5.1, C6.1, C11.1, C12.1, C13.1, C14.1, C19.1, C20.1, C21.1, C22.1, C23.1, D1.1 (K), R1.1, R4.1, U1.4 (V+), U2.4 (V+), U3.4 (V+), U4.4 (V+), U5.4 (V+), U6.4 (V+), U7.4 (V+), U8.4 (V+), U9.4 (V+), U10.4 (V+), U11.4 (V+), U12.4 (V+); also elsewhere on the board
-12V: C2.2, C7.2, C8.2, C9.2, C10.2, C15.2, C16.2, C17.2, C18.2, C24.2, C25.2, C26.2, C27.2, C28.2, D2.2 (A), R9.1, U1.11 (V-), U2.11 (V-), U3.11 (V-), U4.11 (V-), U5.11 (V-), U6.11 (V-), U7.11 (V-), U8.11 (V-), U9.11 (V-), U10.11 (V-), U11.11 (V-), U12.11 (V-); also elsewhere on the board
GND: C1.2, C2.1, C3.2, C4.2, C5.2, C6.2, C7.1, C8.1, C9.1, C10.1, C11.2, C12.2, C13.2, C14.2, C15.1, C16.1, C17.1, C18.1, C19.2, C20.2, C21.2, C22.2, C23.2, C24.1, C25.1, C26.1, C27.1, C28.1, C29.2, C30.2, C31.2, C32.2, C33.1, C34.1, J1.3, J1.4, J1.5, J1.6, J1.7, J1.8, R3.2, R6.2, R7.1, U13.3 (A), U14.3 (A), U15.2 (K); also elsewhere on the board
unnamed: D1.2 (A), J1.1, J1.2
unnamed: D2.1 (K), J1.9, J1.10
unnamed: R2.2, R3.1, U13.1 (REF)
unnamed: R5.2, R6.1, U14.1 (REF)
unnamed: R7.2, R8.1, U15.1 (REF)
VREF_+5: C31.1, C32.1, R4.2, R5.1, TP2.1, U14.2 (K); also elsewhere on the board
VREF_+10: C29.1, C30.1, R1.2, R2.1, TP1.1, U13.2 (K); also elsewhere on the board
VREF_-5: C33.2, C34.2, R8.2, R9.2, TP3.1, U15.3 (A); also elsewhere on the board


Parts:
C41: 100nF; C_Rect_L7.2mm_W2.5mm_P5.00mm_FKS2_FKP2_MKS2_MKP2
C42, C43: 10u; CP_EIA-3216-18_Kemet-A; LCSC C7171
C44: 10n; C_Rect_L7.2mm_W2.5mm_P5.00mm_FKS2_FKP2_MKS2_MKP2
C45: 100p; C_0402_1005Metric; LCSC C1546
D20, D22: 1N4148WS; D_SOD-323; LCSC C2128
D21: LED_Dual_Bidirectional; LED_D3.0mm
J30: Kinks_OUT_Noise; AudioJack_PJ301M-12
J31: Kinks_OUT_S&H; AudioJack_PJ301M-12
J32: Kinks_S&H_IN; AudioJack_PJ301M-12
J33: Kinks_S&H_TRIG; AudioJack_PJ301M-12
Q1, Q2: MMBT3904; SOT-23; LCSC C20526
Q3: MMBFJ310; SOT-23
R91: 470K; R_0402_1005Metric; LCSC C25790
R92: 4.7K; R_0402_1005Metric; LCSC C25900
R93: 240K; R_0603_1608Metric; LCSC C4197
R94, R102, R103: 100K; R_0402_1005Metric; LCSC C25741
R95, R96: 100R; R_0402_1005Metric; LCSC C25076
R97, R98, R99: 1M; R_0402_1005Metric; LCSC C26083
R100: 1K; R_0402_1005Metric; LCSC C11702
R101, R104: 10K; R_0402_1005Metric; LCSC C25744
U7, U11: TL074; TSSOP-14_4.4x5mm_P0.65mm; LCSC C4370424

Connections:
+12V: R91.1, R92.1, R99.1; also elsewhere on the board
GND: C43.2, C44.2, D22.2 (A), J30.S, J31.S, J32.S, J33.S, J33.TN, Q2.2 (E), R97.2, R100.1, R102.2, R103.2, R104.2, U11.10 (+); also elsewhere on the board
unnamed: C41.2, R94.1
unnamed: C42.2, C43.1
unnamed: C45.1, J33.T, R102.1
unnamed: D20.2 (A), Q3.3 (G), R98.2
unnamed: D20.1 (K), U11.14
unnamed: D21.2 (AK), U7.1
unnamed: D21.1 (KA), R100.2, U7.2 (-)
unnamed: C45.2, D22.1 (K), R101.1
unnamed: J30.T, J32.TN, R95.2
unnamed: J31.T, R96.2
unnamed: Q1.1 (B), Q2.1 (B)
unnamed: C42.1, Q1.2 (E), R91.2
unnamed: C41.1, Q2.3 (C), R92.2
unnamed: Q3.1 (D), R98.1, U11.1, U11.2 (-)
unnamed: C44.1, Q3.2 (S), U11.5 (+)
unnamed: R93.2, R95.1, U11.8
unnamed: J32.T, R97.1, U11.3 (+)
unnamed: R96.1, U7.3 (+), U11.6 (-), U11.7
unnamed: R93.1, R94.2, U11.9 (-)
unnamed: R101.2, R103.1, U11.12 (+)
unnamed: R99.2, R104.1, U11.13 (-)

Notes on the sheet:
- 22pF並列 -
ノイズ周りだけオペアンプ分けたほうがいいかも rev2で対応予定
Flilm cap
Tantalum 5uF
+:Green -:Red


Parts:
D13, D14, D15, D16, D17, D18: 1N4148WS; D_SOD-323; LCSC C2128
D19: LED_Dual_Bidirectional; LED_D3.0mm
J26: Kinks_OUT_MAX; AudioJack_PJ301M-12
J27: Kinks_IN_A; AudioJack_PJ301M-12
J28: Kinks_IN_B; AudioJack_PJ301M-12
J29: Kinks_OUT_MIN; AudioJack_PJ301M-12
R82, R84, R85, R87: 220K; R_0402_1005Metric; LCSC C25767
R83, R86: 100R; R_0402_1005Metric; LCSC C25076
R88, R89: 1M; R_0402_1005Metric; LCSC C26083
R90: 1K; R_0402_1005Metric; LCSC C11702
U6, U7: TL074; TSSOP-14_4.4x5mm_P0.65mm; LCSC C4370424

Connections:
+12V: R85.1, R87.2; also elsewhere on the board
-12V: R82.1, R84.2; also elsewhere on the board
GND: J26.S, J27.S, J27.TN, J28.S, J28.TN, J29.S, R90.1; also elsewhere on the board
unnamed: D13.2 (A), R83.1, U7.8
unnamed: D13.1 (K), R82.2, U7.9 (-)
unnamed: D14.2 (A), D17.1 (K), J27.T, R88.1
unnamed: D14.1 (K), D15.1 (K), R84.1, U7.10 (+)
unnamed: D15.2 (A), D18.1 (K), J28.T, R89.1
unnamed: D16.2 (A), R85.2, U6.6 (-)
unnamed: D16.1 (K), R86.1, U6.7
unnamed: D17.2 (A), D18.2 (A), R87.1, U6.5 (+)
unnamed: D19.2 (AK), U7.14
unnamed: D19.1 (KA), R90.2, U7.13 (-)
unnamed: J26.T, R83.2
unnamed: J29.T, R86.2
unnamed: R88.2, R89.2, U7.12 (+)

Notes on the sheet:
+:Green -:Red

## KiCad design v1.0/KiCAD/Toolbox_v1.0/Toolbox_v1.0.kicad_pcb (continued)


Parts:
C39, C40: 10p; C_0402_1005Metric; LCSC C32949
D7, D8, D9: LED_Dual_Bidirectional; LED_D3.0mm
J10: Links_1to3_OUT1; AudioJack_PJ301M-12
J11: Links_1to3_IN; AudioJack_PJ301M-12
J12: Links_1to3_OUT2; AudioJack_PJ301M-12
J13: Links_1to3_OUT3; AudioJack_PJ301M-12
J14: Links_2to2_IN1; AudioJack_PJ301M-12
J15: Links_2to2_IN2; AudioJack_PJ301M-12
J16: Links_2to2_OUT1; AudioJack_PJ301M-12
J17: Links_2to2_OUT2; AudioJack_PJ301M-12
J18: Links_3to1_IN1; AudioJack_PJ301M-12
J19: Links_3to1_IN2; AudioJack_PJ301M-12
J20: Links_3to1_OUT; AudioJack_PJ301M-12
J21: Links_3to1_IN3; AudioJack_PJ301M-12
R47, R49, R50, R57, R58, R65: 100R; R_0402_1005Metric; LCSC C25076
R48: 10M; R_0402_1005Metric; LCSC C26082
R51, R59, R67: 1K; R_0402_1005Metric; LCSC C11702
R52, R53, R54, R55, R56, R60, R62, R63, R64, R66: 100K; R_0402_1005Metric; LCSC C25741
R61: 33K; R_0402_1005Metric; LCSC C25779
U5, U6, U9: TL074; TSSOP-14_4.4x5mm_P0.65mm; LCSC C4370424

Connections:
GND: J10.S, J11.S, J11.TN, J12.S, J13.S, J14.S, J14.TN, J15.S, J15.TN, J16.S, J17.S, J18.S, J18.TN, J19.S, J19.TN, J20.S, J21.S, J21.TN, R48.2, R51.1, R59.1, R67.1, U5.5 (+), U6.10 (+), U9.3 (+), U9.5 (+); also elsewhere on the board
unnamed: D7.2 (AK), U5.14
unnamed: D7.1 (KA), R51.2, U5.13 (-)
unnamed: D8.2 (AK), U5.1
unnamed: D8.1 (KA), R59.2, U5.2 (-)
unnamed: D9.2 (AK), U6.14
unnamed: D9.1 (KA), R67.2, U6.13 (-)
unnamed: J10.T, R47.2
unnamed: J12.T, R49.2
unnamed: J13.T, R50.2
unnamed: J14.T, R52.1
unnamed: J15.T, R55.1
unnamed: J16.T, R57.2
unnamed: J17.T, R58.2
unnamed: J18.T, R60.1
unnamed: J19.T, R63.1
unnamed: J20.T, R65.2
unnamed: J21.T, R66.1
unnamed: R53.2, R56.1, U9.1
unnamed: R61.2, R64.1, U6.8
unnamed: C39.2, R54.2, R57.1, R58.1, U5.3 (+), U9.7
unnamed: C40.1, R62.1, R64.2, U5.6 (-)
unnamed: J11.T, R48.1, U5.10 (+), U5.12 (+), U9.10 (+), U9.12 (+)
unnamed: R47.1, U5.8, U5.9 (-)
unnamed: R60.2, R61.1, R63.2, R66.2, U6.9 (-)
unnamed: C40.2, R62.2, R65.1, U5.7, U6.12 (+)
unnamed: R52.2, R53.1, R55.2, U9.2 (-)
unnamed: C39.1, R54.1, R56.2, U9.6 (-)
unnamed: R50.1, U9.8, U9.9 (-)
unnamed: R49.1, U9.13 (-), U9.14

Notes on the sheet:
+:Green -:Red


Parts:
D23: LED_Dual_Bidirectional; LED_D3.0mm
J34: OUT_+10V; AudioJack_PJ301M-12
J35: IN_±5V; AudioJack_PJ301M-12
J36: IN_+10V; AudioJack_PJ301M-12
J37: OUT_±5V; AudioJack_PJ301M-12
R105, R106, R108, R109, R110, R111, R112, R113, R114, R116: 100K; R_0402_1005Metric; LCSC C25741
R107, R115: 100R; R_0402_1005Metric; LCSC C25076
R117: 1K; R_0402_1005Metric; LCSC C11702
U7, U8, U12: TL074; TSSOP-14_4.4x5mm_P0.65mm; LCSC C4370424

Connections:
GND: J34.S, J35.S, J35.TN, J36.S, J37.S, R117.1, U7.5 (+), U8.10 (+), U12.10 (+), U12.12 (+); also elsewhere on the board
unnamed: D23.2 (AK), U8.14
unnamed: D23.1 (KA), R117.2, U8.13 (-)
unnamed: J34.T, R107.2
unnamed: J36.T, R113.1
unnamed: J36.TN, R106.2, R107.1, U7.7
unnamed: J37.T, R115.2
unnamed: R105.2, R109.1, U8.8
unnamed: R111.2, R114.1, U12.14
unnamed: R112.2, R115.1, U12.8
unnamed: R106.1, R109.2, R110.2, U7.6 (-)
unnamed: R105.1, R108.2, U8.9 (-)
unnamed: J35.T, R108.1, U8.12 (+)
unnamed: R112.1, R114.2, R116.2, U12.9 (-)
unnamed: R111.1, R113.2, U12.13 (-)
VREF_+5: R116.1; also elsewhere on the board
VREF_-5: R110.1; also elsewhere on the board

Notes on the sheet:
0~+10V
rev2でOUT側に変更予定
-10V~0V
±5V
+:Green -:Red
∓5V


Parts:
D10: LED_Dual_Bidirectional; LED_D3.0mm
D11, D12: 1N4148WS; D_SOD-323; LCSC C2128
J22: Kinks_IN; AudioJack_PJ301M-12
J23: Kinks_OUT_INV; AudioJack_PJ301M-12
J24: Kinks_OUT_HW; AudioJack_PJ301M-12
J25: Kinks_OUT_FW; AudioJack_PJ301M-12
R68, R69, R73, R74, R79, R80: 200K; R_0402_1005Metric; LCSC C25764
R70, R76, R81: 100R; R_0402_1005Metric; LCSC C25076
R71: 1K; R_0402_1005Metric; LCSC C11702
R72, R75, R77, R78: 100K; R_0402_1005Metric; LCSC C25741
U6, U10: TL074; TSSOP-14_4.4x5mm_P0.65mm; LCSC C4370424

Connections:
GND: J22.S, J22.TN, J23.S, J24.S, J25.S, R71.1, U10.3 (+), U10.5 (+), U10.10 (+), U10.12 (+); also elsewhere on the board
unnamed: D10.2 (AK), U6.1
unnamed: D10.1 (KA), R71.2, U6.2 (-)
unnamed: D11.2 (A), D12.1 (K), U10.7
unnamed: D11.1 (K), R72.1, R74.2, U10.6 (-)
unnamed: D12.2 (A), R72.2, R75.1, R77.1, R78.1
unnamed: J23.T, R70.2
unnamed: J24.T, R76.2
unnamed: J25.T, R81.2
unnamed: R68.2, R70.1, U10.1
unnamed: R73.2, R76.1, U10.8
unnamed: R79.2, R81.1, U10.14
unnamed: J22.T, R69.1, R74.1, R80.1, U6.3 (+)
unnamed: R68.1, R69.2, U10.2 (-)
unnamed: R73.1, R75.2, U10.9 (-)
unnamed: R77.2, R78.2, R79.1, R80.2, U10.13 (-)

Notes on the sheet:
+:Green -:Red

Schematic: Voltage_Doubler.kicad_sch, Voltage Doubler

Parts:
C46: 10p; C_0402_1005Metric; LCSC C32949
D24: LED_Dual_Bidirectional; LED_D3.0mm
J38: IN; AudioJack_PJ301M-12
J39: OUT_x1.25; AudioJack_PJ301M-12
J40: OUT_x1.6; AudioJack_PJ301M-12
J41: OUT_x2; AudioJack_PJ301M-12
R118, R120, R126: 100K; R_0402_1005Metric; LCSC C25741
R119: 150K; R_0402_1005Metric; LCSC C25755
R121, R123: 120K; R_0402_1005Metric; LCSC C25750
R122, R125, R128: 100R; R_0402_1005Metric; LCSC C25076
R124: 75K; R_0402_1005Metric; LCSC C25798
R127: 49.9K; R_0402_1005Metric; LCSC C25897
R129: 1K; R_0402_1005Metric; LCSC C11702
U4, U8, U12: TL074; TSSOP-14_4.4x5mm_P0.65mm; LCSC C4370424

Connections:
GND: J38.S, J38.TN, J39.S, J40.S, J41.S, R129.1, U8.3 (+), U8.5 (+), U12.3 (+), U12.5 (+); also elsewhere on the board
unnamed: C46.2, R118.2, R121.1, R124.1, R127.1, U8.1
unnamed: D24.2 (AK), U4.7
unnamed: D24.1 (KA), R129.2, U4.6 (-)
unnamed: J39.T, R122.2
unnamed: J40.T, R125.2
unnamed: J41.T, R128.2
unnamed: R119.2, R122.1, U8.7
unnamed: R123.2, R125.1, U12.1
unnamed: R126.2, R128.1, U12.7
unnamed: J38.T, R120.1, U4.5 (+)
unnamed: C46.1, R118.1, R120.2, U8.2 (-)
unnamed: R119.1, R121.2, U8.6 (-)
unnamed: R123.1, R124.2, U12.2 (-)
unnamed: R126.1, R127.2, U12.6 (-)

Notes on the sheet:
8V to 10V
5V to 10V
+:Green -:Red
5V to 8V



Board: 2 copper layers, 80.0 x 100.0 mm, 338 parts (207 on the bottom side), 174 nets.

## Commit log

2025-04-24 マニュアル追加
2025-04-30 消費電流を実測値に変更
2025-05-22 フォルダ構成変更
    [bom.csv, positions.csv]
2025-05-23 KiCADプロジェクト追加
    [5V_Offset.kicad_sch, Kinks_1.kicad_sch, Kinks_2.kicad_sch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]
2025-05-28 画像差し替え
2025-06-08 ディレクトリ構成変更
    [bom.csv, positions.csv]
2025-07-31 v2.1 Update
    [5V_Offset.kicad_sch, Kinks_1.kicad_sch, Kinks_2.kicad_sch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]
2026-05-06 R91 定数変更 240K→200K
    [5V_Offset.kicad_sch, Kinks_1.kicad_sch, Kinks_2.kicad_sch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]
